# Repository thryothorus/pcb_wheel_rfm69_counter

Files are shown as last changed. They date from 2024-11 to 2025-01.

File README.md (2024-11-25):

# Wheel Counter, Battery Powered, RFM69 at 433MHz

## Objective
- Monitor how much critters are running on their wheels, at [The Creature Conservancy](http://www.thecreatureconservancy.org/).  Physical activity could correlate with health
- Create a wireless, battery powered, sensing network for additional sensors in the future

## Features
- NFC antenna for quick reading/changing of metadata (i.e. setting the animal name for transmission)
- RTC (Real Time Clock)
- N-MOSFET polarity protection
- Several debug switches
- TagConnect interface
  
### Schematic
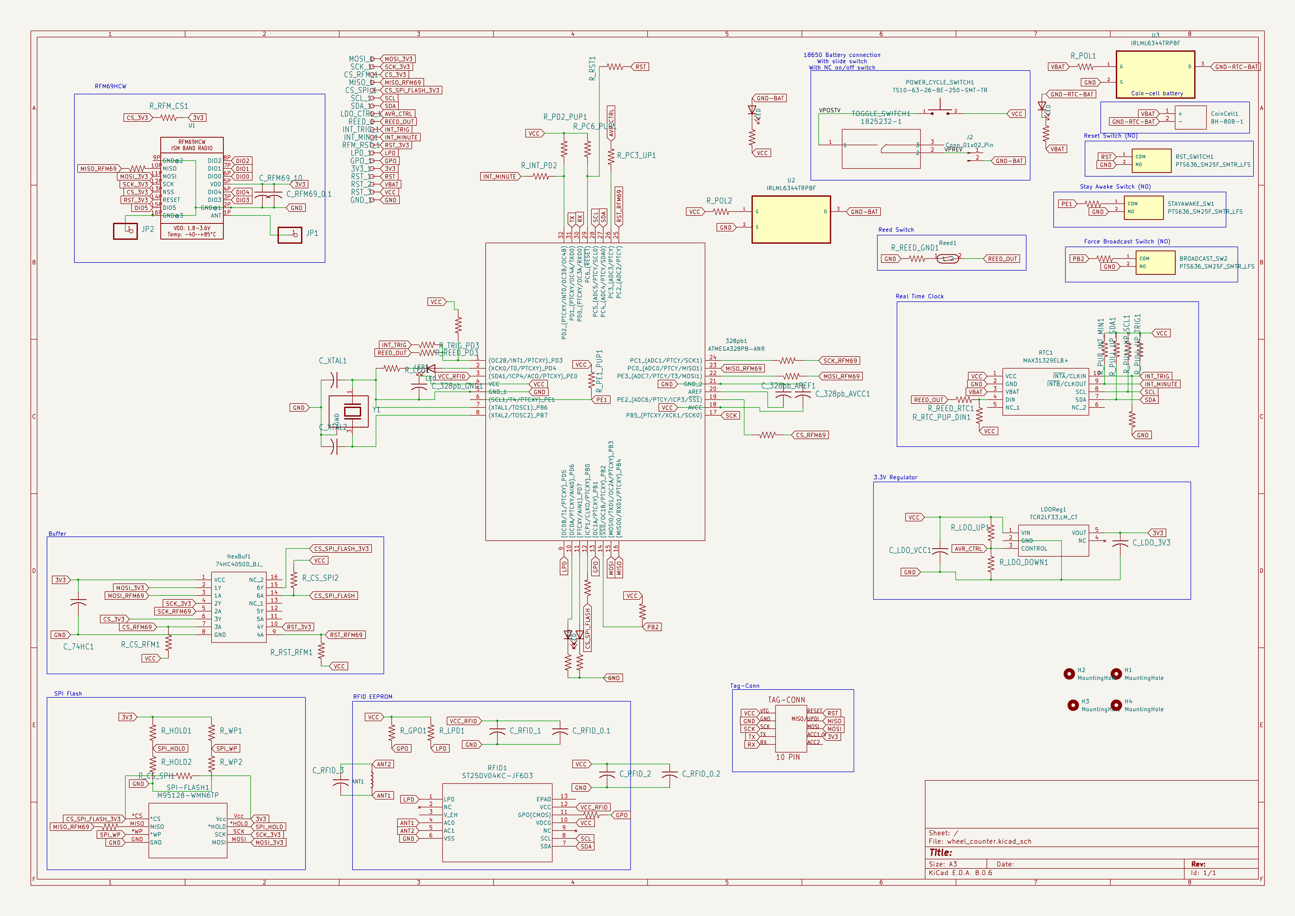
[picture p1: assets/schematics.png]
Schematic

### PCB
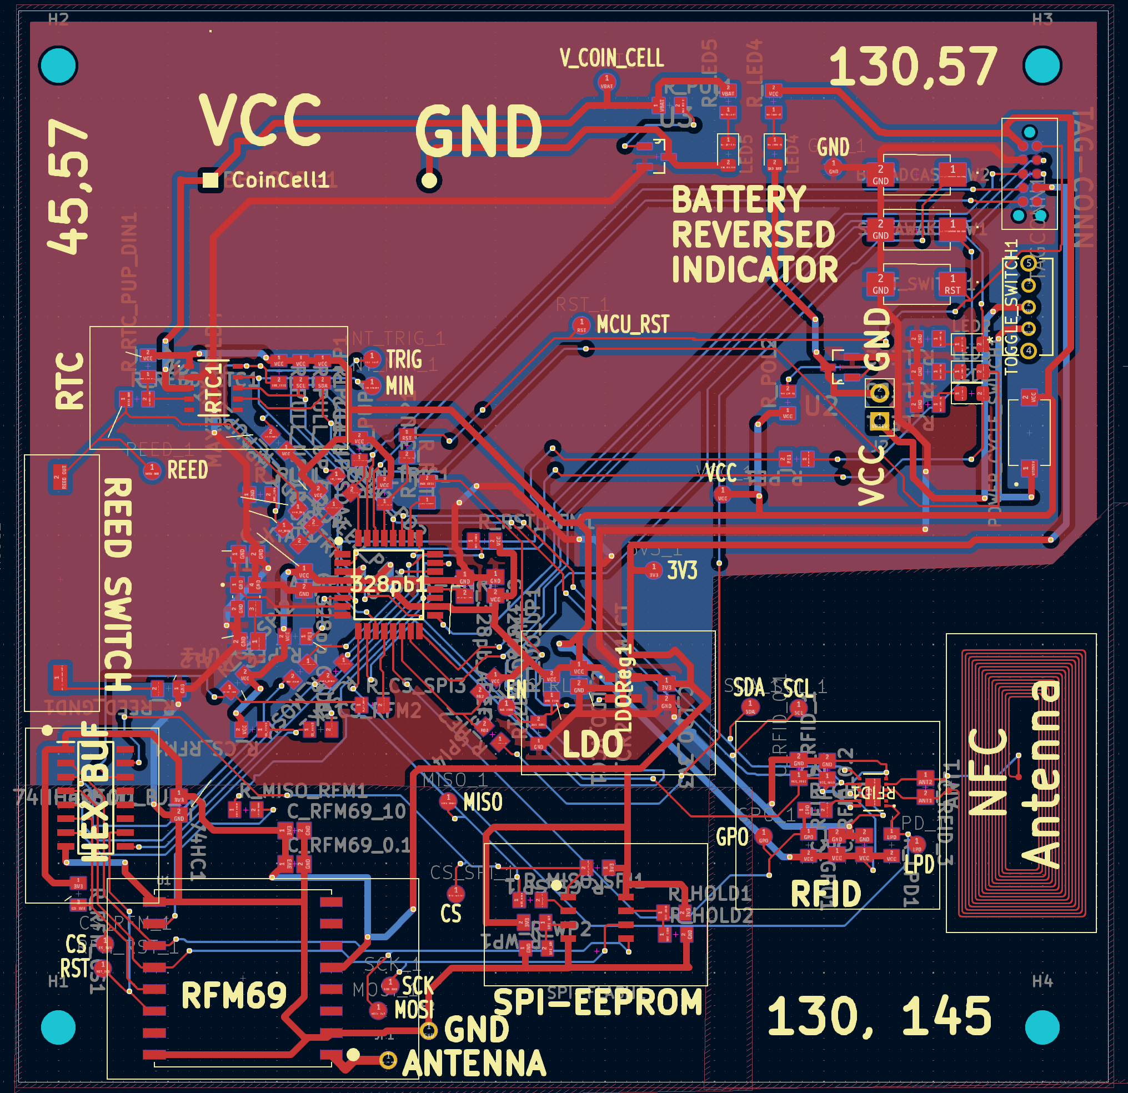
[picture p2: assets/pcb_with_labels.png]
PCB


## What's Next
- Populating PCB
- Writing code

## License: GPLv3 where not covered by other licenses

## Resources
NFC antenna design taken from [Sparkfun's implementation](https://www.sparkfun.com/products/21274)
Footprints from various sources online, including Sparkfun and Adafruit

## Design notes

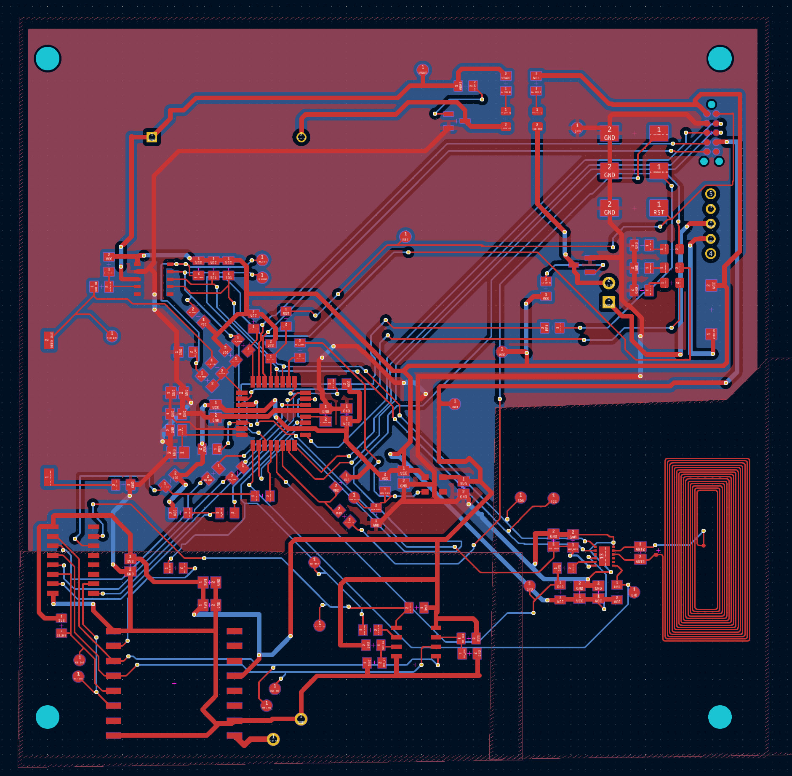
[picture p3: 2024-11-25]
pcb/assets/pcb_copper.png

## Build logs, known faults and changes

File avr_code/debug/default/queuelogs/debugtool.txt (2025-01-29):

1393 1738098146186 GEN4_TO_CONTROLLER_LOG:GEN4_CONNECT_INT_LOG Pre:SetLEDBrightness
1393 1738098146186 GEN4_TO_CONTROLLER_LOG:GEN4_CONNECT_INT_LOG Payload
1393 1738098146186 GEN4_TO_CONTROLLER_LOG:GEN4_CONNECT_INT_LOG 5
1393 1738098146186 GEN4_TO_CONTROLLER_LOG:GEN4_CONNECT_INT_LOG Payload End
1393 1738098146186 GEN4_TO_CONTROLLER_LOG:GEN4_CONNECT_INT_LOG Post:SetLEDBrightness
1393 1738098146186 GEN4_TO_CONTROLLER_LOG:GEN4_CONNECT_INT_LOG Return Value
1393 1738098146186 GEN4_TO_CONTROLLER_LOG:GEN4_CONNECT_INT_LOG none
1393 1738098146186 GEN4_TO_CONTROLLER_LOG:GEN4_CONNECT_INT_LOG Return End

1393 1738098146186 GEN4_TO_CONTROLLER_LOG:GEN4_CONNECT_INT_LOG Pre:SetToolInfo
1393 1738098146186 GEN4_TO_CONTROLLER_LOG:GEN4_CONNECT_INT_LOG Payload
1393 1738098146186 GEN4_TO_CONTROLLER_LOG:GEN4_CONNECT_INT_LOG ToolInfo: Values:
1393 1738098146186 GEN4_TO_CONTROLLER_LOG:GEN4_CONNECT_INT_LOG ToolInfo: speedLevel = 1, PGCResistance = 4700, PGDResistance = 4700, PGCPullDir = PullDown, PGDPullDir = PullDown, ICSPSelected = Wire2
1393 1738098146186 GEN4_TO_CONTROLLER_LOG:GEN4_CONNECT_INT_LOG Payload End
1393 1738098146186 GEN4_TO_CONTROLLER_LOG:GEN4_CONNECT_INT_LOG Post:SetToolInfo
1393 1738098146186 GEN4_TO_CONTROLLER_LOG:GEN4_CONNECT_INT_LOG Return Value
1393 1738098146186 GEN4_TO_CONTROLLER_LOG:GEN4_CONNECT_INT_LOG none
1393 1738098146186 GEN4_TO_CONTROLLER_LOG:GEN4_CONNECT_INT_LOG Return End

1393 1738098146187 GEN4_TO_CONTROLLER_LOG:GEN4_CONNECT_INT_LOG Pre:GetTargetIDInfo
1393 1738098146187 GEN4_TO_CONTROLLER_LOG:GEN4_CONNECT_INT_LOG Payload
1393 1738098146187 GEN4_TO_CONTROLLER_LOG:GEN4_CONNECT_INT_LOG null
1393 1738098146187 GEN4_TO_CONTROLLER_LOG:GEN4_CONNECT_INT_LOG Payload End
1393 1738098146187 NativeController::GetTargetIDInfo entry
1393 1738098146187 pro JtagIce3 [0x12] <<< 01 00 00 00 01 01 
1393 1738098146188 pro JtagIce3 [0x12] >>> 80 00 
1393 1738098146188 pro JtagIce3 [0x12] <<< 01 00 00 01 04 01 00 00 00 
1393 1738098146189 pro JtagIce3 [0x12] >>> 80 00 
1393 1738098146189 pro JtagIce3 [0x12] <<< 01 00 01 00 01 01 
1393 1738098146190 pro JtagIce3 [0x12] >>> 80 00 
1393 1738098146190 pro JtagIce3 [0x11] <<< 1D 7D 00 
1393 1738098146191 pro JtagIce3 [0x11] >>> 1D 00 
1393 1738098146191 pro JtagIce3 [0x11] <<< 10 C8 64 19 20 00 53 03 AC 53 00 00 
1393 1738098146273 pro JtagIce3 [0x11] >>> 10 00 
1393 1738098146273 pro JtagIce3 [0x11] <<< 1B 04 30 00 00 00 
1393 1738098146274 pro JtagIce3 [0x11] >>> 1B 00 1E 00 
1393 1738098146274 pro JtagIce3 [0x11] <<< 1B 04 30 00 01 00 
1393 1738098146275 pro JtagIce3 [0x11] >>> 1B 00 95 00 
1393 1738098146275 pro JtagIce3 [0x11] <<< 1B 04 30 00 02 00 
1393 1738098146276 pro JtagIce3 [0x11] >>> 1B 00 16 00 
1393 1738098146276 pro JtagIce3 [0x11] <<< 1B 04 30 00 00 00 
1393 1738098146277 pro JtagIce3 [0x11] >>> 1B 00 1E 00 
1393 1738098146277 pro JtagIce3 [0x11] <<< 1B 04 30 00 01 00 
1393 1738098146278 pro JtagIce3 [0x11] >>> 1B 00 95 00 
1393 1738098146278 pro JtagIce3 [0x11] <<< 1B 04 30 00 02 00 
1393 1738098146279 pro JtagIce3 [0x11] >>> 1B 00 16 00 
1393 1738098146279 pro JtagIce3 [0x11] <<< 1B 04 30 00 00 00 
1393 1738098146280 pro JtagIce3 [0x11] >>> 1B 00 1E 00 
1393 1738098146280 pro JtagIce3 [0x11] <<< 1B 04 30 00 01 00 
1393 1738098146281 pro JtagIce3 [0x11] >>> 1B 00 95 00 
1393 1738098146281 pro JtagIce3 [0x11] <<< 1B 04 30 00 02 00 
1393 1738098146282 pro JtagIce3 [0x11] >>> 1B 00 16 00 
1393 1738098146282 pro JtagIce3 [0x11] <<< 11 01 01 
1393 1738098146285 pro JtagIce3 [0x11] >>> 11 00 
1393 1738098146285 pro JtagIce3 [0x01] <<< 11 00 00 
1393 1738098146286 pro JtagIce3 [0x01] >>> 80 00 
1393 1738098146286 NativeController::GetTargetIDInfo exit device ID 0x1e9516
1393 1738098146286 GEN4_TO_CONTROLLER_LOG:GEN4_CONNECT_INT_LOG Post:GetTargetIDInfo
1393 1738098146286 GEN4_TO_CONTROLLER_LOG:GEN4_CONNECT_INT_LOG Return Value
1393 1738098146286 GEN4_TO_CONTROLLER_LOG:GEN4_CONNECT_INT_LOG TargetIDInfo: Values:
1393 1738098146286 GEN4_TO_CONTROLLER_LOG:GEN4_CONNECT_INT_LOG TargetIDInfo: DeviceID = 001e9516
1393 1738098146286 GEN4_TO_CONTROLLER_LOG:GEN4_CONNECT_INT_LOG Return End

1393 1738098146288 GEN4_TO_CONTROLLER_LOG:GEN4_PROGRAM_INT_LOG_ATmega328PB Pre:SendOperation
1393 1738098146288 GEN4_TO_CONTROLLER_LOG:GEN4_PROGRAM_INT_LOG_ATmega328PB Payload
1393 1738098146288 GEN4_TO_CONTROLLER_LOG:GEN4_PROGRAM_INT_LOG_ATmega328PB OperationInfo: Values:
1393 1738098146288 GEN4_TO_CONTROLLER_LOG:GEN4_PROGRAM_INT_LOG_ATmega328PB OperationInfo: Type = erase, Mask = 00000000, Erase = false, Production Mode = true
1393 1738098146288 GEN4_TO_CONTROLLER_LOG:GEN4_PROGRAM_INT_LOG_ATmega328PB TransferInfo: Start = 0, End = 7fff, Buffer Length = 0, Type = Pgm, Mask = 00000000
1393 1738098146288 GEN4_TO_CONTROLLER_LOG:GEN4_PROGRAM_INT_LOG_ATmega328PB TransferInfo: Start = 820000, End = 820002, Buffer Length = 0, Type = Cfg, Mask = 00000000
1393 1738098146288 GEN4_TO_CONTROLLER_LOG:GEN4_PROGRAM_INT_LOG_ATmega328PB TransferInfo: Start = 830000, End = 830000, Buffer Length = 0, Type = Cfg, Mask = 00000000
1393 1738098146288 GEN4_TO_CONTROLLER_LOG:GEN4_PROGRAM_INT_LOG_ATmega328PB TransferInfo: Start = 0, End = 3ff, Buffer Length = 0, Type = DataFlash, Mask = 00000000
1393 1738098146288 GEN4_TO_CONTROLLER_LOG:GEN4_PROGRAM_INT_LOG_ATmega328PB Payload End
1393 1738098146288 pro JtagIce3 [0x12] <<< 01 00 00 00 01 01 
1393 1738098146289 pro JtagIce3 [0x12] >>> 80 00 
1393 1738098146289 pro JtagIce3 [0x12] <<< 01 00 00 01 04 01 00 00 00 
1393 1738098146290 pro JtagIce3 [0x12] >>> 80 00 
1393 1738098146290 pro JtagIce3 [0x12] <<< 01 00 01 00 01 01 
1393 1738098146291 pro JtagIce3 [0x12] >>> 80 00 
1393 1738098146291 pro JtagIce3 [0x11] <<< 1D 7D 00 
1393 1738098146292 pro JtagIce3 [0x11] >>> 1D 00 
1393 1738098146292 pro JtagIce3 [0x11] <<< 10 C8 64 19 20 00 53 03 AC 53 00 00 
1393 1738098146375 pro JtagIce3 [0x11] >>> 10 00 
1393 1738098146375 pro JtagIce3 [0x11] <<< 1B 04 30 00 00 00 
1393 1738098146376 pro JtagIce3 [0x11] >>> 1B 00 1E 00 
1393 1738098146376 pro JtagIce3 [0x11] <<< 1B 04 30 00 01 00 
1393 1738098146377 pro JtagIce3 [0x11] >>> 1B 00 95 00 
1393 1738098146378 pro JtagIce3 [0x11] <<< 1B 04 30 00 02 00 
1393 1738098146379 pro JtagIce3 [0x11] >>> 1B 00 16 00 
1393 1738098146379 pro JtagIce3 [0x11] <<< 12 2D 01 AC 80 00 00 
1393 1738098146391 pro JtagIce3 [0x11] >>> 12 00 
1393 1738098146391 pro JtagIce3 [0x11] <<< 18 04 58 08 00 00 
1393 1738098146392 pro JtagIce3 [0x11] >>> 18 00 DF 00 
1393 1738098146442 pro JtagIce3 [0x11] <<< 17 AC A8 00 DF 
1393 1738098146443 pro JtagIce3 [0x11] >>> 17 00 
1393 1738098146469 pro JtagIce3 [0x11] <<< 12 2D 01 AC 80 00 00 
1393 1738098146480 pro JtagIce3 [0x11] >>> 12 00 
1393 1738098146480 GEN4_TO_CONTROLLER_LOG:GEN4_PROGRAM_INT_LOG_ATmega328PB Post:SendOperation
1393 1738098146480 GEN4_TO_CONTROLLER_LOG:GEN4_PROGRAM_INT_LOG_ATmega328PB Return Value
1393 1738098146480 GEN4_TO_CONTROLLER_LOG:GEN4_PROGRAM_INT_LOG_ATmega328PB None
1393 1738098146480 GEN4_TO_CONTROLLER_LOG:GEN4_PROGRAM_INT_LOG_ATmega328PB Return End

1393 1738098146481 GEN4_TO_CONTROLLER_LOG:GEN4_PROGRAM_INT_LOG_ATmega328PB Pre:SendOperation
1393 1738098146481 GEN4_TO_CONTROLLER_LOG:GEN4_PROGRAM_INT_LOG_ATmega328PB Payload
1393 1738098146481 GEN4_TO_CONTROLLER_LOG:GEN4_PROGRAM_INT_LOG_ATmega328PB OperationInfo: Values:
1393 1738098146481 GEN4_TO_CONTROLLER_LOG:GEN4_PROGRAM_INT_LOG_ATmega328PB OperationInfo: Type = write, Mask = 00000000, Erase = false, Production Mode = true
1393 1738098146481 GEN4_TO_CONTROLLER_LOG:GEN4_PROGRAM_INT_LOG_ATmega328PB TransferInfo: Start = 0, End = 207f, Buffer Length = 8320, Type = Pgm, Mask = 00000000
1393 1738098146481 GEN4_TO_CONTROLLER_LOG:GEN4_PROGRAM_INT_LOG_ATmega328PB Payload End
1393 1738098146481 pro JtagIce3 [0x11] <<< 06 00 00 00 00 
1393 1738098146482 pro JtagIce3 [0x11] >>> 06 00 
1393 1738098146482 pro JtagIce3 [0x11] <<< 13 00 80 C1 0A 40 4C 20 00 00 0C 94 5A 00 0C 94 43 0A 0C 94 49 0A 0C 94 77 00 0C 94 77 00 0C 94 77 00 0C 94 78 0A 0C 94 77 00 0C 94 77 00 0C 94 77 00 0C 94 77 00 0C 94 77 00 0C 94 77 00 0C 94 77 00 0C 94 77 00 0C 94 77 00 0C 94 77 00 0C 94 77 00 0C 94 77 00 0C 94 77 00 0C 94 77 00 0C 94 77 00 0C 94 77 00 0C 94 77 00 0C 94 77 00 0C 94 77 00 0C 94 77 00 0C 94 77 00 0C 94 77 00 0C 94 77 00 0C 94 77 00 0C 94 77 00 
1393 1738098146516 pro JtagIce3 [0x11] >>> 13 00 
1393 1738098146516 pro JtagIce3 [0x11] <<< 06 00 00 00 40 
1393 1738098146517 pro JtagIce3 [0x11] >>> 06 00 
1393 1738098146517 pro JtagIce3 [0x11] <<< 13 00 80 C1 0A 40 4C 20 00 00 0C 94 77 00 0C 94 77 00 0C 94 77 00 0C 94 77 00 0C 94 77 00 0C 94 77 00 0C 94 77 00 0C 94 77 00 0C 94 77 00 0C 94 77 00 0C 94 77 00 0C 94 77 00 0C 94 77 00 11 24 1F BE CF EF D8 E0 DE BF CD BF 11 E0 A0 E0 B1 E0 E2 E6 FF E1 02 C0 05 90 0D 92 A6 3B B1 07 D9 F7 26 E0 A6 EB B1 E0 01 C0 1D 92 A9 33 B2 07 E1 F7 0E 94 D3 0A 0C 94 AF 0F 0C 94 00 00 E0 EC F0 E0 80 81 86 FF FD CF E0 EC F0 E0 
1393 1738098146552 pro JtagIce3 [0x11] >>> 13 00 
1393 1738098146552 pro JtagIce3 [0x11] <<< 06 00 00 00 80 
1393 1738098146553 pro JtagIce3 [0x11] >>> 06 00 
1393 1738098146553 pro JtagIce3 [0x11] <<< 13 00 80 C1 0A 40 4C 20 00 00 80 81 80 64 80 83 08 95 10 92 C5 00 8C E0 80 93 C4 00 88 E1 80 93 C1 00 86 E0 80 93 C2 00 08 95 E0 EC F0 E0 90 81 95 FF FD CF 80 93 C6 00 08 95 CF 93 DF 93 C8 2F D9 2F 88 81 81 15 31 F0 21 96 0E 94 90 00 89 91 81 11 FB CF DF 91 CF 91 08 95 5F 92 6F 92 7F 92 8F 92 9F 92 AF 92 BF 92 CF 92 DF 92 EF 92 FF 92 0F 93 1F 93 CF 93 DF 93 C8 2E D9 2E E6 2E F7 2E 54 2E 65 2E 8B E5 0E 94 90 00 
1393 1738098146587 pro JtagIce3 [0x11] >>> 13 00 
1393 1738098146587 pro JtagIce3 [0x11] <<< 06 00 00 00 C0 
1393 1738098146588 pro JtagIce3 [0x11] >>> 06 00 
1393 1738098146588 pro JtagIce3 [0x11] <<< 13 00 80 C1 0A 40 4C 20 00 00 E1 14 F1 04 B1 F1 56 01 AE 0C BF 1C 46 01 00 E0 11 E0 68 94 77 24 74 F8 C6 EB D1 E0 21 E0 E2 1A F1 08 03 C0 8A 14 9B 04 21 F1 F4 01 81 91 4F 01 1F 92 8F 93 1F 93 0F 93 1F 92 7F 92 DF 93 CF 93 0E 94 B6 0C CE 01 0E 94 98 00 C4 01 8C 19 9D 09 01 97 ED B7 FE B7 38 96 0F B6 F8 94 FE BF 0F BE ED BF 8E 15 9F 05 F0 F6 83 E0 91 E0 0E 94 98 00 D9 CF 8D E5 0E 94 90 00 85 E0 91 E0 0E 94 98 00 
1393 1738098146623 pro JtagIce3 [0x11] >>> 13 00 
1393 1738098146623 pro JtagIce3 [0x11] <<< 06 00 00 01 00 
1393 1738098146624 pro JtagIce3 [0x11] >>> 06 00 
1393 1738098146624 pro JtagIce3 [0x11] <<< 13 00 80 C1 0A 40 4C 20 00 00 85 2D 96 2D 0E 94 98 00 89 E7 91 E0 0E 94 98 00 DF 91 CF 91 1F 91 0F 91 FF 90 EF 90 DF 90 CF 90 BF 90 AF 90 9F 90 8F 90 7F 90 6F 90 5F 90 08 95 1F 93 CF 93 DF 93 18 2F D6 2F C7 2F 86 E0 91 E0 0E 94 98 00 1F 92 1F 93 80 E0 91 E0 9F 93 8F 93 1F 92 80 E1 8F 93 86 EB 91 E0 9F 93 8F 93 0E 94 B6 0C 86 EB 91 E0 0E 94 98 00 88 E0 91 E0 0E 94 98 00 8D 2F 9C 2F 0E 94 98 00 89 E7 91 E0 0E 94 
1393 1738098146658 pro JtagIce3 [0x11] >>> 13 00 
1393 1738098146658 pro JtagIce3 [0x11] <<< 06 00 00 01 40 
1393 1738098146659 pro JtagIce3 [0x11] >>> 06 00 
1393 1738098146659 pro JtagIce3 [0x11] <<< 13 00 80 C1 0A 40 4C 20 00 00 98 00 8D B7 9E B7 08 96 0F B6 F8 94 9E BF 0F BE 8D BF DF 91 CF 91 1F 91 08 95 CF 93 DF 93 CD B7 DE B7 6A E0 71 E0 8D 81 0E 94 18 01 61 E1 71 E0 8E 81 0E 94 18 01 64 E1 71 E0 8F 81 0E 94 18 01 69 E1 71 E0 88 85 0E 94 18 01 6F E1 71 E0 89 85 0E 94 18 01 6D 81 70 E0 45 E2 51 E0 CE 01 0A 96 0E 94 A8 00 DF 91 CF 91 08 95 EF 92 FF 92 0F 93 1F 93 CF 93 DF 93 E8 2E F9 2E 4C E3 50 E0 60 E2 
1393 1738098146694 pro JtagIce3 [0x11] >>> 13 00 
1393 1738098146694 pro JtagIce3 [0x11] <<< 06 00 00 01 80 
1393 1738098146695 pro JtagIce3 [0x11] >>> 06 00 
1393 1738098146695 pro JtagIce3 [0x11] <<< 13 00 80 C1 0A 40 4C 20 00 00 70 E0 8F EC 91 E0 0E 94 A4 0C 81 E0 0E 94 CB 05 80 E0 0E 94 D2 05 0E 94 DC 05 CA EC D1 E0 84 50 88 83 0E 94 DC 05 89 83 0E 94 DC 05 8A 83 0E 94 DC 05 8B 83 0E 94 DC 05 8C 83 08 81 01 15 59 F0 CF EC D1 E0 10 E0 01 53 1E 4F 0E 94 DC 05 89 93 C0 17 D1 07 D1 F7 80 E0 0E 94 CB 05 81 E4 EA EC F1 E0 AE 2D BF 2D 01 90 0D 92 8A 95 E1 F7 8E 2D 9F 2D DF 91 CF 91 1F 91 0F 91 FF 90 EF 90 08 95 
1393 1738098146729 pro JtagIce3 [0x11] >>> 13 00 
1393 1738098146729 pro JtagIce3 [0x11] <<< 06 00 00 01 C0 
1393 1738098146730 pro JtagIce3 [0x11] >>> 06 00 
1393 1738098146730 pro JtagIce3 [0x11] <<< 13 00 80 C1 0A 40 4C 20 00 00 CF 93 C8 2F 81 E0 0E 94 CB 05 8C 2F 0E 94 D2 05 8F EF 90 E0 0E 94 DC 05 C8 2F 80 E0 0E 94 CB 05 8C 2F CF 91 08 95 CF 93 DF 93 D8 2F C6 2F 81 E0 0E 94 CB 05 8D 2F 80 68 0E 94 D2 05 8C 2F 0E 94 D2 05 C8 2F 80 E0 0E 94 CB 05 8C 2F DF 91 CF 91 08 95 FF 92 0F 93 1F 93 CF 93 DF 93 08 2F C6 2F D7 2F 14 2F 81 E0 0E 94 CB 05 80 2F 80 68 0E 94 D2 05 F8 2E 0F EF 01 0F 11 15 69 F0 10 E0 0F 5F 
1393 1738098146764 pro JtagIce3 [0x11] >>> 13 00 
1393 1738098146765 pro JtagIce3 [0x11] <<< 06 00 00 02 00 
1393 1738098146766 pro JtagIce3 [0x11] >>> 06 00 
1393 1738098146766 pro JtagIce3 [0x11] <<< 13 00 80 C1 0A 40 4C 20 00 00 1F 4F 0C 0F 1D 1F FE 01 21 96 80 81 0E 94 D2 05 C0 17 D1 07 C1 F7 80 E0 0E 94 CB 05 8F 2D DF 91 CF 91 1F 91 0F 91 FF 90 08 95 CF 92 DF 92 EF 92 FF 92 0F 93 1F 93 CF 93 DF 93 06 2F 10 92 0B 02 61 15 09 F4 42 C0 C8 2F D9 2F 40 E0 50 E0 BA 01 10 E0 CC 24 CA 94 DC 2C EC 2C F1 2C 29 91 DB 01 CA 01 88 0F 99 1F AA 1F BB 1F 88 0F 99 1F AA 1F BB 1F 88 0F 99 1F AA 1F BB 1F 88 0F 99 1F AA 1F 
1393 1738098146800 pro JtagIce3 [0x11] >>> 13 00 
1393 1738098146800 pro JtagIce3 [0x11] <<< 06 00 00 02 40 
1393 1738098146801 pro JtagIce3 [0x11] >>> 06 00 
1393 1738098146801 pro JtagIce3 [0x11] <<< 13 00 80 C1 0A 40 4C 20 00 00 BB 1F 88 0F 99 1F AA 1F BB 1F 84 1B 95 0B A6 0B B7 0B BC 01 CD 01 62 0F 71 1D 81 1D 91 1D A7 01 96 01 0E 94 79 0C AB 01 BC 01 1F 5F 10 93 0B 02 10 13 D4 CF CB 01 BA 01 DF 91 CF 91 1F 91 0F 91 FF 90 EF 90 DF 90 CF 90 08 95 40 E0 50 E0 BA 01 F1 CF 6D E5 8A E5 0E 94 D3 01 6C E7 8C E5 0E 94 D3 01 08 95 65 E5 8A E5 0E 94 D3 01 60 E7 8C E5 0E 94 D3 01 08 95 E8 2F F9 2F 10 82 8F EF 81 83 
1393 1738098146835 pro JtagIce3 [0x11] >>> 13 00 
1393 1738098146836 pro JtagIce3 [0x11] <<< 06 00 00 02 80 
1393 1738098146836 pro JtagIce3 [0x11] >>> 06 00 
1393 1738098146837 pro JtagIce3 [0x11] <<< 13 00 80 C1 0A 40 4C 20 00 00 82 83 13 82 14 82 4C E3 50 E0 60 E2 70 E0 CF 01 05 96 0E 94 A4 0C 08 95 CF 92 DF 92 EF 92 FF 92 0F 93 1F 93 CF 93 DF 93 CD B7 DE B7 08 2F 19 2F CB 5E DE 4F C8 80 C5 51 D1 40 CA 5E DE 4F D8 80 C6 51 D1 40 C9 5E DE 4F E8 80 C7 51 D1 40 C8 5E DE 4F F8 80 C8 51 D1 40 8A EC 91 E0 0E 94 7B 02 4B 85 4B 30 08 F0 4A E0 50 E0 BE 01 64 5F 7F 4F 8F EC 91 E0 0E 94 9B 0C C4 5F DE 4F 48 81 CC 50 
1393 1738098146871 pro JtagIce3 [0x11] >>> 13 00 
1393 1738098146871 pro JtagIce3 [0x11] <<< 06 00 00 02 C0 
1393 1738098146872 pro JtagIce3 [0x11] >>> 06 00 
1393 1738098146872 pro JtagIce3 [0x11] <<< 13 00 80 C1 0A 40 4C 20 00 00 D1 40 4B 30 08 F0 4A E0 50 E0 BE 01 64 57 7F 4F 89 ED 91 E0 0E 94 9B 0C EA EC F1 E0 C1 8E D2 8E C1 5F DE 4F 88 81 CF 50 D1 40 83 8F C0 5F DE 4F 88 81 C0 51 D1 40 84 8F CE 5E DE 4F 88 81 C2 51 D1 40 85 8F CD 5E DE 4F 88 81 C3 51 D1 40 86 8F CC 5E DE 4F 88 81 C4 51 D1 40 87 8F AE 2D BF 2D EA EE F1 E0 48 E0 52 E0 2D 91 3C 91 11 97 20 83 2D 91 3D 91 31 83 32 96 E4 17 F5 07 A9 F7 69 E3 
1393 1738098146906 pro JtagIce3 [0x11] >>> 13 00 
1393 1738098146906 pro JtagIce3 [0x11] <<< 06 00 00 03 00 
1393 1738098146907 pro JtagIce3 [0x11] >>> 06 00 
1393 1738098146907 pro JtagIce3 [0x11] <<< 13 00 80 C1 0A 40 4C 20 00 00 8F EC 91 E0 0E 94 15 02 60 93 C6 01 70 93 C7 01 80 93 C8 01 90 93 C9 01 EA EC F1 E0 66 AF 77 AF 80 93 0A 02 8C E3 80 83 8F E1 84 83 C3 5F DE 4F 88 81 CD 50 D1 40 82 83 8F EF 81 83 82 E0 83 83 81 E4 A0 2F B1 2F 01 90 0D 92 8A 95 E1 F7 80 2F 91 2F DF 91 CF 91 1F 91 0F 91 FF 90 EF 90 DF 90 CF 90 08 95 CF 93 C8 2F 81 E0 0E 94 C0 01 68 2F 63 7E CC 71 6C 2B 81 E0 0E 94 D3 01 CF 91 08 95 
1393 1738098146942 pro JtagIce3 [0x11] >>> 13 00 
1393 1738098146942 pro JtagIce3 [0x11] <<< 06 00 00 03 40 
1393 1738098146943 pro JtagIce3 [0x11] >>> 06 00 
1393 1738098146943 pro JtagIce3 [0x11] <<< 13 00 80 C1 0A 40 4C 20 00 00 88 E2 0E 94 C0 01 83 FF FB CF 08 95 CF 93 E8 2F F9 2F C6 2F 90 81 91 15 D1 F0 31 96 20 E0 30 E0 5F E1 52 9F D0 01 53 9F B0 0D 11 24 9D 01 29 0F 31 1D 91 91 91 11 F5 CF 4C 1B 55 0B BA 01 6F 5F 7F 4F C9 01 0E 94 51 0C 8C 0F CF 91 08 95 20 E0 30 E0 F2 CF 87 E2 0E 94 C0 01 81 15 DC F7 08 95 0E 94 69 02 8C E0 0E 94 32 03 0E 94 6A 03 08 95 0E 94 72 02 80 E1 0E 94 32 03 0E 94 6A 03 08 95 
1393 1738098146977 pro JtagIce3 [0x11] >>> 13 00 
1393 1738098146977 pro JtagIce3 [0x11] <<< 06 00 00 03 80 
1393 1738098146978 pro JtagIce3 [0x11] >>> 06 00 
1393 1738098146978 pro JtagIce3 [0x11] <<< 13 00 80 C1 0A 40 4C 20 00 00 EF 92 FF 92 0F 93 1F 93 CF 93 DF 93 CD B7 DE B7 19 85 0E 94 78 03 0E 94 70 03 81 E0 0E 94 CB 05 80 E8 0E 94 D2 05 01 2F 1D 33 08 F0 0C E3 84 E0 80 0F 0E 94 D2 05 8A 85 0E 94 D2 05 8B 85 0E 94 D2 05 8C 85 0E 94 D2 05 8D 85 0E 94 D2 05 11 15 69 F0 7E 01 8E E0 E8 0E F1 1C 10 E0 F7 01 81 91 7F 01 0E 94 D2 05 1F 5F 10 17 C0 F3 80 E0 0E 94 CB 05 0E 94 40 03 0E 94 78 03 DF 91 CF 91 1F 91 
1393 1738098147012 pro JtagIce3 [0x11] >>> 13 00 
1393 1738098147012 pro JtagIce3 [0x11] <<< 06 00 00 03 C0 
1393 1738098147014 pro JtagIce3 [0x11] >>> 06 00 
1393 1738098147014 pro JtagIce3 [0x11] <<< 13 00 80 C1 0A 40 4C 20 00 00 0F 91 FF 90 EF 90 08 95 0F 93 1F 93 CF 93 DF 93 08 2F 19 2F 0E 94 78 03 C2 E0 D0 E0 8F EC 97 E0 01 97 F1 F7 00 C0 00 00 0C 17 1D 07 40 F0 88 E2 0E 94 C0 01 21 96 82 FF F1 CF 81 E0 01 C0 80 E0 DF 91 CF 91 1F 91 0F 91 08 95 0E 94 72 02 84 E0 0E 94 32 03 0E 94 6A 03 08 95 81 E0 0E 94 72 04 8F E1 9E E4 01 97 F1 F7 00 C0 00 00 80 E0 0E 94 72 04 8F E1 9E E4 01 97 F1 F7 00 C0 00 00 08 95 
1393 1738098147048 pro JtagIce3 [0x11] >>> 13 00 
1393 1738098147048 pro JtagIce3 [0x11] <<< 06 00 00 04 00 
1393 1738098147049 pro JtagIce3 [0x11] >>> 06 00 
1393 1738098147049 pro JtagIce3 [0x11] <<< 13 00 80 C1 0A 40 4C 20 00 00 CF 93 DF 93 00 D0 CD B7 DE B7 0E 94 ED 03 2F EF 80 E7 92 E0 21 50 80 40 90 40 E1 F7 00 C0 00 00 0E 94 E5 03 6C E6 87 E0 0E 94 D3 01 60 E8 88 E0 0E 94 D3 01 60 E0 89 E0 0E 94 D3 01 60 E1 85 E0 0E 94 D3 01 6F E8 8C E3 0E 94 D3 01 60 E3 8F E6 0E 94 D3 01 8D E2 94 ED 9A 83 89 83 42 E0 BE 01 6F 5F 7F 4F 8F E2 0E 94 E9 01 68 E8 8E E2 0E 94 D3 01 61 E0 82 E0 0E 94 D3 01 60 E0 83 E0 0E 94 
1393 1738098147083 pro JtagIce3 [0x11] >>> 13 00 
1393 1738098147083 pro JtagIce3 [0x11] <<< 06 00 00 04 40 
1393 1738098147084 pro JtagIce3 [0x11] >>> 06 00 
1393 1738098147084 pro JtagIce3 [0x11] <<< 13 00 80 C1 0A 40 4C 20 00 00 D3 01 60 E8 84 E0 0E 94 D3 01 60 E1 86 E0 0E 94 D3 01 60 E0 86 E0 0E 94 D3 01 60 EE 89 E1 0E 94 D3 01 60 EE 8A E1 0E 94 D3 01 60 ED 87 E3 0E 94 D3 01 60 E0 8C E2 0E 94 D3 01 64 E0 8D E2 0E 94 D3 01 6F E7 81 E1 0E 94 D3 01 0F 90 0F 90 DF 91 CF 91 08 95 39 9A 6B 9A 38 98 40 9A 80 E5 80 93 AC 00 08 95 3A 9A 81 15 11 F0 42 9A 08 95 42 98 08 95 3B 9A 81 15 11 F0 43 9A 08 95 43 98 08 95 
1393 1738098147119 pro JtagIce3 [0x11] >>> 13 00 
1393 1738098147119 pro JtagIce3 [0x11] <<< 06 00 00 04 80 
1393 1738098147120 pro JtagIce3 [0x11] >>> 06 00 
1393 1738098147120 pro JtagIce3 [0x11] <<< 13 00 80 C1 0A 40 4C 20 00 00 10 92 B9 00 8C E0 80 93 B8 00 84 E0 80 93 BC 00 08 95 94 EA 90 93 BC 00 EC EB F0 E0 90 81 91 15 EC F7 80 93 BB 00 84 E8 80 93 BC 00 EC EB F0 E0 80 81 81 15 EC F7 90 91 B9 00 98 7F 98 31 31 F0 81 E0 90 34 09 F0 08 95 80 E0 08 95 80 E0 08 95 84 E9 80 93 BC 00 EC EB F0 E0 80 81 84 FF FD CF 08 95 84 EC 80 93 BC 00 EC EB F0 E0 80 81 81 15 EC F7 80 91 BB 00 08 95 80 93 BB 00 84 E8 80 93 
1393 1738098147154 pro JtagIce3 [0x11] >>> 13 00 
1393 1738098147154 pro JtagIce3 [0x11] <<< 06 00 00 04 C0 
1393 1738098147155 pro JtagIce3 [0x11] >>> 06 00 
1393 1738098147155 pro JtagIce3 [0x11] <<< 13 00 80 C1 0A 40 4C 20 00 00 BC 00 EC EB F0 E0 80 81 81 15 EC F7 90 91 B9 00 98 7F 81 E0 98 32 09 F0 08 95 80 E0 08 95 EF 92 FF 92 0F 93 1F 93 CF 93 DF 93 C6 2F 04 2F 15 2F E2 2E 88 0F 0E 94 89 04 F8 2E 81 15 51 F0 FF 24 F3 94 8F 2D DF 91 CF 91 1F 91 0F 91 FF 90 EF 90 08 95 8C 2F 0E 94 BC 04 E1 14 49 F0 E8 01 0E 0D 11 1D 89 91 0E 94 BC 04 C0 17 D1 07 D1 F7 0E 94 A8 04 E7 CF CF 93 DF 93 0F 92 CD B7 DE B7 49 83 
1393 1738098147189 pro JtagIce3 [0x11] >>> 13 00 
1393 1738098147189 pro JtagIce3 [0x11] <<< 06 00 00 05 00 
1393 1738098147190 pro JtagIce3 [0x11] >>> 06 00 
1393 1738098147190 pro JtagIce3 [0x11] <<< 13 00 80 C1 0A 40 4C 20 00 00 21 E0 AE 01 4F 5F 5F 4F 0E 94 CF 04 0F 90 DF 91 CF 91 08 95 84 E8 80 93 BC 00 EC EB F0 E0 80 81 81 15 EC F7 80 91 BB 00 08 95 AF 92 BF 92 DF 92 EF 92 FF 92 0F 93 1F 93 CF 93 DF 93 C8 2F F6 2E 04 2F 15 2F D2 2F 88 0F 0E 94 89 04 DD 24 D3 94 81 15 59 F0 8D 2D DF 91 CF 91 1F 91 0F 91 FF 90 EF 90 DF 90 BF 90 AF 90 08 95 8F 2D 0E 94 BC 04 8C 2F 88 0F 81 60 0E 94 89 04 D8 2E 81 11 1E C0 
1393 1738098147225 pro JtagIce3 [0x11] >>> 13 00 
1393 1738098147225 pro JtagIce3 [0x11] <<< 06 00 00 05 40 
1393 1738098147226 pro JtagIce3 [0x11] >>> 06 00 
1393 1738098147226 pro JtagIce3 [0x11] <<< 13 00 80 C1 0A 40 4C 20 00 00 8D 2F 81 50 99 0B 5C 01 D2 30 60 F0 CD 2D 78 01 EC 0E F1 1C 0E 94 B1 04 F7 01 80 83 CF 5F CA 15 1B 04 AC F3 8D 2F 81 50 99 0B 08 0F 19 1F 0E 94 0A 05 F8 01 80 83 0E 94 A8 04 CC CF DD 24 D3 94 C9 CF 21 E0 0E 94 15 05 08 95 CF 93 DF 93 0F 92 CD B7 DE B7 AE 01 4F 5F 5F 4F 0E 94 61 05 89 81 0F 90 DF 91 CF 91 08 95 AF 92 BF 92 DF 92 EF 92 FF 92 0F 93 1F 93 CF 93 DF 93 C8 2F F6 2E E7 2E 
1393 1738098147260 pro JtagIce3 [0x11] >>> 13 00 
1393 1738098147260 pro JtagIce3 [0x11] <<< 06 00 00 05 80 
1393 1738098147261 pro JtagIce3 [0x11] >>> 06 00 
1393 1738098147261 pro JtagIce3 [0x11] <<< 13 00 80 C1 0A 40 4C 20 00 00 04 2F 15 2F D2 2F 88 0F 0E 94 89 04 DD 24 D3 94 81 15 59 F0 8D 2D DF 91 CF 91 1F 91 0F 91 FF 90 EF 90 DF 90 BF 90 AF 90 08 95 8E 2D 0E 94 BC 04 8F 2D 0E 94 BC 04 8C 2F 88 0F 81 60 0E 94 89 04 D8 2E 81 11 1E C0 8D 2F 81 50 99 0B 5C 01 D2 30 60 F0 CD 2D 78 01 EC 0E F1 1C 0E 94 B1 04 F7 01 80 83 CF 5F CA 15 1B 04 AC F3 8D 2F 81 50 99 0B 08 0F 19 1F 0E 94 0A 05 F8 01 80 83 0E 94 A8 04 
1393 1738098147295 pro JtagIce3 [0x11] >>> 13 00 
1393 1738098147295 pro JtagIce3 [0x11] <<< 06 00 00 05 C0 
1393 1738098147296 pro JtagIce3 [0x11] >>> 06 00 
1393 1738098147296 pro JtagIce3 [0x11] <<< 13 00 80 C1 0A 40 4C 20 00 00 C9 CF DD 24 D3 94 C6 CF 20 9A 81 11 02 C0 28 9A 08 95 28 98 08 95 6A 9A 81 11 02 C0 72 9A 08 95 72 98 08 95 80 93 AE 00 ED EA F0 E0 80 81 81 15 EC F7 80 91 AE 00 08 95 8F EF 0E 94 D2 05 08 95 FF 92 0F 93 1F 93 CF 93 DF 93 18 2F D9 2F F6 2E 07 2F C4 2F 44 E1 50 E0 60 E2 70 E0 86 E2 93 E0 0E 94 A4 0C AF 2D B0 2F 50 E0 30 E0 03 C0 3F 5F 3C 17 60 F4 2D 91 21 15 49 F0 20 32 C1 F3 E5 2F 
1393 1738098147331 pro JtagIce3 [0x11] >>> 13 00 
1393 1738098147331 pro JtagIce3 [0x11] <<< 06 00 00 06 00 
1393 1738098147332 pro JtagIce3 [0x11] >>> 06 00 
1393 1738098147332 pro JtagIce3 [0x11] <<< 13 00 80 C1 0A 40 4C 20 00 00 F0 E0 EA 5D FC 4F 20 83 5F 5F F1 CF 25 2F 30 E0 30 93 3C 03 20 93 3B 03 87 E1 E6 E2 F3 E0 A1 2F BD 2F 01 90 0D 92 8A 95 E1 F7 81 2F 9D 2F DF 91 CF 91 1F 91 0F 91 FF 90 08 95 55 9A 81 15 11 F0 5D 9A 08 95 5D 98 08 95 68 9A 81 15 11 F0 70 9A 08 95 70 98 08 95 26 2F 64 2F 75 2F 48 2F 59 2F 83 E5 0E 94 74 05 08 95 0F 93 1F 93 CF 93 DF 93 CD B7 DE B7 CE 5F D1 09 0F B6 F8 94 DE BF 0F BE 
1393 1738098147366 pro JtagIce3 [0x11] >>> 13 00 
1393 1738098147366 pro JtagIce3 [0x11] <<< 06 00 00 06 40 
1393 1738098147367 pro JtagIce3 [0x11] >>> 06 00 
1393 1738098147367 pro JtagIce3 [0x11] <<< 13 00 80 C1 0A 40 4C 20 00 00 CD BF 08 2F 19 2F 80 E0 0E 94 1D 06 81 E0 0E 94 24 06 8F E1 9E E4 01 97 F1 F7 00 C0 00 00 44 E0 50 E0 6E EF CE 01 01 96 0E 94 2B 06 BE 01 6F 5F 7F 4F 80 2F 91 2F 0E 94 73 09 81 E0 0E 94 1D 06 80 2F 91 2F C2 50 DF 4F 0F B6 F8 94 DE BF 0F BE CD BF DF 91 CF 91 1F 91 0F 91 08 95 AF 92 BF 92 CF 92 DF 92 EF 92 FF 92 0F 93 1F 93 CF 93 DF 93 CD B7 DE B7 C8 51 D1 40 0F B6 F8 94 DE BF 0F BE 
1393 1738098147401 pro JtagIce3 [0x11] >>> 13 00 
1393 1738098147402 pro JtagIce3 [0x11] <<< 06 00 00 06 80 
1393 1738098147403 pro JtagIce3 [0x11] >>> 06 00 
1393 1738098147403 pro JtagIce3 [0x11] <<< 13 00 80 C1 0A 40 4C 20 00 00 CD BF E8 2E F9 2E CE 01 01 96 0E 94 34 06 CE 01 02 96 0E 94 98 00 89 E7 91 E0 0E 94 98 00 49 81 BE 01 6E 5F 7F 4F CE 01 8E 5F 9E 4F 0E 94 E0 05 87 E1 FE 01 EE 5F FE 4F AC E0 B2 E0 01 90 0D 92 8A 95 E1 F7 8C E0 92 E0 0E 94 98 00 89 E7 91 E0 0E 94 98 00 6C E2 70 E0 8C E0 92 E0 0E 94 AB 0C 08 2F 19 2F 01 15 11 05 09 F4 46 C0 0C 50 12 40 68 01 DD 24 0F 2E FC E0 AF 2E F2 E0 BF 2E F0 2D 
1393 1738098147437 pro JtagIce3 [0x11] >>> 13 00 
1393 1738098147437 pro JtagIce3 [0x11] <<< 06 00 00 06 C0 
1393 1738098147438 pro JtagIce3 [0x11] >>> 06 00 
1393 1738098147438 pro JtagIce3 [0x11] <<< 13 00 80 C1 0A 40 4C 20 00 00 A6 01 B5 01 84 E2 92 E0 0E 94 9B 0C F5 01 15 89 56 89 B6 01 63 5F 7D 4F 41 2F 84 EA 92 E0 0E 94 9B 0C 00 93 23 02 10 1B 10 93 24 03 4B E3 60 E0 84 E2 92 E0 0E 94 46 03 80 93 25 03 83 E0 91 E0 E3 E2 F2 E0 AE 2D BF 2D 01 90 0D 92 01 97 E1 F7 8E 2D 9F 2D C8 5E DE 4F 0F B6 F8 94 DE BF 0F BE CD BF DF 91 CF 91 1F 91 0F 91 FF 90 EF 90 DF 90 CF 90 BF 90 AF 90 08 95 EC E0 F2 E0 15 89 56 89 
1393 1738098147472 pro JtagIce3 [0x11] >>> 13 00 
1393 1738098147472 pro JtagIce3 [0x11] <<< 06 00 00 07 00 
1393 1738098147473 pro JtagIce3 [0x11] >>> 06 00 
1393 1738098147474 pro JtagIce3 [0x11] <<< 13 00 80 C1 0A 40 4C 20 00 00 41 2F BF 01 84 E2 92 E0 0E 94 9B 0C 10 93 23 02 E4 EA F2 E0 8E E4 9F E2 91 83 80 83 81 E4 82 83 13 E0 C2 CF 53 98 5B 98 08 95 E9 E6 F0 E0 80 81 88 60 80 83 80 81 8B 7F 80 83 E9 9A 08 95 E9 E6 F0 E0 80 81 82 60 80 83 80 81 8E 7F 80 83 E8 9A 08 95 F8 94 A8 95 E0 E6 F0 E0 80 81 88 61 80 83 85 E0 80 83 80 81 80 64 80 83 78 94 08 95 F8 94 E0 E6 F0 E0 80 81 88 61 80 83 10 82 78 94 08 95 
1393 1738098147508 pro JtagIce3 [0x11] >>> 13 00 
1393 1738098147508 pro JtagIce3 [0x11] <<< 06 00 00 07 40 
1393 1738098147509 pro JtagIce3 [0x11] >>> 06 00 
1393 1738098147509 pro JtagIce3 [0x11] <<< 13 00 80 C1 0A 40 4C 20 00 00 CF 93 DF 93 00 D0 0F 92 CD B7 DE B7 80 E8 89 83 8A 83 8B 83 23 E0 AE 01 4F 5F 5F 4F 63 E1 88 E6 0E 94 CF 04 0F 90 0F 90 0F 90 DF 91 CF 91 08 95 68 2F 88 E6 0E 94 65 05 08 95 80 E0 0E 94 58 07 08 95 81 E0 0E 94 58 07 08 95 4A E0 64 E0 88 E6 0E 94 FA 04 08 95 42 E0 61 E0 88 E6 0E 94 FA 04 08 95 48 2F 59 2F 27 E0 66 E0 88 E6 0E 94 15 05 08 95 CF 93 DF 93 00 D0 00 D0 00 D0 0F 92 CD B7 
1393 1738098147543 pro JtagIce3 [0x11] >>> 13 00 
1393 1738098147543 pro JtagIce3 [0x11] <<< 06 00 00 07 80 
1393 1738098147544 pro JtagIce3 [0x11] >>> 06 00 
1393 1738098147544 pro JtagIce3 [0x11] <<< 13 00 80 C1 0A 40 4C 20 00 00 DE B7 86 EC 93 E0 0E 94 71 07 A6 EC B3 E0 9C 91 EF EB F3 E0 89 2F 82 95 8F 70 28 2F 22 0F 22 0F 82 1B 88 0F 89 0F 80 83 11 96 9C 91 11 97 89 2F 82 95 8F 70 28 2F 22 0F 22 0F 82 1B 88 0F 89 0F 81 83 12 96 9C 91 12 97 89 2F 82 95 8F 70 8B 70 28 2F 22 0F 22 0F 82 1B 88 0F 9F 7B 89 0F 82 83 13 96 8C 91 13 97 83 83 14 96 9C 91 14 97 89 2F 82 95 8F 70 28 2F 22 0F 22 0F 82 1B 88 0F 89 0F 
1393 1738098147579 pro JtagIce3 [0x11] >>> 13 00 
1393 1738098147579 pro JtagIce3 [0x11] <<< 06 00 00 07 C0 
1393 1738098147580 pro JtagIce3 [0x11] >>> 06 00 
1393 1738098147580 pro JtagIce3 [0x11] <<< 13 00 80 C1 0A 40 4C 20 00 00 84 83 15 96 9C 91 15 97 89 2F 82 95 8F 70 87 70 28 2F 22 0F 22 0F 82 1B 88 0F 9F 77 89 0F 85 83 16 96 9C 91 89 2F 82 95 8F 70 28 2F 22 0F 22 0F 82 1B 88 0F 9E 51 89 0F 86 83 87 E0 DE 01 11 96 01 90 0D 92 8A 95 E1 F7 29 81 3A 81 4B 81 5C 81 6D 81 7E 81 8F 81 90 E0 27 96 0F B6 F8 94 DE BF 0F BE CD BF DF 91 CF 91 08 95 AF 92 BF 92 CF 92 DF 92 EF 92 FF 92 0F 93 1F 93 CF 93 DF 93 00 D0 
1393 1738098147614 pro JtagIce3 [0x11] >>> 13 00 
1393 1738098147614 pro JtagIce3 [0x11] <<< 06 00 00 08 00 
1393 1738098147615 pro JtagIce3 [0x11] >>> 06 00 
1393 1738098147615 pro JtagIce3 [0x11] <<< 13 00 80 C1 0A 40 4C 20 00 00 00 D0 00 D0 0F 92 CD B7 DE B7 A2 2E B3 2E C4 2E 5C 83 D6 2E E7 2E F8 2E 80 ED 0E 94 89 04 18 2F 81 15 99 F0 11 E0 81 2F 27 96 0F B6 F8 94 DE BF 0F BE CD BF DF 91 CF 91 1F 91 0F 91 FF 90 EF 90 DF 90 CF 90 BF 90 AF 90 08 95 86 E0 0E 94 BC 04 0D EC A0 9E 91 2D 11 24 96 95 96 95 96 95 89 2F 88 0F 89 0F 88 0F 8A 0D 0E 94 BC 04 B0 9E 91 2D 11 24 96 95 96 95 96 95 89 2F 88 0F 89 0F 88 0F 
1393 1738098147650 pro JtagIce3 [0x11] >>> 13 00 
1393 1738098147650 pro JtagIce3 [0x11] <<< 06 00 00 08 40 
1393 1738098147651 pro JtagIce3 [0x11] >>> 06 00 
1393 1738098147651 pro JtagIce3 [0x11] <<< 13 00 80 C1 0A 40 4C 20 00 00 8B 0D 0E 94 BC 04 C0 9E 91 2D 11 24 96 95 96 95 96 95 89 2F 88 0F 89 0F 88 0F 8C 0D 0E 94 BC 04 8C 81 0E 94 BC 04 D0 9E 91 2D 11 24 96 95 96 95 96 95 89 2F 88 0F 89 0F 88 0F 8D 0D 0E 94 BC 04 E0 9E 01 2D 11 24 06 95 06 95 06 95 80 2F 88 0F 80 0F 88 0F 8E 0D 0E 94 BC 04 8F 2D 90 E0 6A E0 70 E0 0E 94 65 0C 6D 5F 7F 4F 86 2F 88 0F 86 0F 88 0F 9E E1 9F 0D 89 0F 0E 94 BC 04 0E 94 A8 04 
1393 1738098147685 pro JtagIce3 [0x11] >>> 13 00 
1393 1738098147685 pro JtagIce3 [0x11] <<< 06 00 00 08 80 
1393 1738098147686 pro JtagIce3 [0x11] >>> 06 00 
1393 1738098147686 pro JtagIce3 [0x11] <<< 13 00 80 C1 0A 40 4C 20 00 00 92 CF CF 93 DF 93 CD B7 DE B7 C8 54 D1 09 0F B6 F8 94 DE BF 0F BE CD BF 0E 94 00 04 8F EC 97 E0 01 97 F1 F7 00 C0 00 00 8E E7 93 E0 0E 94 7B 02 2E 96 4F AD 2E 97 4B 30 08 F0 4A E0 50 E0 BE 01 62 5B 7F 4F 83 E8 93 E0 0E 94 9B 0C C2 5B DE 4F 48 81 CE 54 D1 40 4B 30 08 F0 4A E0 50 E0 BE 01 62 53 7F 4F 8D E8 93 E0 0E 94 9B 0C EE E7 F3 E0 84 E1 80 83 81 E0 84 83 83 83 8D B7 9E B7 81 54 
1393 1738098147720 pro JtagIce3 [0x11] >>> 13 00 
1393 1738098147720 pro JtagIce3 [0x11] <<< 06 00 00 08 C0 
1393 1738098147721 pro JtagIce3 [0x11] >>> 06 00 
1393 1738098147721 pro JtagIce3 [0x11] <<< 13 00 80 C1 0A 40 4C 20 00 00 91 09 0F B6 F8 94 9E BF 0F BE 8D BF AD B7 BE B7 11 96 81 E4 01 90 0D 92 8A 95 E1 F7 0E 94 80 03 0F B6 F8 94 DE BF 0F BE CD BF 84 E6 90 E0 0E 94 C4 03 81 15 09 F4 47 C0 CE 01 08 96 0E 94 75 01 81 E4 FE 01 38 96 AD E3 B3 E0 01 90 0D 92 8A 95 E1 F7 80 91 41 03 82 30 59 F0 82 E0 C8 5B DF 4F 0F B6 F8 94 DE BF 0F BE CD BF DF 91 CF 91 08 95 8D B7 9E B7 81 54 91 09 0F B6 F8 94 9E BF 0F BE 
1393 1738098147756 pro JtagIce3 [0x11] >>> 13 00 
1393 1738098147756 pro JtagIce3 [0x11] <<< 06 00 00 09 00 
1393 1738098147757 pro JtagIce3 [0x11] >>> 06 00 
1393 1738098147757 pro JtagIce3 [0x11] <<< 13 00 80 C1 0A 40 4C 20 00 00 8D BF AD B7 BE B7 11 96 81 E4 ED E3 F3 E0 01 90 0D 92 8A 95 E1 F7 0E 94 4D 01 C1 5B DE 4F 28 81 CF 54 D1 40 ED E3 F3 E0 36 81 47 81 60 85 71 85 53 85 0F B6 F8 94 DE BF 0F BE CD BF 82 85 0E 94 F5 07 81 E0 CB CF 8F E2 91 E0 0E 94 98 00 82 E0 C5 CF 80 E4 80 93 7C 00 10 92 7B 00 81 E8 80 93 7A 00 80 E0 08 95 EA E7 F0 E0 80 81 8F 77 80 83 08 95 EA E7 F0 E0 80 81 80 68 80 83 08 95 81 11 
1393 1738098147791 pro JtagIce3 [0x11] >>> 13 00 
1393 1738098147791 pro JtagIce3 [0x11] <<< 06 00 00 09 40 
1393 1738098147792 pro JtagIce3 [0x11] >>> 06 00 
1393 1738098147792 pro JtagIce3 [0x11] <<< 13 00 80 C1 0A 40 4C 20 00 00 09 C0 80 E4 80 93 7C 00 EA E7 F0 E0 80 81 80 64 80 83 08 95 8E 30 49 F0 EC E7 F0 E0 90 81 90 7F 90 83 90 81 89 2B 80 83 EF CF 8E E4 80 93 7C 00 EB CF 80 91 7A 00 82 95 81 70 08 95 80 91 78 00 90 91 79 00 08 95 0E 94 3F 09 0E 94 59 09 81 15 E1 F3 0E 94 5E 09 9C 01 EA E7 F0 E0 90 81 90 61 90 83 C9 01 08 95 2F 92 3F 92 5F 92 6F 92 7F 92 8F 92 9F 92 AF 92 BF 92 CF 92 DF 92 EF 92 FF 92 
1393 1738098147826 pro JtagIce3 [0x11] >>> 13 00 
1393 1738098147826 pro JtagIce3 [0x11] <<< 06 00 00 09 80 
1393 1738098147827 pro JtagIce3 [0x11] >>> 06 00 
1393 1738098147827 pro JtagIce3 [0x11] <<< 13 00 80 C1 0A 40 4C 20 00 00 0F 93 1F 93 CF 93 DF 93 00 D0 CD B7 DE B7 26 2E 37 2E 2D B7 3E B7 3A 83 29 83 10 92 CD 04 D1 01 2C 91 23 30 49 F1 21 E0 20 93 CD 04 21 E0 31 E0 ED EC F3 E0 A8 2F B9 2F 01 90 0D 92 21 50 30 40 D9 F7 E9 81 FA 81 0F B6 F8 94 FE BF 0F BE ED BF 0F 90 0F 90 DF 91 CF 91 1F 91 0F 91 FF 90 EF 90 DF 90 CF 90 BF 90 AF 90 9F 90 8F 90 7F 90 6F 90 5F 90 3F 90 2F 90 08 95 F1 01 21 81 2F 3F 09 F4 
1393 1738098147862 pro JtagIce3 [0x11] >>> 13 00 
1393 1738098147862 pro JtagIce3 [0x11] <<< 06 00 00 09 C0 
1393 1738098147863 pro JtagIce3 [0x11] >>> 06 00 
1393 1738098147863 pro JtagIce3 [0x11] <<< 13 00 80 C1 0A 40 4C 20 00 00 4E C0 D1 01 12 96 9C 90 B9 2D B8 70 7B 2E F1 01 43 81 84 80 6B 2E 65 E0 70 E0 93 FE 03 C0 65 80 66 E0 70 E0 04 2F 10 E0 98 01 2F 5F 3F 4F AD B7 BE B7 A2 1B B3 0B 0F B6 F8 94 BE BF 0F BE AD BF ED B7 FE B7 31 96 7F 01 41 15 E9 F0 5B 01 F1 01 E6 0F F7 1F 97 01 55 24 5A 94 54 0E C5 2C D1 2C A1 01 4F 5F 5F 4F 45 0D 51 1D 46 0F 57 1F 61 91 D9 01 6D 93 9D 01 E4 17 F5 07 C9 F7 B6 01 6F 5F 
1393 1738098147897 pro JtagIce3 [0x11] >>> 13 00 
1393 1738098147897 pro JtagIce3 [0x11] <<< 06 00 00 0A 00 
1393 1738098147898 pro JtagIce3 [0x11] >>> 06 00 
1393 1738098147898 pro JtagIce3 [0x11] <<< 13 00 80 C1 0A 40 4C 20 00 00 7F 4F 6A 0D 7B 1D F7 01 E0 0F F1 1F 10 82 F7 01 20 81 24 35 41 F0 2B E0 20 93 CD 04 87 CF 22 E0 20 93 CD 04 83 CF 29 2D 27 70 21 30 21 F0 2C E0 20 93 CD 04 7B CF 71 14 11 F0 66 0D 71 1D F1 01 E6 0F F7 1F 20 81 62 0F 71 1D FB 01 31 96 8A 94 58 2D 52 1B 82 16 A1 F0 E2 0D F3 1D 2E EC 33 E0 D1 01 12 96 A6 0F B7 1F 4F EF 45 0F BD 01 64 0F 71 1D 41 91 D9 01 4D 93 9D 01 E6 17 F7 07 C9 F7 
1393 1738098147932 pro JtagIce3 [0x11] >>> 13 00 
1393 1738098147932 pro JtagIce3 [0x11] <<< 06 00 00 0A 40 
1393 1738098147933 pro JtagIce3 [0x11] >>> 06 00 
1393 1738098147933 pro JtagIce3 [0x11] <<< 13 00 80 C1 0A 40 4C 20 00 00 50 93 CD 03 53 CF 8F 93 81 E0 80 93 F1 04 8F 91 18 95 1F 92 0F 92 0F B6 0F 92 11 24 2F 93 3F 93 4F 93 5F 93 6F 93 7F 93 8F 93 9F 93 AF 93 BF 93 EF 93 FF 93 81 E0 80 93 F0 04 80 91 F2 04 81 15 89 F0 FF 91 EF 91 BF 91 AF 91 9F 91 8F 91 7F 91 6F 91 5F 91 4F 91 3F 91 2F 91 0F 90 0F BE 0F 90 1F 90 18 95 81 E0 80 93 F2 04 0E 94 29 07 E9 CF 1F 92 0F 92 0F B6 0F 92 11 24 2F 93 3F 93 4F 93 
1393 1738098147968 pro JtagIce3 [0x11] >>> 13 00 
1393 1738098147968 pro JtagIce3 [0x11] <<< 06 00 00 0A 80 
1393 1738098147969 pro JtagIce3 [0x11] >>> 06 00 
1393 1738098147969 pro JtagIce3 [0x11] <<< 13 00 80 C1 0A 40 4C 20 00 00 5F 93 6F 93 7F 93 8F 93 9F 93 AF 93 BF 93 EF 93 FF 93 10 92 F2 04 0E 94 37 07 FF 91 EF 91 BF 91 AF 91 9F 91 8F 91 7F 91 6F 91 5F 91 4F 91 3F 91 2F 91 0F 90 0F BE 0F 90 1F 90 18 95 F8 94 81 E0 0E 94 1D 06 80 E0 0E 94 24 06 80 E0 0E 94 C4 05 80 E0 0E 94 CB 05 80 E0 0E 94 79 04 85 B7 80 66 85 BF 8F 7D 85 BF 83 B7 81 7F 84 60 83 BF 83 B7 81 60 83 BF 78 94 88 95 08 95 0E 94 39 09 8E E0 
1393 1738098148003 pro JtagIce3 [0x11] >>> 13 00 
1393 1738098148003 pro JtagIce3 [0x11] <<< 06 00 00 0A C0 
1393 1738098148005 pro JtagIce3 [0x11] >>> 06 00 
1393 1738098148005 pro JtagIce3 [0x11] <<< 13 00 80 C1 0A 40 4C 20 00 00 0E 94 63 09 8E E0 0E 94 63 09 8E E0 0E 94 63 09 90 93 F7 05 80 93 F6 05 0E 94 33 09 80 91 F6 05 90 91 F7 05 08 95 CD B7 DE B7 CA 50 D1 40 0F B6 F8 94 DE BF 0F BE CD BF 81 E0 0E 94 79 04 8F E1 9E E4 01 97 F1 F7 00 C0 00 00 0E 94 12 07 0E 94 84 00 80 E4 91 E0 0E 94 98 00 0E 94 80 04 0E 94 6A 04 0E 94 29 09 0E 94 15 07 0E 94 1F 07 0F 2E FF EC CF 2E F4 E0 DF 2E F0 2D 0D EE 14 E0 F6 01 
1393 1738098148039 pro JtagIce3 [0x11] >>> 13 00 
1393 1738098148039 pro JtagIce3 [0x11] <<< 06 00 00 0B 00 
1393 1738098148040 pro JtagIce3 [0x11] >>> 06 00 
1393 1738098148040 pro JtagIce3 [0x11] <<< 13 00 80 C1 0A 40 4C 20 00 00 11 92 11 92 E0 17 F1 07 D9 F7 CE 01 08 96 0E 94 6E 06 83 E0 91 E0 FE 01 38 96 A3 EF B4 E0 01 90 0D 92 01 97 E1 F7 8D B7 9E B7 83 50 91 40 0F B6 F8 94 9E BF 0F BE 8D BF AD B7 BE B7 11 96 83 E0 91 E0 E3 EF F4 E0 01 90 0D 92 01 97 E1 F7 0E 94 81 08 80 93 CE 04 9F EF 20 E7 82 E0 91 50 20 40 80 40 E1 F7 00 C0 00 00 0F B6 F8 94 DE BF 0F BE CD BF 0E 94 40 07 0E 94 65 07 0E 94 6B 07 0E 94 
1393 1738098148074 pro JtagIce3 [0x11] >>> 13 00 
1393 1738098148074 pro JtagIce3 [0x11] <<< 06 00 00 0B 40 
1393 1738098148076 pro JtagIce3 [0x11] >>> 06 00 
1393 1738098148076 pro JtagIce3 [0x11] <<< 13 00 80 C1 0A 40 4C 20 00 00 61 07 0E 94 5D 07 0F 2E FF EC EF 2E F4 E0 FF 2E F0 2D 04 C0 80 91 F1 04 81 11 21 C0 8C E7 91 E0 0E 94 98 00 80 E0 0E 94 CB 05 80 E0 0E 94 C4 05 0E 94 79 00 0E 94 9E 0A 80 91 F0 04 81 15 51 F3 10 92 F0 04 E0 91 EF 04 F0 E0 EE 0F FF 1F E1 53 FB 4F 80 81 91 81 01 96 91 83 80 83 DB CF 10 92 F1 04 80 91 EF 04 8F 5F 80 93 EF 04 0E 94 61 07 0E 94 5D 07 83 E8 91 E0 0E 94 98 00 0E 94 79 00 
1393 1738098148110 pro JtagIce3 [0x11] >>> 13 00 
1393 1738098148110 pro JtagIce3 [0x11] <<< 06 00 00 0B 80 
1393 1738098148111 pro JtagIce3 [0x11] >>> 06 00 
1393 1738098148111 pro JtagIce3 [0x11] <<< 13 00 80 C1 0A 40 4C 20 00 00 0E 94 61 07 0E 94 5D 07 81 E0 0E 94 79 04 0E 94 00 04 81 E0 0E 94 24 06 80 E0 0E 94 1D 06 CE 01 08 96 0E 94 6E 06 83 E0 91 E0 FE 01 38 96 A3 EF B4 E0 01 90 0D 92 01 97 E1 F7 80 91 EF 04 83 30 08 F4 AC CF 10 92 EF 04 80 91 CE 04 82 30 09 F4 8A C0 88 EF 95 E0 0E 94 7B 02 0E 94 BD 0A B8 2E A9 2E 0E 94 79 07 29 83 3A 83 4B 83 5C 83 6D 83 7E 83 8F 83 FF 92 EF 92 AF 92 BF 92 00 D0 00 D0 
1393 1738098148145 pro JtagIce3 [0x11] >>> 13 00 
1393 1738098148146 pro JtagIce3 [0x11] <<< 06 00 00 0B C0 
1393 1738098148147 pro JtagIce3 [0x11] >>> 06 00 
1393 1738098148147 pro JtagIce3 [0x11] <<< 13 00 80 C1 0A 40 4C 20 00 00 00 D0 0F 92 AD B7 BE B7 11 96 87 E0 FE 01 31 96 01 90 0D 92 8A 95 E1 F7 8D B7 9E B7 83 50 91 40 0F B6 F8 94 9E BF 0F BE 8D BF AD B7 BE B7 11 96 83 E0 91 E0 E3 EF F4 E0 01 90 0D 92 01 97 E1 F7 CE 01 08 96 0E 94 8C 02 81 E4 FE 01 38 96 A8 EF B5 E0 01 90 0D 92 8A 95 E1 F7 0F B6 F8 94 DE BF 0F BE CD BF 8F E9 91 E0 0E 94 98 00 8D B7 9E B7 81 54 91 09 0F B6 F8 94 9E BF 0F BE 8D BF AD B7 
1393 1738098148181 pro JtagIce3 [0x11] >>> 13 00 
1393 1738098148181 pro JtagIce3 [0x11] <<< 06 00 00 0C 00 
1393 1738098148182 pro JtagIce3 [0x11] >>> 06 00 
1393 1738098148182 pro JtagIce3 [0x11] <<< 13 00 80 C1 0A 40 4C 20 00 00 BE B7 11 96 81 E4 E8 EF F5 E0 01 90 0D 92 8A 95 E1 F7 0E 94 4D 01 8D B7 9E B7 8F 5B 9F 4F 0F B6 F8 94 DE BF 0F BE CD BF 81 54 91 09 0F B6 F8 94 9E BF 0F BE 8D BF AD B7 BE B7 11 96 81 E4 E8 EF F5 E0 01 90 0D 92 8A 95 E1 F7 0E 94 80 03 0F B6 F8 94 DE BF 0F BE CD BF F6 01 11 92 11 92 E0 17 F1 07 D9 F7 1B CF 8D B7 9E B7 83 50 91 40 0F B6 F8 94 9E BF 0F BE 8D BF AD B7 BE B7 11 96 83 E0 
1393 1738098148217 pro JtagIce3 [0x11] >>> 13 00 
1393 1738098148217 pro JtagIce3 [0x11] <<< 06 00 00 0C 40 
1393 1738098148218 pro JtagIce3 [0x11] >>> 06 00 
1393 1738098148218 pro JtagIce3 [0x11] <<< 13 00 80 C1 0A 40 4C 20 00 00 91 E0 E3 EF F4 E0 01 90 0D 92 01 97 E1 F7 0E 94 81 08 80 93 CE 04 0F B6 F8 94 DE BF 0F BE CD BF 58 CF AA 1B BB 1B 51 E1 07 C0 AA 1F BB 1F A6 17 B7 07 10 F0 A6 1B B7 0B 88 1F 99 1F 5A 95 A9 F7 80 95 90 95 BC 01 CD 01 08 95 97 FB 07 2E 16 F4 00 94 07 D0 77 FD 09 D0 0E 94 51 0C 07 FC 05 D0 3E F4 90 95 81 95 9F 4F 08 95 70 95 61 95 7F 4F 08 95 A1 E2 1A 2E AA 1B BB 1B FD 01 0D C0 AA 1F 
1393 1738098148252 pro JtagIce3 [0x11] >>> 13 00 
1393 1738098148253 pro JtagIce3 [0x11] <<< 06 00 00 0C 80 
1393 1738098148254 pro JtagIce3 [0x11] >>> 06 00 
1393 1738098148254 pro JtagIce3 [0x11] <<< 13 00 80 C1 0A 40 4C 20 00 00 BB 1F EE 1F FF 1F A2 17 B3 07 E4 07 F5 07 20 F0 A2 1B B3 0B E4 0B F5 0B 66 1F 77 1F 88 1F 99 1F 1A 94 69 F7 60 95 70 95 80 95 90 95 9B 01 AC 01 BD 01 CF 01 08 95 FB 01 DC 01 02 C0 01 90 0D 92 41 50 50 40 D8 F7 08 95 DC 01 01 C0 6D 93 41 50 50 40 E0 F7 08 95 FC 01 81 91 86 17 21 F0 88 23 D9 F7 99 27 08 95 31 97 CF 01 08 95 AE E0 B0 E0 EC EB FC E0 0C 94 86 0F 0D 89 1E 89 86 E0 8C 83 
1393 1738098148288 pro JtagIce3 [0x11] >>> 13 00 
1393 1738098148288 pro JtagIce3 [0x11] <<< 06 00 00 0C C0 
1393 1738098148289 pro JtagIce3 [0x11] >>> 06 00 
1393 1738098148289 pro JtagIce3 [0x11] <<< 13 00 80 C1 0A 40 4C 20 00 00 1A 83 09 83 8F 89 98 8D 81 30 20 E8 92 07 10 F0 80 E0 90 E8 01 97 9E 83 8D 83 AE 01 45 5E 5F 4F 69 8D 7A 8D CE 01 01 96 0E 94 E8 0C 4D 81 5E 81 57 FD 0A C0 2F 81 38 85 42 17 53 07 0C F4 9A 01 02 0F 13 1F F8 01 10 82 2E 96 E4 E0 0C 94 A2 0F AB E0 B0 E0 EE EE FC E0 0C 94 79 0F 6C 01 7B 01 8A 01 FC 01 17 82 16 82 83 81 81 FF DA C1 9A E0 49 2E F6 01 23 81 F7 01 23 FD 85 91 23 FF 81 91 
1393 1738098148323 pro JtagIce3 [0x11] >>> 13 00 
1393 1738098148324 pro JtagIce3 [0x11] <<< 06 00 00 0D 00 
1393 1738098148325 pro JtagIce3 [0x11] >>> 06 00 
1393 1738098148325 pro JtagIce3 [0x11] <<< 13 00 80 C1 0A 40 4C 20 00 00 7F 01 81 15 09 F4 1F C1 85 32 39 F4 23 FD 95 91 23 FF 91 91 7F 01 95 32 29 F4 B6 01 90 E0 0E 94 EA 0E E7 CF 30 E0 61 2C 51 2C 71 2C F0 E2 7F 16 40 F5 9B 32 D9 F0 58 F4 90 32 D1 F0 93 32 F1 F0 9E 32 99 F5 76 FC FF C0 68 94 76 F8 06 C0 9D 32 91 F0 90 33 C1 F4 68 94 70 F8 F7 01 23 FD 95 91 23 FF 91 91 7F 01 91 11 E1 CF 29 C0 68 94 71 F8 68 94 72 F8 F2 CF 68 94 73 F8 EF CF 68 94 74 F8 
1393 1738098148359 pro JtagIce3 [0x11] >>> 13 00 
1393 1738098148359 pro JtagIce3 [0x11] <<< 06 00 00 0D 40 
1393 1738098148360 pro JtagIce3 [0x11] >>> 06 00 
1393 1738098148360 pro JtagIce3 [0x11] <<< 13 00 80 C1 0A 40 4C 20 00 00 EC CF 77 FC 1C C0 80 ED 89 0F 8A 30 C8 F6 76 FE 05 C0 64 9C 80 0D 11 24 68 2E DF CF 54 9C 80 0D 11 24 58 2E 68 94 75 F8 D8 CF 9C 36 19 F4 68 94 77 F8 D3 CF 9C 34 09 F4 4B C0 98 36 71 F2 89 2F 8F 7D 85 54 83 30 08 F4 45 C0 93 36 09 F4 66 C0 93 37 09 F4 69 C0 93 35 09 F4 75 C0 94 36 19 F0 99 36 09 F0 9F C0 F8 01 77 FE 95 C0 61 91 71 91 81 91 91 91 8F 01 27 2D 2F 76 72 2E 97 FF 09 C0 
1393 1738098148394 pro JtagIce3 [0x11] >>> 13 00 
1393 1738098148395 pro JtagIce3 [0x11] <<< 06 00 00 0D 80 
1393 1738098148396 pro JtagIce3 [0x11] >>> 06 00 
1393 1738098148396 pro JtagIce3 [0x11] <<< 13 00 80 C1 0A 40 4C 20 00 00 90 95 80 95 70 95 61 95 7F 4F 8F 4F 9F 4F 68 94 77 F8 2A E0 30 E0 AE 01 4F 5F 5F 4F 5A 01 0E 94 1A 0F 8A 19 A8 2E 76 FE C5 C0 87 2D 8E 7F A6 14 08 F0 BF C0 74 FE 12 C1 72 FC 06 C1 F7 2D FE 7E 7F 2E B6 2C 87 2D 86 78 81 15 09 F4 C0 C0 01 C1 31 E0 83 CF 31 15 F9 F0 08 5F 1F 4F 8F E3 89 83 88 24 83 94 91 2C AE 01 4F 5F 5F 4F 5A 01 E8 94 77 F8 73 FC 03 C0 85 14 91 04 B0 F1 81 14 91 04 
1393 1738098148430 pro JtagIce3 [0x11] >>> 13 00 
1393 1738098148430 pro JtagIce3 [0x11] <<< 06 00 00 0D C0 
1393 1738098148431 pro JtagIce3 [0x11] >>> 06 00 
1393 1738098148431 pro JtagIce3 [0x11] <<< 13 00 80 C1 0A 40 4C 20 00 00 D1 F5 51 14 09 F4 35 CF B6 01 80 E2 90 E0 0E 94 EA 0E 5A 94 F6 CF 0C 5F 1F 4F E0 CF F8 01 80 81 89 83 0E 5F 1F 4F DC CF F8 01 A1 90 B1 90 8F 01 66 2D 70 E0 76 FC 02 C0 6F EF 7F EF C5 01 0E 94 DF 0E 4C 01 D4 CF F8 01 A1 90 B1 90 8F 01 66 2D 70 E0 76 FC 02 C0 6F EF 7F EF C5 01 0E 94 D4 0E 4C 01 68 94 77 F8 C5 CF B6 01 80 E2 90 E0 0E 94 EA 0E 5A 94 C0 CF F5 01 77 FC 85 91 77 FE 81 91 
1393 1738098148465 pro JtagIce3 [0x11] >>> 13 00 
1393 1738098148465 pro JtagIce3 [0x11] <<< 06 00 00 0E 00 
1393 1738098148467 pro JtagIce3 [0x11] >>> 06 00 
1393 1738098148467 pro JtagIce3 [0x11] <<< 13 00 80 C1 0A 40 4C 20 00 00 5F 01 B6 01 90 E0 0E 94 EA 0E 51 10 5A 94 F1 E0 8F 1A 91 08 B3 CF 61 91 71 91 07 2E 00 0C 88 0B 99 0B 68 CF 37 2C E8 94 34 F8 2A E0 30 E0 95 37 39 F1 57 2D 59 7F 35 2E 90 37 99 F0 58 F4 98 35 A9 F0 9F 36 D9 F0 F6 01 86 81 97 81 2B 96 E1 E1 0C 94 95 0F 98 37 B9 F7 74 FC 05 C0 20 E1 30 E0 0F C0 68 94 34 F8 68 94 32 F8 F8 CF 74 FE 03 C0 87 2D 86 60 38 2E 20 E1 32 E0 02 C0 28 E0 30 E0 
1393 1738098148501 pro JtagIce3 [0x11] >>> 13 00 
1393 1738098148501 pro JtagIce3 [0x11] <<< 06 00 00 0E 40 
1393 1738098148502 pro JtagIce3 [0x11] >>> 06 00 
1393 1738098148502 pro JtagIce3 [0x11] <<< 13 00 80 C1 0A 40 4C 20 00 00 F8 01 37 FE 11 C0 61 91 71 91 81 91 91 91 8F 01 FE 01 31 96 5F 01 AF 01 0E 94 1A 0F 8A 19 A8 2E 73 2C E8 94 77 F8 3F CF 61 91 71 91 80 E0 90 E0 EE CF 78 2E BA 2C 74 FE 45 CF FE 01 EA 0D F1 1D 80 81 80 33 09 F0 43 C0 27 2D 29 7E 72 2E 73 FC 0E C0 70 FE 4F C0 6A 2C B5 14 18 F4 65 0C 6B 18 B5 2C 85 2D 8B 19 5B 14 08 F4 80 E0 B8 0E B5 14 08 F0 42 C0 5B 18 74 FE 41 C0 B6 01 80 E3 90 E0 
1393 1738098148536 pro JtagIce3 [0x11] >>> 13 00 
1393 1738098148537 pro JtagIce3 [0x11] <<< 06 00 00 0E 80 
1393 1738098148538 pro JtagIce3 [0x11] >>> 06 00 
1393 1738098148538 pro JtagIce3 [0x11] <<< 13 00 80 C1 0A 40 4C 20 00 00 0E 94 EA 0E 72 FE 09 C0 88 E5 90 E0 71 FC 02 C0 88 E7 90 E0 B6 01 0E 94 EA 0E A6 14 D8 F1 AA 94 B1 2C 4F EF A4 1A B4 0A CE 01 01 96 3C 01 A8 0E B9 1E F5 01 82 91 5F 01 B6 01 90 E0 0E 94 EA 0E 6A 14 7B 04 B1 F7 1D CF B6 2C 78 2E B6 CF 72 FC 02 C0 B3 94 BC CF B3 94 B3 94 B9 CF B6 2C 78 2E F1 CE B6 01 80 E2 90 E0 0E 94 EA 0E 33 94 35 14 C0 F3 B7 CF 3B 2C FB CF 51 2C BD CF 87 2D 86 78 
1393 1738098148572 pro JtagIce3 [0x11] >>> 13 00 
1393 1738098148572 pro JtagIce3 [0x11] <<< 06 00 00 0E C0 
1393 1738098148573 pro JtagIce3 [0x11] >>> 06 00 
1393 1738098148573 pro JtagIce3 [0x11] <<< 13 00 80 C1 0A 40 4C 20 00 00 81 15 59 F2 80 E2 71 FC 8B E2 77 FC 8D E2 B6 01 90 E0 C1 CF B6 01 80 E3 90 E0 0E 94 EA 0E 6A 94 BC CF 8F EF 9F EF 52 CF FC 01 05 90 61 50 70 40 01 10 D8 F7 80 95 90 95 8E 0F 9F 1F 08 95 FC 01 61 50 70 40 01 90 01 10 D8 F7 80 95 90 95 8E 0F 9F 1F 08 95 0F 93 1F 93 CF 93 DF 93 18 2F 09 2F EB 01 8B 81 81 FD 09 C0 1F EF 0F EF 81 2F 90 2F DF 91 CF 91 1F 91 0F 91 08 95 82 FF 14 C0 2E 81 
1393 1738098148607 pro JtagIce3 [0x11] >>> 13 00 
1393 1738098148607 pro JtagIce3 [0x11] <<< 06 00 00 0F 00 
1393 1738098148608 pro JtagIce3 [0x11] >>> 06 00 
1393 1738098148608 pro JtagIce3 [0x11] <<< 13 00 80 C1 0A 40 4C 20 00 00 3F 81 8C 81 9D 81 28 17 39 07 3C F4 E8 81 F9 81 CF 01 01 96 99 83 88 83 10 83 8E 81 9F 81 01 96 9F 83 8E 83 E3 CF E8 85 F9 85 81 2F 09 95 89 2B A1 F3 DA CF FA 01 AA 27 28 30 51 F1 20 31 81 F1 E8 94 6F 93 6E 7F 6E 5F 7F 4F 8F 4F 9F 4F AF 4F B1 E0 3E D0 B4 E0 3C D0 67 0F 78 1F 89 1F 9A 1F A1 1D 68 0F 79 1F 8A 1F 91 1D A1 1D 6A 0F 71 1D 81 1D 91 1D A1 1D 20 D0 09 F4 68 94 3F 91 2A E0 
1393 1738098148643 pro JtagIce3 [0x11] >>> 13 00 
1393 1738098148643 pro JtagIce3 [0x11] <<< 06 00 00 0F 40 
1393 1738098148644 pro JtagIce3 [0x11] >>> 06 00 
1393 1738098148644 pro JtagIce3 [0x11] <<< 13 00 80 C1 0A 40 4C 20 00 00 26 9F 11 24 30 19 30 5D 31 93 DE F6 CF 01 08 95 46 2F 47 70 40 5D 41 93 B3 E0 0F D0 C9 F7 F6 CF 46 2F 4F 70 40 5D 4A 33 18 F0 49 5D 31 FD 40 52 41 93 02 D0 A9 F7 EA CF B4 E0 A6 95 97 95 87 95 77 95 67 95 BA 95 C9 F7 00 97 61 05 71 05 08 95 9B 01 AC 01 0A 2E 06 94 57 95 47 95 37 95 27 95 BA 95 C9 F7 62 0F 73 1F 84 1F 95 1F A0 1D 08 95 2F 92 3F 92 4F 92 5F 92 6F 92 7F 92 8F 92 9F 92 
1393 1738098148678 pro JtagIce3 [0x11] >>> 13 00 
1393 1738098148678 pro JtagIce3 [0x11] <<< 06 00 00 0F 80 
1393 1738098148679 pro JtagIce3 [0x11] >>> 06 00 
1393 1738098148679 pro JtagIce3 [0x11] <<< 13 00 80 C1 0A 40 4C 20 00 00 AF 92 BF 92 CF 92 DF 92 EF 92 FF 92 0F 93 1F 93 CF 93 DF 93 CD B7 DE B7 CA 1B DB 0B 0F B6 F8 94 DE BF 0F BE CD BF 09 94 2A 88 39 88 48 88 5F 84 6E 84 7D 84 8C 84 9B 84 AA 84 B9 84 C8 84 DF 80 EE 80 FD 80 0C 81 1B 81 AA 81 B9 81 CE 0F D1 1D 0F B6 F8 94 DE BF 0F BE CD BF ED 01 08 95 F8 94 FF CF 25 75 00 2C 00 20 20 20 20 00 4C 45 4E 47 54 48 00 54 4F 00 46 52 4F 4D 00 44 54 59 50 45 
1393 1738098148713 pro JtagIce3 [0x11] >>> 13 00 
1393 1738098148713 pro JtagIce3 [0x11] <<< 06 00 00 0F C0 
1393 1738098148715 pro JtagIce3 [0x11] >>> 06 00 
1393 1738098148715 pro JtagIce3 [0x11] <<< 13 00 80 C1 0A 40 4C 20 00 00 00 46 4C 41 47 53 00 41 53 20 4E 55 4D 42 45 52 00 44 69 64 20 6E 6F 74 20 67 65 74 20 52 58 0D 0A 00 0D 0A 0D 0A 20 2E 2E 2E 2E 2E 2E 2E 2E 2E 2E 2E 2E 2E 2E 2E 2E 2E 2E 2E 20 53 54 41 52 54 49 4E 47 21 20 2E 2E 2E 2E 2E 2E 2E 2E 2E 2E 2E 2E 2E 2E 2E 2E 2E 2E 2E 20 0D 0A 0D 0A 00 4C 4F 4F 50 0D 0A 00 49 6E 63 72 65 6D 65 6E 74 69 6E 67 20 6D 69 6E 75 74 65 20 69 6E 64 65 78 0D 0A 
1393 1738098148749 pro JtagIce3 [0x11] >>> 13 00 
1393 1738098148749 pro JtagIce3 [0x11] <<< 06 00 00 10 00 
1393 1738098148750 pro JtagIce3 [0x11] >>> 06 00 
1393 1738098148750 pro JtagIce3 [0x11] <<< 13 00 80 C1 0A 40 4C 20 00 00 00 53 65 6E 64 69 6E 67 20 74 68 69 73 20 6D 65 73 73 61 67 65 0D 0A 00 FF FF FF FF FF FF FF FF FF FF FF FF FF FF FF FF FF FF FF FF FF FF FF FF FF FF FF FF FF FF FF FF FF FF FF FF FF FF FF FF FF FF FF FF FF FF FF FF FF FF FF FF FF FF FF FF FF FF FF FF FF FF FF FF FF FF FF FF FF FF FF FF FF FF FF FF FF FF FF FF FF FF FF FF FF FF FF FF FF FF FF FF FF FF FF FF FF FF FF FF FF FF FF FF 
1393 1738098148758 pro JtagIce3 [0x11] >>> 13 00 
1393 1738098148758 pro JtagIce3 [0x11] <<< 06 00 00 00 00 
1393 1738098148759 pro JtagIce3 [0x11] >>> 06 00 
1393 1738098148759 pro JtagIce3 [0x11] <<< 14 00 80 20 
1393 1738098148794 pro JtagIce3 [0x11] >>> 14 00 0C 94 5A 00 0C 94 43 0A 0C 94 49 0A 0C 94 77 00 0C 94 77 00 0C 94 77 00 0C 94 78 0A 0C 94 77 00 0C 94 77 00 0C 94 77 00 0C 94 77 00 0C 94 77 00 0C 94 77 00 0C 94 77 00 0C 94 77 00 0C 94 77 00 0C 94 77 00 0C 94 77 00 0C 94 77 00 0C 94 77 00 0C 94 77 00 0C 94 77 00 0C 94 77 00 0C 94 77 00 0C 94 77 00 0C 94 77 00 0C 94 77 00 0C 94 77 00 0C 94 77 00 0C 94 77 00 0C 94 77 00 0C 94 77 00 00 
1393 1738098148794 pro JtagIce3 [0x11] <<< 06 00 00 00 40 
1393 1738098148795 pro JtagIce3 [0x11] >>> 06 00 
1393 1738098148795 pro JtagIce3 [0x11] <<< 14 00 80 20 
1393 1738098148830 pro JtagIce3 [0x11] >>> 14 00 0C 94 77 00 0C 94 77 00 0C 94 77 00 0C 94 77 00 0C 94 77 00 0C 94 77 00 0C 94 77 00 0C 94 77 00 0C 94 77 00 0C 94 77 00 0C 94 77 00 0C 94 77 00 0C 94 77 00 11 24 1F BE CF EF D8 E0 DE BF CD BF 11 E0 A0 E0 B1 E0 E2 E6 FF E1 02 C0 05 90 0D 92 A6 3B B1 07 D9 F7 26 E0 A6 EB B1 E0 01 C0 1D 92 A9 33 B2 07 E1 F7 0E 94 D3 0A 0C 94 AF 0F 0C 94 00 00 E0 EC F0 E0 80 81 86 FF FD CF E0 EC F0 E0 00 
1393 1738098148830 pro JtagIce3 [0x11] <<< 06 00 00 00 80 
1393 1738098148831 pro JtagIce3 [0x11] >>> 06 00 
1393 1738098148831 pro JtagIce3 [0x11] <<< 14 00 80 20 
1393 1738098148866 pro JtagIce3 [0x11] >>> 14 00 80 81 80 64 80 83 08 95 10 92 C5 00 8C E0 80 93 C4 00 88 E1 80 93 C1 00 86 E0 80 93 C2 00 08 95 E0 EC F0 E0 90 81 95 FF FD CF 80 93 C6 00 08 95 CF 93 DF 93 C8 2F D9 2F 88 81 81 15 31 F0 21 96 0E 94 90 00 89 91 81 11 FB CF DF 91 CF 91 08 95 5F 92 6F 92 7F 92 8F 92 9F 92 AF 92 BF 92 CF 92 DF 92 EF 92 FF 92 0F 93 1F 93 CF 93 DF 93 C8 2E D9 2E E6 2E F7 2E 54 2E 65 2E 8B E5 0E 94 90 00 00 
1393 1738098148866 pro JtagIce3 [0x11] <<< 06 00 00 00 C0 
1393 1738098148867 pro JtagIce3 [0x11] >>> 06 00 
1393 1738098148867 pro JtagIce3 [0x11] <<< 14 00 80 20 
1393 1738098148902 pro JtagIce3 [0x11] >>> 14 00 E1 14 F1 04 B1 F1 56 01 AE 0C BF 1C 46 01 00 E0 11 E0 68 94 77 24 74 F8 C6 EB D1 E0 21 E0 E2 1A F1 08 03 C0 8A 14 9B 04 21 F1 F4 01 81 91 4F 01 1F 92 8F 93 1F 93 0F 93 1F 92 7F 92 DF 93 CF 93 0E 94 B6 0C CE 01 0E 94 98 00 C4 01 8C 19 9D 09 01 97 ED B7 FE B7 38 96 0F B6 F8 94 FE BF 0F BE ED BF 8E 15 9F 05 F0 F6 83 E0 91 E0 0E 94 98 00 D9 CF 8D E5 0E 94 90 00 85 E0 91 E0 0E 94 98 00 00 
1393 1738098148902 pro JtagIce3 [0x11] <<< 06 00 00 01 00 
1393 1738098148903 pro JtagIce3 [0x11] >>> 06 00 
1393 1738098148903 pro JtagIce3 [0x11] <<< 14 00 80 20 
1393 1738098148938 pro JtagIce3 [0x11] >>> 14 00 85 2D 96 2D 0E 94 98 00 89 E7 91 E0 0E 94 98 00 DF 91 CF 91 1F 91 0F 91 FF 90 EF 90 DF 90 CF 90 BF 90 AF 90 9F 90 8F 90 7F 90 6F 90 5F 90 08 95 1F 93 CF 93 DF 93 18 2F D6 2F C7 2F 86 E0 91 E0 0E 94 98 00 1F 92 1F 93 80 E0 91 E0 9F 93 8F 93 1F 92 80 E1 8F 93 86 EB 91 E0 9F 93 8F 93 0E 94 B6 0C 86 EB 91 E0 0E 94 98 00 88 E0 91 E0 0E 94 98 00 8D 2F 9C 2F 0E 94 98 00 89 E7 91 E0 0E 94 00 
1393 1738098148938 pro JtagIce3 [0x11] <<< 06 00 00 01 40 
1393 1738098148939 pro JtagIce3 [0x11] >>> 06 00 
1393 1738098148939 pro JtagIce3 [0x11] <<< 14 00 80 20 
1393 1738098148974 pro JtagIce3 [0x11] >>> 14 00 98 00 8D B7 9E B7 08 96 0F B6 F8 94 9E BF 0F BE 8D BF DF 91 CF 91 1F 91 08 95 CF 93 DF 93 CD B7 DE B7 6A E0 71 E0 8D 81 0E 94 18 01 61 E1 71 E0 8E 81 0E 94 18 01 64 E1 71 E0 8F 81 0E 94 18 01 69 E1 71 E0 88 85 0E 94 18 01 6F E1 71 E0 89 85 0E 94 18 01 6D 81 70 E0 45 E2 51 E0 CE 01 0A 96 0E 94 A8 00 DF 91 CF 91 08 95 EF 92 FF 92 0F 93 1F 93 CF 93 DF 93 E8 2E F9 2E 4C E3 50 E0 60 E2 00 
1393 1738098148980 pro JtagIce3 [0x11] <<< 06 00 00 01 80 
1393 1738098148981 pro JtagIce3 [0x11] >>> 06 00 
1393 1738098148981 pro JtagIce3 [0x11] <<< 14 00 80 20 
1393 1738098149016 pro JtagIce3 [0x11] >>> 14 00 70 E0 8F EC 91 E0 0E 94 A4 0C 81 E0 0E 94 CB 05 80 E0 0E 94 D2 05 0E 94 DC 05 CA EC D1 E0 84 50 88 83 0E 94 DC 05 89 83 0E 94 DC 05 8A 83 0E 94 DC 05 8B 83 0E 94 DC 05 8C 83 08 81 01 15 59 F0 CF EC D1 E0 10 E0 01 53 1E 4F 0E 94 DC 05 89 93 C0 17 D1 07 D1 F7 80 E0 0E 94 CB 05 81 E4 EA EC F1 E0 AE 2D BF 2D 01 90 0D 92 8A 95 E1 F7 8E 2D 9F 2D DF 91 CF 91 1F 91 0F 91 FF 90 EF 90 08 95 00 
1393 1738098149016 pro JtagIce3 [0x11] <<< 06 00 00 01 C0 
1393 1738098149017 pro JtagIce3 [0x11] >>> 06 00 
1393 1738098149017 pro JtagIce3 [0x11] <<< 14 00 80 20 
1393 1738098149052 pro JtagIce3 [0x11] >>> 14 00 CF 93 C8 2F 81 E0 0E 94 CB 05 8C 2F 0E 94 D2 05 8F EF 90 E0 0E 94 DC 05 C8 2F 80 E0 0E 94 CB 05 8C 2F CF 91 08 95 CF 93 DF 93 D8 2F C6 2F 81 E0 0E 94 CB 05 8D 2F 80 68 0E 94 D2 05 8C 2F 0E 94 D2 05 C8 2F 80 E0 0E 94 CB 05 8C 2F DF 91 CF 91 08 95 FF 92 0F 93 1F 93 CF 93 DF 93 08 2F C6 2F D7 2F 14 2F 81 E0 0E 94 CB 05 80 2F 80 68 0E 94 D2 05 F8 2E 0F EF 01 0F 11 15 69 F0 10 E0 0F 5F 00 
1393 1738098149052 pro JtagIce3 [0x11] <<< 06 00 00 02 00 
1393 1738098149053 pro JtagIce3 [0x11] >>> 06 00 
1393 1738098149053 pro JtagIce3 [0x11] <<< 14 00 80 20 
1393 1738098149088 pro JtagIce3 [0x11] >>> 14 00 1F 4F 0C 0F 1D 1F FE 01 21 96 80 81 0E 94 D2 05 C0 17 D1 07 C1 F7 80 E0 0E 94 CB 05 8F 2D DF 91 CF 91 1F 91 0F 91 FF 90 08 95 CF 92 DF 92 EF 92 FF 92 0F 93 1F 93 CF 93 DF 93 06 2F 10 92 0B 02 61 15 09 F4 42 C0 C8 2F D9 2F 40 E0 50 E0 BA 01 10 E0 CC 24 CA 94 DC 2C EC 2C F1 2C 29 91 DB 01 CA 01 88 0F 99 1F AA 1F BB 1F 88 0F 99 1F AA 1F BB 1F 88 0F 99 1F AA 1F BB 1F 88 0F 99 1F AA 1F 00 
1393 1738098149088 pro JtagIce3 [0x11] <<< 06 00 00 02 40 
1393 1738098149089 pro JtagIce3 [0x11] >>> 06 00 
1393 1738098149089 pro JtagIce3 [0x11] <<< 14 00 80 20 
1393 1738098149124 pro JtagIce3 [0x11] >>> 14 00 BB 1F 88 0F 99 1F AA 1F BB 1F 84 1B 95 0B A6 0B B7 0B BC 01 CD 01 62 0F 71 1D 81 1D 91 1D A7 01 96 01 0E 94 79 0C AB 01 BC 01 1F 5F 10 93 0B 02 10 13 D4 CF CB 01 BA 01 DF 91 CF 91 1F 91 0F 91 FF 90 EF 90 DF 90 CF 90 08 95 40 E0 50 E0 BA 01 F1 CF 6D E5 8A E5 0E 94 D3 01 6C E7 8C E5 0E 94 D3 01 08 95 65 E5 8A E5 0E 94 D3 01 60 E7 8C E5 0E 94 D3 01 08 95 E8 2F F9 2F 10 82 8F EF 81 83 00 
1393 1738098149124 pro JtagIce3 [0x11] <<< 06 00 00 02 80 
1393 1738098149125 pro JtagIce3 [0x11] >>> 06 00 
1393 1738098149125 pro JtagIce3 [0x11] <<< 14 00 80 20 
1393 1738098149160 pro JtagIce3 [0x11] >>> 14 00 82 83 13 82 14 82 4C E3 50 E0 60 E2 70 E0 CF 01 05 96 0E 94 A4 0C 08 95 CF 92 DF 92 EF 92 FF 92 0F 93 1F 93 CF 93 DF 93 CD B7 DE B7 08 2F 19 2F CB 5E DE 4F C8 80 C5 51 D1 40 CA 5E DE 4F D8 80 C6 51 D1 40 C9 5E DE 4F E8 80 C7 51 D1 40 C8 5E DE 4F F8 80 C8 51 D1 40 8A EC 91 E0 0E 94 7B 02 4B 85 4B 30 08 F0 4A E0 50 E0 BE 01 64 5F 7F 4F 8F EC 91 E0 0E 94 9B 0C C4 5F DE 4F 48 81 CC 50 00 
1393 1738098149160 pro JtagIce3 [0x11] <<< 06 00 00 02 C0 
1393 1738098149161 pro JtagIce3 [0x11] >>> 06 00 
1393 1738098149161 pro JtagIce3 [0x11] <<< 14 00 80 20 
1393 1738098149196 pro JtagIce3 [0x11] >>> 14 00 D1 40 4B 30 08 F0 4A E0 50 E0 BE 01 64 57 7F 4F 89 ED 91 E0 0E 94 9B 0C EA EC F1 E0 C1 8E D2 8E C1 5F DE 4F 88 81 CF 50 D1 40 83 8F C0 5F DE 4F 88 81 C0 51 D1 40 84 8F CE 5E DE 4F 88 81 C2 51 D1 40 85 8F CD 5E DE 4F 88 81 C3 51 D1 40 86 8F CC 5E DE 4F 88 81 C4 51 D1 40 87 8F AE 2D BF 2D EA EE F1 E0 48 E0 52 E0 2D 91 3C 91 11 97 20 83 2D 91 3D 91 31 83 32 96 E4 17 F5 07 A9 F7 69 E3 00 
1393 1738098149196 pro JtagIce3 [0x11] <<< 06 00 00 03 00 
1393 1738098149197 pro JtagIce3 [0x11] >>> 06 00 
1393 1738098149197 pro JtagIce3 [0x11] <<< 14 00 80 20 
1393 1738098149232 pro JtagIce3 [0x11] >>> 14 00 8F EC 91 E0 0E 94 15 02 60 93 C6 01 70 93 C7 01 80 93 C8 01 90 93 C9 01 EA EC F1 E0 66 AF 77 AF 80 93 0A 02 8C E3 80 83 8F E1 84 83 C3 5F DE 4F 88 81 CD 50 D1 40 82 83 8F EF 81 83 82 E0 83 83 81 E4 A0 2F B1 2F 01 90 0D 92 8A 95 E1 F7 80 2F 91 2F DF 91 CF 91 1F 91 0F 91 FF 90 EF 90 DF 90 CF 90 08 95 CF 93 C8 2F 81 E0 0E 94 C0 01 68 2F 63 7E CC 71 6C 2B 81 E0 0E 94 D3 01 CF 91 08 95 00 
1393 1738098149232 pro JtagIce3 [0x11] <<< 06 00 00 03 40 
1393 1738098149233 pro JtagIce3 [0x11] >>> 06 00 
1393 1738098149233 pro JtagIce3 [0x11] <<< 14 00 80 20 
1393 1738098149268 pro JtagIce3 [0x11] >>> 14 00 88 E2 0E 94 C0 01 83 FF FB CF 08 95 CF 93 E8 2F F9 2F C6 2F 90 81 91 15 D1 F0 31 96 20 E0 30 E0 5F E1 52 9F D0 01 53 9F B0 0D 11 24 9D 01 29 0F 31 1D 91 91 91 11 F5 CF 4C 1B 55 0B BA 01 6F 5F 7F 4F C9 01 0E 94 51 0C 8C 0F CF 91 08 95 20 E0 30 E0 F2 CF 87 E2 0E 94 C0 01 81 15 DC F7 08 95 0E 94 69 02 8C E0 0E 94 32 03 0E 94 6A 03 08 95 0E 94 72 02 80 E1 0E 94 32 03 0E 94 6A 03 08 95 00 
1393 1738098149268 pro JtagIce3 [0x11] <<< 06 00 00 03 80 
1393 1738098149269 pro JtagIce3 [0x11] >>> 06 00 
1393 1738098149269 pro JtagIce3 [0x11] <<< 14 00 80 20 
1393 1738098149303 pro JtagIce3 [0x11] >>> 14 00 EF 92 FF 92 0F 93 1F 93 CF 93 DF 93 CD B7 DE B7 19 85 0E 94 78 03 0E 94 70 03 81 E0 0E 94 CB 05 80 E8 0E 94 D2 05 01 2F 1D 33 08 F0 0C E3 84 E0 80 0F 0E 94 D2 05 8A 85 0E 94 D2 05 8B 85 0E 94 D2 05 8C 85 0E 94 D2 05 8D 85 0E 94 D2 05 11 15 69 F0 7E 01 8E E0 E8 0E F1 1C 10 E0 F7 01 81 91 7F 01 0E 94 D2 05 1F 5F 10 17 C0 F3 80 E0 0E 94 CB 05 0E 94 40 03 0E 94 78 03 DF 91 CF 91 1F 91 00 
1393 1738098149303 pro JtagIce3 [0x11] <<< 06 00 00 03 C0 
1393 1738098149305 pro JtagIce3 [0x11] >>> 06 00 
1393 1738098149305 pro JtagIce3 [0x11] <<< 14 00 80 20 
1393 1738098149339 pro JtagIce3 [0x11] >>> 14 00 0F 91 FF 90 EF 90 08 95 0F 93 1F 93 CF 93 DF 93 08 2F 19 2F 0E 94 78 03 C2 E0 D0 E0 8F EC 97 E0 01 97 F1 F7 00 C0 00 00 0C 17 1D 07 40 F0 88 E2 0E 94 C0 01 21 96 82 FF F1 CF 81 E0 01 C0 80 E0 DF 91 CF 91 1F 91 0F 91 08 95 0E 94 72 02 84 E0 0E 94 32 03 0E 94 6A 03 08 95 81 E0 0E 94 72 04 8F E1 9E E4 01 97 F1 F7 00 C0 00 00 80 E0 0E 94 72 04 8F E1 9E E4 01 97 F1 F7 00 C0 00 00 08 95 00 
1393 1738098149339 pro JtagIce3 [0x11] <<< 06 00 00 04 00 
1393 1738098149341 pro JtagIce3 [0x11] >>> 06 00 
1393 1738098149341 pro JtagIce3 [0x11] <<< 14 00 80 20 
1393 1738098149375 pro JtagIce3 [0x11] >>> 14 00 CF 93 DF 93 00 D0 CD B7 DE B7 0E 94 ED 03 2F EF 80 E7 92 E0 21 50 80 40 90 40 E1 F7 00 C0 00 00 0E 94 E5 03 6C E6 87 E0 0E 94 D3 01 60 E8 88 E0 0E 94 D3 01 60 E0 89 E0 0E 94 D3 01 60 E1 85 E0 0E 94 D3 01 6F E8 8C E3 0E 94 D3 01 60 E3 8F E6 0E 94 D3 01 8D E2 94 ED 9A 83 89 83 42 E0 BE 01 6F 5F 7F 4F 8F E2 0E 94 E9 01 68 E8 8E E2 0E 94 D3 01 61 E0 82 E0 0E 94 D3 01 60 E0 83 E0 0E 94 00 
1393 1738098149375 pro JtagIce3 [0x11] <<< 06 00 00 04 40 
1393 1738098149377 pro JtagIce3 [0x11] >>> 06 00 
1393 1738098149377 pro JtagIce3 [0x11] <<< 14 00 80 20 
1393 1738098149411 pro JtagIce3 [0x11] >>> 14 00 D3 01 60 E8 84 E0 0E 94 D3 01 60 E1 86 E0 0E 94 D3 01 60 E0 86 E0 0E 94 D3 01 60 EE 89 E1 0E 94 D3 01 60 EE 8A E1 0E 94 D3 01 60 ED 87 E3 0E 94 D3 01 60 E0 8C E2 0E 94 D3 01 64 E0 8D E2 0E 94 D3 01 6F E7 81 E1 0E 94 D3 01 0F 90 0F 90 DF 91 CF 91 08 95 39 9A 6B 9A 38 98 40 9A 80 E5 80 93 AC 00 08 95 3A 9A 81 15 11 F0 42 9A 08 95 42 98 08 95 3B 9A 81 15 11 F0 43 9A 08 95 43 98 08 95 00 
1393 1738098149411 pro JtagIce3 [0x11] <<< 06 00 00 04 80 
1393 1738098149412 pro JtagIce3 [0x11] >>> 06 00 
1393 1738098149412 pro JtagIce3 [0x11] <<< 14 00 80 20 
1393 1738098149447 pro JtagIce3 [0x11] >>> 14 00 10 92 B9 00 8C E0 80 93 B8 00 84 E0 80 93 BC 00 08 95 94 EA 90 93 BC 00 EC EB F0 E0 90 81 91 15 EC F7 80 93 BB 00 84 E8 80 93 BC 00 EC EB F0 E0 80 81 81 15 EC F7 90 91 B9 00 98 7F 98 31 31 F0 81 E0 90 34 09 F0 08 95 80 E0 08 95 80 E0 08 95 84 E9 80 93 BC 00 EC EB F0 E0 80 81 84 FF FD CF 08 95 84 EC 80 93 BC 00 EC EB F0 E0 80 81 81 15 EC F7 80 91 BB 00 08 95 80 93 BB 00 84 E8 80 93 00 
1393 1738098149447 pro JtagIce3 [0x11] <<< 06 00 00 04 C0 
1393 1738098149448 pro JtagIce3 [0x11] >>> 06 00 
1393 1738098149448 pro JtagIce3 [0x11] <<< 14 00 80 20 
1393 1738098149483 pro JtagIce3 [0x11] >>> 14 00 BC 00 EC EB F0 E0 80 81 81 15 EC F7 90 91 B9 00 98 7F 81 E0 98 32 09 F0 08 95 80 E0 08 95 EF 92 FF 92 0F 93 1F 93 CF 93 DF 93 C6 2F 04 2F 15 2F E2 2E 88 0F 0E 94 89 04 F8 2E 81 15 51 F0 FF 24 F3 94 8F 2D DF 91 CF 91 1F 91 0F 91 FF 90 EF 90 08 95 8C 2F 0E 94 BC 04 E1 14 49 F0 E8 01 0E 0D 11 1D 89 91 0E 94 BC 04 C0 17 D1 07 D1 F7 0E 94 A8 04 E7 CF CF 93 DF 93 0F 92 CD B7 DE B7 49 83 00 
1393 1738098149483 pro JtagIce3 [0x11] <<< 06 00 00 05 00 
1393 1738098149484 pro JtagIce3 [0x11] >>> 06 00 
1393 1738098149484 pro JtagIce3 [0x11] <<< 14 00 80 20 
1393 1738098149519 pro JtagIce3 [0x11] >>> 14 00 21 E0 AE 01 4F 5F 5F 4F 0E 94 CF 04 0F 90 DF 91 CF 91 08 95 84 E8 80 93 BC 00 EC EB F0 E0 80 81 81 15 EC F7 80 91 BB 00 08 95 AF 92 BF 92 DF 92 EF 92 FF 92 0F 93 1F 93 CF 93 DF 93 C8 2F F6 2E 04 2F 15 2F D2 2F 88 0F 0E 94 89 04 DD 24 D3 94 81 15 59 F0 8D 2D DF 91 CF 91 1F 91 0F 91 FF 90 EF 90 DF 90 BF 90 AF 90 08 95 8F 2D 0E 94 BC 04 8C 2F 88 0F 81 60 0E 94 89 04 D8 2E 81 11 1E C0 00 
1393 1738098149519 pro JtagIce3 [0x11] <<< 06 00 00 05 40 
1393 1738098149520 pro JtagIce3 [0x11] >>> 06 00 
1393 1738098149520 pro JtagIce3 [0x11] <<< 14 00 80 20 
1393 1738098149555 pro JtagIce3 [0x11] >>> 14 00 8D 2F 81 50 99 0B 5C 01 D2 30 60 F0 CD 2D 78 01 EC 0E F1 1C 0E 94 B1 04 F7 01 80 83 CF 5F CA 15 1B 04 AC F3 8D 2F 81 50 99 0B 08 0F 19 1F 0E 94 0A 05 F8 01 80 83 0E 94 A8 04 CC CF DD 24 D3 94 C9 CF 21 E0 0E 94 15 05 08 95 CF 93 DF 93 0F 92 CD B7 DE B7 AE 01 4F 5F 5F 4F 0E 94 61 05 89 81 0F 90 DF 91 CF 91 08 95 AF 92 BF 92 DF 92 EF 92 FF 92 0F 93 1F 93 CF 93 DF 93 C8 2F F6 2E E7 2E 00 
1393 1738098149555 pro JtagIce3 [0x11] <<< 06 00 00 05 80 
1393 1738098149556 pro JtagIce3 [0x11] >>> 06 00 
1393 1738098149556 pro JtagIce3 [0x11] <<< 14 00 80 20 
1393 1738098149591 pro JtagIce3 [0x11] >>> 14 00 04 2F 15 2F D2 2F 88 0F 0E 94 89 04 DD 24 D3 94 81 15 59 F0 8D 2D DF 91 CF 91 1F 91 0F 91 FF 90 EF 90 DF 90 BF 90 AF 90 08 95 8E 2D 0E 94 BC 04 8F 2D 0E 94 BC 04 8C 2F 88 0F 81 60 0E 94 89 04 D8 2E 81 11 1E C0 8D 2F 81 50 99 0B 5C 01 D2 30 60 F0 CD 2D 78 01 EC 0E F1 1C 0E 94 B1 04 F7 01 80 83 CF 5F CA 15 1B 04 AC F3 8D 2F 81 50 99 0B 08 0F 19 1F 0E 94 0A 05 F8 01 80 83 0E 94 A8 04 00 
1393 1738098149591 pro JtagIce3 [0x11] <<< 06 00 00 05 C0 
1393 1738098149592 pro JtagIce3 [0x11] >>> 06 00 
1393 1738098149592 pro JtagIce3 [0x11] <<< 14 00 80 20 
1393 1738098149627 pro JtagIce3 [0x11] >>> 14 00 C9 CF DD 24 D3 94 C6 CF 20 9A 81 11 02 C0 28 9A 08 95 28 98 08 95 6A 9A 81 11 02 C0 72 9A 08 95 72 98 08 95 80 93 AE 00 ED EA F0 E0 80 81 81 15 EC F7 80 91 AE 00 08 95 8F EF 0E 94 D2 05 08 95 FF 92 0F 93 1F 93 CF 93 DF 93 18 2F D9 2F F6 2E 07 2F C4 2F 44 E1 50 E0 60 E2 70 E0 86 E2 93 E0 0E 94 A4 0C AF 2D B0 2F 50 E0 30 E0 03 C0 3F 5F 3C 17 60 F4 2D 91 21 15 49 F0 20 32 C1 F3 E5 2F 00 
1393 1738098149627 pro JtagIce3 [0x11] <<< 06 00 00 06 00 
1393 1738098149628 pro JtagIce3 [0x11] >>> 06 00 
1393 1738098149628 pro JtagIce3 [0x11] <<< 14 00 80 20 
1393 1738098149663 pro JtagIce3 [0x11] >>> 14 00 F0 E0 EA 5D FC 4F 20 83 5F 5F F1 CF 25 2F 30 E0 30 93 3C 03 20 93 3B 03 87 E1 E6 E2 F3 E0 A1 2F BD 2F 01 90 0D 92 8A 95 E1 F7 81 2F 9D 2F DF 91 CF 91 1F 91 0F 91 FF 90 08 95 55 9A 81 15 11 F0 5D 9A 08 95 5D 98 08 95 68 9A 81 15 11 F0 70 9A 08 95 70 98 08 95 26 2F 64 2F 75 2F 48 2F 59 2F 83 E5 0E 94 74 05 08 95 0F 93 1F 93 CF 93 DF 93 CD B7 DE B7 CE 5F D1 09 0F B6 F8 94 DE BF 0F BE 00 
1393 1738098149663 pro JtagIce3 [0x11] <<< 06 00 00 06 40 
1393 1738098149664 pro JtagIce3 [0x11] >>> 06 00 
1393 1738098149664 pro JtagIce3 [0x11] <<< 14 00 80 20 
1393 1738098149698 pro JtagIce3 [0x11] >>> 14 00 CD BF 08 2F 19 2F 80 E0 0E 94 1D 06 81 E0 0E 94 24 06 8F E1 9E E4 01 97 F1 F7 00 C0 00 00 44 E0 50 E0 6E EF CE 01 01 96 0E 94 2B 06 BE 01 6F 5F 7F 4F 80 2F 91 2F 0E 94 73 09 81 E0 0E 94 1D 06 80 2F 91 2F C2 50 DF 4F 0F B6 F8 94 DE BF 0F BE CD BF DF 91 CF 91 1F 91 0F 91 08 95 AF 92 BF 92 CF 92 DF 92 EF 92 FF 92 0F 93 1F 93 CF 93 DF 93 CD B7 DE B7 C8 51 D1 40 0F B6 F8 94 DE BF 0F BE 00 
1393 1738098149698 pro JtagIce3 [0x11] <<< 06 00 00 06 80 
1393 1738098149699 pro JtagIce3 [0x11] >>> 06 00 
1393 1738098149699 pro JtagIce3 [0x11] <<< 14 00 80 20 
1393 1738098149734 pro JtagIce3 [0x11] >>> 14 00 CD BF E8 2E F9 2E CE 01 01 96 0E 94 34 06 CE 01 02 96 0E 94 98 00 89 E7 91 E0 0E 94 98 00 49 81 BE 01 6E 5F 7F 4F CE 01 8E 5F 9E 4F 0E 94 E0 05 87 E1 FE 01 EE 5F FE 4F AC E0 B2 E0 01 90 0D 92 8A 95 E1 F7 8C E0 92 E0 0E 94 98 00 89 E7 91 E0 0E 94 98 00 6C E2 70 E0 8C E0 92 E0 0E 94 AB 0C 08 2F 19 2F 01 15 11 05 09 F4 46 C0 0C 50 12 40 68 01 DD 24 0F 2E FC E0 AF 2E F2 E0 BF 2E F0 2D 00 
1393 1738098149734 pro JtagIce3 [0x11] <<< 06 00 00 06 C0 
1393 1738098149735 pro JtagIce3 [0x11] >>> 06 00 
1393 1738098149735 pro JtagIce3 [0x11] <<< 14 00 80 20 
1393 1738098149770 pro JtagIce3 [0x11] >>> 14 00 A6 01 B5 01 84 E2 92 E0 0E 94 9B 0C F5 01 15 89 56 89 B6 01 63 5F 7D 4F 41 2F 84 EA 92 E0 0E 94 9B 0C 00 93 23 02 10 1B 10 93 24 03 4B E3 60 E0 84 E2 92 E0 0E 94 46 03 80 93 25 03 83 E0 91 E0 E3 E2 F2 E0 AE 2D BF 2D 01 90 0D 92 01 97 E1 F7 8E 2D 9F 2D C8 5E DE 4F 0F B6 F8 94 DE BF 0F BE CD BF DF 91 CF 91 1F 91 0F 91 FF 90 EF 90 DF 90 CF 90 BF 90 AF 90 08 95 EC E0 F2 E0 15 89 56 89 00 
1393 1738098149770 pro JtagIce3 [0x11] <<< 06 00 00 07 00 
1393 1738098149771 pro JtagIce3 [0x11] >>> 06 00 
1393 1738098149771 pro JtagIce3 [0x11] <<< 14 00 80 20 
1393 1738098149806 pro JtagIce3 [0x11] >>> 14 00 41 2F BF 01 84 E2 92 E0 0E 94 9B 0C 10 93 23 02 E4 EA F2 E0 8E E4 9F E2 91 83 80 83 81 E4 82 83 13 E0 C2 CF 53 98 5B 98 08 95 E9 E6 F0 E0 80 81 88 60 80 83 80 81 8B 7F 80 83 E9 9A 08 95 E9 E6 F0 E0 80 81 82 60 80 83 80 81 8E 7F 80 83 E8 9A 08 95 F8 94 A8 95 E0 E6 F0 E0 80 81 88 61 80 83 85 E0 80 83 80 81 80 64 80 83 78 94 08 95 F8 94 E0 E6 F0 E0 80 81 88 61 80 83 10 82 78 94 08 95 00 
1393 1738098149806 pro JtagIce3 [0x11] <<< 06 00 00 07 40 
1393 1738098149807 pro JtagIce3 [0x11] >>> 06 00 
1393 1738098149807 pro JtagIce3 [0x11] <<< 14 00 80 20 
1393 1738098149842 pro JtagIce3 [0x11] >>> 14 00 CF 93 DF 93 00 D0 0F 92 CD B7 DE B7 80 E8 89 83 8A 83 8B 83 23 E0 AE 01 4F 5F 5F 4F 63 E1 88 E6 0E 94 CF 04 0F 90 0F 90 0F 90 DF 91 CF 91 08 95 68 2F 88 E6 0E 94 65 05 08 95 80 E0 0E 94 58 07 08 95 81 E0 0E 94 58 07 08 95 4A E0 64 E0 88 E6 0E 94 FA 04 08 95 42 E0 61 E0 88 E6 0E 94 FA 04 08 95 48 2F 59 2F 27 E0 66 E0 88 E6 0E 94 15 05 08 95 CF 93 DF 93 00 D0 00 D0 00 D0 0F 92 CD B7 00 
1393 1738098149842 pro JtagIce3 [0x11] <<< 06 00 00 07 80 
1393 1738098149843 pro JtagIce3 [0x11] >>> 06 00 
1393 1738098149843 pro JtagIce3 [0x11] <<< 14 00 80 20 
1393 1738098149878 pro JtagIce3 [0x11] >>> 14 00 DE B7 86 EC 93 E0 0E 94 71 07 A6 EC B3 E0 9C 91 EF EB F3 E0 89 2F 82 95 8F 70 28 2F 22 0F 22 0F 82 1B 88 0F 89 0F 80 83 11 96 9C 91 11 97 89 2F 82 95 8F 70 28 2F 22 0F 22 0F 82 1B 88 0F 89 0F 81 83 12 96 9C 91 12 97 89 2F 82 95 8F 70 8B 70 28 2F 22 0F 22 0F 82 1B 88 0F 9F 7B 89 0F 82 83 13 96 8C 91 13 97 83 83 14 96 9C 91 14 97 89 2F 82 95 8F 70 28 2F 22 0F 22 0F 82 1B 88 0F 89 0F 00 
1393 1738098149878 pro JtagIce3 [0x11] <<< 06 00 00 07 C0 
1393 1738098149879 pro JtagIce3 [0x11] >>> 06 00 
1393 1738098149879 pro JtagIce3 [0x11] <<< 14 00 80 20 
1393 1738098149914 pro JtagIce3 [0x11] >>> 14 00 84 83 15 96 9C 91 15 97 89 2F 82 95 8F 70 87 70 28 2F 22 0F 22 0F 82 1B 88 0F 9F 77 89 0F 85 83 16 96 9C 91 89 2F 82 95 8F 70 28 2F 22 0F 22 0F 82 1B 88 0F 9E 51 89 0F 86 83 87 E0 DE 01 11 96 01 90 0D 92 8A 95 E1 F7 29 81 3A 81 4B 81 5C 81 6D 81 7E 81 8F 81 90 E0 27 96 0F B6 F8 94 DE BF 0F BE CD BF DF 91 CF 91 08 95 AF 92 BF 92 CF 92 DF 92 EF 92 FF 92 0F 93 1F 93 CF 93 DF 93 00 D0 00 
1393 1738098149914 pro JtagIce3 [0x11] <<< 06 00 00 08 00 
1393 1738098149915 pro JtagIce3 [0x11] >>> 06 00 
1393 1738098149915 pro JtagIce3 [0x11] <<< 14 00 80 20 
1393 1738098149950 pro JtagIce3 [0x11] >>> 14 00 00 D0 00 D0 0F 92 CD B7 DE B7 A2 2E B3 2E C4 2E 5C 83 D6 2E E7 2E F8 2E 80 ED 0E 94 89 04 18 2F 81 15 99 F0 11 E0 81 2F 27 96 0F B6 F8 94 DE BF 0F BE CD BF DF 91 CF 91 1F 91 0F 91 FF 90 EF 90 DF 90 CF 90 BF 90 AF 90 08 95 86 E0 0E 94 BC 04 0D EC A0 9E 91 2D 11 24 96 95 96 95 96 95 89 2F 88 0F 89 0F 88 0F 8A 0D 0E 94 BC 04 B0 9E 91 2D 11 24 96 95 96 95 96 95 89 2F 88 0F 89 0F 88 0F 00 
1393 1738098149950 pro JtagIce3 [0x11] <<< 06 00 00 08 40 
1393 1738098149951 pro JtagIce3 [0x11] >>> 06 00 
1393 1738098149951 pro JtagIce3 [0x11] <<< 14 00 80 20 
1393 1738098149986 pro JtagIce3 [0x11] >>> 14 00 8B 0D 0E 94 BC 04 C0 9E 91 2D 11 24 96 95 96 95 96 95 89 2F 88 0F 89 0F 88 0F 8C 0D 0E 94 BC 04 8C 81 0E 94 BC 04 D0 9E 91 2D 11 24 96 95 96 95 96 95 89 2F 88 0F 89 0F 88 0F 8D 0D 0E 94 BC 04 E0 9E 01 2D 11 24 06 95 06 95 06 95 80 2F 88 0F 80 0F 88 0F 8E 0D 0E 94 BC 04 8F 2D 90 E0 6A E0 70 E0 0E 94 65 0C 6D 5F 7F 4F 86 2F 88 0F 86 0F 88 0F 9E E1 9F 0D 89 0F 0E 94 BC 04 0E 94 A8 04 00 
1393 1738098149986 pro JtagIce3 [0x11] <<< 06 00 00 08 80 
1393 1738098149987 pro JtagIce3 [0x11] >>> 06 00 
1393 1738098149987 pro JtagIce3 [0x11] <<< 14 00 80 20 
1393 1738098150021 pro JtagIce3 [0x11] >>> 14 00 92 CF CF 93 DF 93 CD B7 DE B7 C8 54 D1 09 0F B6 F8 94 DE BF 0F BE CD BF 0E 94 00 04 8F EC 97 E0 01 97 F1 F7 00 C0 00 00 8E E7 93 E0 0E 94 7B 02 2E 96 4F AD 2E 97 4B 30 08 F0 4A E0 50 E0 BE 01 62 5B 7F 4F 83 E8 93 E0 0E 94 9B 0C C2 5B DE 4F 48 81 CE 54 D1 40 4B 30 08 F0 4A E0 50 E0 BE 01 62 53 7F 4F 8D E8 93 E0 0E 94 9B 0C EE E7 F3 E0 84 E1 80 83 81 E0 84 83 83 83 8D B7 9E B7 81 54 00 
1393 1738098150021 pro JtagIce3 [0x11] <<< 06 00 00 08 C0 
1393 1738098150022 pro JtagIce3 [0x11] >>> 06 00 
1393 1738098150022 pro JtagIce3 [0x11] <<< 14 00 80 20 
1393 1738098150057 pro JtagIce3 [0x11] >>> 14 00 91 09 0F B6 F8 94 9E BF 0F BE 8D BF AD B7 BE B7 11 96 81 E4 01 90 0D 92 8A 95 E1 F7 0E 94 80 03 0F B6 F8 94 DE BF 0F BE CD BF 84 E6 90 E0 0E 94 C4 03 81 15 09 F4 47 C0 CE 01 08 96 0E 94 75 01 81 E4 FE 01 38 96 AD E3 B3 E0 01 90 0D 92 8A 95 E1 F7 80 91 41 03 82 30 59 F0 82 E0 C8 5B DF 4F 0F B6 F8 94 DE BF 0F BE CD BF DF 91 CF 91 08 95 8D B7 9E B7 81 54 91 09 0F B6 F8 94 9E BF 0F BE 00 
1393 1738098150057 pro JtagIce3 [0x11] <<< 06 00 00 09 00 
1393 1738098150058 pro JtagIce3 [0x11] >>> 06 00 
1393 1738098150058 pro JtagIce3 [0x11] <<< 14 00 80 20 
1393 1738098150093 pro JtagIce3 [0x11] >>> 14 00 8D BF AD B7 BE B7 11 96 81 E4 ED E3 F3 E0 01 90 0D 92 8A 95 E1 F7 0E 94 4D 01 C1 5B DE 4F 28 81 CF 54 D1 40 ED E3 F3 E0 36 81 47 81 60 85 71 85 53 85 0F B6 F8 94 DE BF 0F BE CD BF 82 85 0E 94 F5 07 81 E0 CB CF 8F E2 91 E0 0E 94 98 00 82 E0 C5 CF 80 E4 80 93 7C 00 10 92 7B 00 81 E8 80 93 7A 00 80 E0 08 95 EA E7 F0 E0 80 81 8F 77 80 83 08 95 EA E7 F0 E0 80 81 80 68 80 83 08 95 81 11 00 
1393 1738098150093 pro JtagIce3 [0x11] <<< 06 00 00 09 40 
1393 1738098150094 pro JtagIce3 [0x11] >>> 06 00 
1393 1738098150094 pro JtagIce3 [0x11] <<< 14 00 80 20 
1393 1738098150129 pro JtagIce3 [0x11] >>> 14 00 09 C0 80 E4 80 93 7C 00 EA E7 F0 E0 80 81 80 64 80 83 08 95 8E 30 49 F0 EC E7 F0 E0 90 81 90 7F 90 83 90 81 89 2B 80 83 EF CF 8E E4 80 93 7C 00 EB CF 80 91 7A 00 82 95 81 70 08 95 80 91 78 00 90 91 79 00 08 95 0E 94 3F 09 0E 94 59 09 81 15 E1 F3 0E 94 5E 09 9C 01 EA E7 F0 E0 90 81 90 61 90 83 C9 01 08 95 2F 92 3F 92 5F 92 6F 92 7F 92 8F 92 9F 92 AF 92 BF 92 CF 92 DF 92 EF 92 FF 92 00 
1393 1738098150129 pro JtagIce3 [0x11] <<< 06 00 00 09 80 
1393 1738098150130 pro JtagIce3 [0x11] >>> 06 00 
1393 1738098150130 pro JtagIce3 [0x11] <<< 14 00 80 20 
1393 1738098150165 pro JtagIce3 [0x11] >>> 14 00 0F 93 1F 93 CF 93 DF 93 00 D0 CD B7 DE B7 26 2E 37 2E 2D B7 3E B7 3A 83 29 83 10 92 CD 04 D1 01 2C 91 23 30 49 F1 21 E0 20 93 CD 04 21 E0 31 E0 ED EC F3 E0 A8 2F B9 2F 01 90 0D 92 21 50 30 40 D9 F7 E9 81 FA 81 0F B6 F8 94 FE BF 0F BE ED BF 0F 90 0F 90 DF 91 CF 91 1F 91 0F 91 FF 90 EF 90 DF 90 CF 90 BF 90 AF 90 9F 90 8F 90 7F 90 6F 90 5F 90 3F 90 2F 90 08 95 F1 01 21 81 2F 3F 09 F4 00 
1393 1738098150165 pro JtagIce3 [0x11] <<< 06 00 00 09 C0 
1393 1738098150166 pro JtagIce3 [0x11] >>> 06 00 
1393 1738098150166 pro JtagIce3 [0x11] <<< 14 00 80 20 
1393 1738098150201 pro JtagIce3 [0x11] >>> 14 00 4E C0 D1 01 12 96 9C 90 B9 2D B8 70 7B 2E F1 01 43 81 84 80 6B 2E 65 E0 70 E0 93 FE 03 C0 65 80 66 E0 70 E0 04 2F 10 E0 98 01 2F 5F 3F 4F AD B7 BE B7 A2 1B B3 0B 0F B6 F8 94 BE BF 0F BE AD BF ED B7 FE B7 31 96 7F 01 41 15 E9 F0 5B 01 F1 01 E6 0F F7 1F 97 01 55 24 5A 94 54 0E C5 2C D1 2C A1 01 4F 5F 5F 4F 45 0D 51 1D 46 0F 57 1F 61 91 D9 01 6D 93 9D 01 E4 17 F5 07 C9 F7 B6 01 6F 5F 00 
1393 1738098150201 pro JtagIce3 [0x11] <<< 06 00 00 0A 00 
1393 1738098150202 pro JtagIce3 [0x11] >>> 06 00 
1393 1738098150202 pro JtagIce3 [0x11] <<< 14 00 80 20 
1393 1738098150237 pro JtagIce3 [0x11] >>> 14 00 7F 4F 6A 0D 7B 1D F7 01 E0 0F F1 1F 10 82 F7 01 20 81 24 35 41 F0 2B E0 20 93 CD 04 87 CF 22 E0 20 93 CD 04 83 CF 29 2D 27 70 21 30 21 F0 2C E0 20 93 CD 04 7B CF 71 14 11 F0 66 0D 71 1D F1 01 E6 0F F7 1F 20 81 62 0F 71 1D FB 01 31 96 8A 94 58 2D 52 1B 82 16 A1 F0 E2 0D F3 1D 2E EC 33 E0 D1 01 12 96 A6 0F B7 1F 4F EF 45 0F BD 01 64 0F 71 1D 41 91 D9 01 4D 93 9D 01 E6 17 F7 07 C9 F7 00 
1393 1738098150237 pro JtagIce3 [0x11] <<< 06 00 00 0A 40 
1393 1738098150238 pro JtagIce3 [0x11] >>> 06 00 
1393 1738098150238 pro JtagIce3 [0x11] <<< 14 00 80 20 
1393 1738098150272 pro JtagIce3 [0x11] >>> 14 00 50 93 CD 03 53 CF 8F 93 81 E0 80 93 F1 04 8F 91 18 95 1F 92 0F 92 0F B6 0F 92 11 24 2F 93 3F 93 4F 93 5F 93 6F 93 7F 93 8F 93 9F 93 AF 93 BF 93 EF 93 FF 93 81 E0 80 93 F0 04 80 91 F2 04 81 15 89 F0 FF 91 EF 91 BF 91 AF 91 9F 91 8F 91 7F 91 6F 91 5F 91 4F 91 3F 91 2F 91 0F 90 0F BE 0F 90 1F 90 18 95 81 E0 80 93 F2 04 0E 94 29 07 E9 CF 1F 92 0F 92 0F B6 0F 92 11 24 2F 93 3F 93 4F 93 00 
1393 1738098150272 pro JtagIce3 [0x11] <<< 06 00 00 0A 80 
1393 1738098150273 pro JtagIce3 [0x11] >>> 06 00 
1393 1738098150273 pro JtagIce3 [0x11] <<< 14 00 80 20 
1393 1738098150308 pro JtagIce3 [0x11] >>> 14 00 5F 93 6F 93 7F 93 8F 93 9F 93 AF 93 BF 93 EF 93 FF 93 10 92 F2 04 0E 94 37 07 FF 91 EF 91 BF 91 AF 91 9F 91 8F 91 7F 91 6F 91 5F 91 4F 91 3F 91 2F 91 0F 90 0F BE 0F 90 1F 90 18 95 F8 94 81 E0 0E 94 1D 06 80 E0 0E 94 24 06 80 E0 0E 94 C4 05 80 E0 0E 94 CB 05 80 E0 0E 94 79 04 85 B7 80 66 85 BF 8F 7D 85 BF 83 B7 81 7F 84 60 83 BF 83 B7 81 60 83 BF 78 94 88 95 08 95 0E 94 39 09 8E E0 00 
1393 1738098150308 pro JtagIce3 [0x11] <<< 06 00 00 0A C0 
1393 1738098150309 pro JtagIce3 [0x11] >>> 06 00 
1393 1738098150309 pro JtagIce3 [0x11] <<< 14 00 80 20 
1393 1738098150344 pro JtagIce3 [0x11] >>> 14 00 0E 94 63 09 8E E0 0E 94 63 09 8E E0 0E 94 63 09 90 93 F7 05 80 93 F6 05 0E 94 33 09 80 91 F6 05 90 91 F7 05 08 95 CD B7 DE B7 CA 50 D1 40 0F B6 F8 94 DE BF 0F BE CD BF 81 E0 0E 94 79 04 8F E1 9E E4 01 97 F1 F7 00 C0 00 00 0E 94 12 07 0E 94 84 00 80 E4 91 E0 0E 94 98 00 0E 94 80 04 0E 94 6A 04 0E 94 29 09 0E 94 15 07 0E 94 1F 07 0F 2E FF EC CF 2E F4 E0 DF 2E F0 2D 0D EE 14 E0 F6 01 00 
1393 1738098150344 pro JtagIce3 [0x11] <<< 06 00 00 0B 00 
1393 1738098150345 pro JtagIce3 [0x11] >>> 06 00 
1393 1738098150345 pro JtagIce3 [0x11] <<< 14 00 80 20 
1393 1738098150380 pro JtagIce3 [0x11] >>> 14 00 11 92 11 92 E0 17 F1 07 D9 F7 CE 01 08 96 0E 94 6E 06 83 E0 91 E0 FE 01 38 96 A3 EF B4 E0 01 90 0D 92 01 97 E1 F7 8D B7 9E B7 83 50 91 40 0F B6 F8 94 9E BF 0F BE 8D BF AD B7 BE B7 11 96 83 E0 91 E0 E3 EF F4 E0 01 90 0D 92 01 97 E1 F7 0E 94 81 08 80 93 CE 04 9F EF 20 E7 82 E0 91 50 20 40 80 40 E1 F7 00 C0 00 00 0F B6 F8 94 DE BF 0F BE CD BF 0E 94 40 07 0E 94 65 07 0E 94 6B 07 0E 94 00 
1393 1738098150380 pro JtagIce3 [0x11] <<< 06 00 00 0B 40 
1393 1738098150381 pro JtagIce3 [0x11] >>> 06 00 
1393 1738098150381 pro JtagIce3 [0x11] <<< 14 00 80 20 
1393 1738098150416 pro JtagIce3 [0x11] >>> 14 00 61 07 0E 94 5D 07 0F 2E FF EC EF 2E F4 E0 FF 2E F0 2D 04 C0 80 91 F1 04 81 11 21 C0 8C E7 91 E0 0E 94 98 00 80 E0 0E 94 CB 05 80 E0 0E 94 C4 05 0E 94 79 00 0E 94 9E 0A 80 91 F0 04 81 15 51 F3 10 92 F0 04 E0 91 EF 04 F0 E0 EE 0F FF 1F E1 53 FB 4F 80 81 91 81 01 96 91 83 80 83 DB CF 10 92 F1 04 80 91 EF 04 8F 5F 80 93 EF 04 0E 94 61 07 0E 94 5D 07 83 E8 91 E0 0E 94 98 00 0E 94 79 00 00 
1393 1738098150416 pro JtagIce3 [0x11] <<< 06 00 00 0B 80 
1393 1738098150417 pro JtagIce3 [0x11] >>> 06 00 
1393 1738098150417 pro JtagIce3 [0x11] <<< 14 00 80 20 
1393 1738098150452 pro JtagIce3 [0x11] >>> 14 00 0E 94 61 07 0E 94 5D 07 81 E0 0E 94 79 04 0E 94 00 04 81 E0 0E 94 24 06 80 E0 0E 94 1D 06 CE 01 08 96 0E 94 6E 06 83 E0 91 E0 FE 01 38 96 A3 EF B4 E0 01 90 0D 92 01 97 E1 F7 80 91 EF 04 83 30 08 F4 AC CF 10 92 EF 04 80 91 CE 04 82 30 09 F4 8A C0 88 EF 95 E0 0E 94 7B 02 0E 94 BD 0A B8 2E A9 2E 0E 94 79 07 29 83 3A 83 4B 83 5C 83 6D 83 7E 83 8F 83 FF 92 EF 92 AF 92 BF 92 00 D0 00 D0 00 
1393 1738098150452 pro JtagIce3 [0x11] <<< 06 00 00 0B C0 
1393 1738098150453 pro JtagIce3 [0x11] >>> 06 00 
1393 1738098150453 pro JtagIce3 [0x11] <<< 14 00 80 20 
1393 1738098150488 pro JtagIce3 [0x11] >>> 14 00 00 D0 0F 92 AD B7 BE B7 11 96 87 E0 FE 01 31 96 01 90 0D 92 8A 95 E1 F7 8D B7 9E B7 83 50 91 40 0F B6 F8 94 9E BF 0F BE 8D BF AD B7 BE B7 11 96 83 E0 91 E0 E3 EF F4 E0 01 90 0D 92 01 97 E1 F7 CE 01 08 96 0E 94 8C 02 81 E4 FE 01 38 96 A8 EF B5 E0 01 90 0D 92 8A 95 E1 F7 0F B6 F8 94 DE BF 0F BE CD BF 8F E9 91 E0 0E 94 98 00 8D B7 9E B7 81 54 91 09 0F B6 F8 94 9E BF 0F BE 8D BF AD B7 00 
1393 1738098150488 pro JtagIce3 [0x11] <<< 06 00 00 0C 00 
1393 1738098150489 pro JtagIce3 [0x11] >>> 06 00 
1393 1738098150489 pro JtagIce3 [0x11] <<< 14 00 80 20 
1393 1738098150524 pro JtagIce3 [0x11] >>> 14 00 BE B7 11 96 81 E4 E8 EF F5 E0 01 90 0D 92 8A 95 E1 F7 0E 94 4D 01 8D B7 9E B7 8F 5B 9F 4F 0F B6 F8 94 DE BF 0F BE CD BF 81 54 91 09 0F B6 F8 94 9E BF 0F BE 8D BF AD B7 BE B7 11 96 81 E4 E8 EF F5 E0 01 90 0D 92 8A 95 E1 F7 0E 94 80 03 0F B6 F8 94 DE BF 0F BE CD BF F6 01 11 92 11 92 E0 17 F1 07 D9 F7 1B CF 8D B7 9E B7 83 50 91 40 0F B6 F8 94 9E BF 0F BE 8D BF AD B7 BE B7 11 96 83 E0 00 
1393 1738098150524 pro JtagIce3 [0x11] <<< 06 00 00 0C 40 
1393 1738098150525 pro JtagIce3 [0x11] >>> 06 00 
1393 1738098150525 pro JtagIce3 [0x11] <<< 14 00 80 20 
1393 1738098150560 pro JtagIce3 [0x11] >>> 14 00 91 E0 E3 EF F4 E0 01 90 0D 92 01 97 E1 F7 0E 94 81 08 80 93 CE 04 0F B6 F8 94 DE BF 0F BE CD BF 58 CF AA 1B BB 1B 51 E1 07 C0 AA 1F BB 1F A6 17 B7 07 10 F0 A6 1B B7 0B 88 1F 99 1F 5A 95 A9 F7 80 95 90 95 BC 01 CD 01 08 95 97 FB 07 2E 16 F4 00 94 07 D0 77 FD 09 D0 0E 94 51 0C 07 FC 05 D0 3E F4 90 95 81 95 9F 4F 08 95 70 95 61 95 7F 4F 08 95 A1 E2 1A 2E AA 1B BB 1B FD 01 0D C0 AA 1F 00 
1393 1738098150560 pro JtagIce3 [0x11] <<< 06 00 00 0C 80 
1393 1738098150561 pro JtagIce3 [0x11] >>> 06 00 
1393 1738098150561 pro JtagIce3 [0x11] <<< 14 00 80 20 
1393 1738098150596 pro JtagIce3 [0x11] >>> 14 00 BB 1F EE 1F FF 1F A2 17 B3 07 E4 07 F5 07 20 F0 A2 1B B3 0B E4 0B F5 0B 66 1F 77 1F 88 1F 99 1F 1A 94 69 F7 60 95 70 95 80 95 90 95 9B 01 AC 01 BD 01 CF 01 08 95 FB 01 DC 01 02 C0 01 90 0D 92 41 50 50 40 D8 F7 08 95 DC 01 01 C0 6D 93 41 50 50 40 E0 F7 08 95 FC 01 81 91 86 17 21 F0 88 23 D9 F7 99 27 08 95 31 97 CF 01 08 95 AE E0 B0 E0 EC EB FC E0 0C 94 86 0F 0D 89 1E 89 86 E0 8C 83 00 
1393 1738098150596 pro JtagIce3 [0x11] <<< 06 00 00 0C C0 
1393 1738098150597 pro JtagIce3 [0x11] >>> 06 00 
1393 1738098150597 pro JtagIce3 [0x11] <<< 14 00 80 20 
1393 1738098150632 pro JtagIce3 [0x11] >>> 14 00 1A 83 09 83 8F 89 98 8D 81 30 20 E8 92 07 10 F0 80 E0 90 E8 01 97 9E 83 8D 83 AE 01 45 5E 5F 4F 69 8D 7A 8D CE 01 01 96 0E 94 E8 0C 4D 81 5E 81 57 FD 0A C0 2F 81 38 85 42 17 53 07 0C F4 9A 01 02 0F 13 1F F8 01 10 82 2E 96 E4 E0 0C 94 A2 0F AB E0 B0 E0 EE EE FC E0 0C 94 79 0F 6C 01 7B 01 8A 01 FC 01 17 82 16 82 83 81 81 FF DA C1 9A E0 49 2E F6 01 23 81 F7 01 23 FD 85 91 23 FF 81 91 00 
1393 1738098150632 pro JtagIce3 [0x11] <<< 06 00 00 0D 00 
1393 1738098150633 pro JtagIce3 [0x11] >>> 06 00 
1393 1738098150633 pro JtagIce3 [0x11] <<< 14 00 80 20 
1393 1738098150667 pro JtagIce3 [0x11] >>> 14 00 7F 01 81 15 09 F4 1F C1 85 32 39 F4 23 FD 95 91 23 FF 91 91 7F 01 95 32 29 F4 B6 01 90 E0 0E 94 EA 0E E7 CF 30 E0 61 2C 51 2C 71 2C F0 E2 7F 16 40 F5 9B 32 D9 F0 58 F4 90 32 D1 F0 93 32 F1 F0 9E 32 99 F5 76 FC FF C0 68 94 76 F8 06 C0 9D 32 91 F0 90 33 C1 F4 68 94 70 F8 F7 01 23 FD 95 91 23 FF 91 91 7F 01 91 11 E1 CF 29 C0 68 94 71 F8 68 94 72 F8 F2 CF 68 94 73 F8 EF CF 68 94 74 F8 00 
1393 1738098150667 pro JtagIce3 [0x11] <<< 06 00 00 0D 40 
1393 1738098150669 pro JtagIce3 [0x11] >>> 06 00 
1393 1738098150669 pro JtagIce3 [0x11] <<< 14 00 80 20 
1393 1738098150703 pro JtagIce3 [0x11] >>> 14 00 EC CF 77 FC 1C C0 80 ED 89 0F 8A 30 C8 F6 76 FE 05 C0 64 9C 80 0D 11 24 68 2E DF CF 54 9C 80 0D 11 24 58 2E 68 94 75 F8 D8 CF 9C 36 19 F4 68 94 77 F8 D3 CF 9C 34 09 F4 4B C0 98 36 71 F2 89 2F 8F 7D 85 54 83 30 08 F4 45 C0 93 36 09 F4 66 C0 93 37 09 F4 69 C0 93 35 09 F4 75 C0 94 36 19 F0 99 36 09 F0 9F C0 F8 01 77 FE 95 C0 61 91 71 91 81 91 91 91 8F 01 27 2D 2F 76 72 2E 97 FF 09 C0 00 
1393 1738098150703 pro JtagIce3 [0x11] <<< 06 00 00 0D 80 
1393 1738098150705 pro JtagIce3 [0x11] >>> 06 00 
1393 1738098150705 pro JtagIce3 [0x11] <<< 14 00 80 20 
1393 1738098150739 pro JtagIce3 [0x11] >>> 14 00 90 95 80 95 70 95 61 95 7F 4F 8F 4F 9F 4F 68 94 77 F8 2A E0 30 E0 AE 01 4F 5F 5F 4F 5A 01 0E 94 1A 0F 8A 19 A8 2E 76 FE C5 C0 87 2D 8E 7F A6 14 08 F0 BF C0 74 FE 12 C1 72 FC 06 C1 F7 2D FE 7E 7F 2E B6 2C 87 2D 86 78 81 15 09 F4 C0 C0 01 C1 31 E0 83 CF 31 15 F9 F0 08 5F 1F 4F 8F E3 89 83 88 24 83 94 91 2C AE 01 4F 5F 5F 4F 5A 01 E8 94 77 F8 73 FC 03 C0 85 14 91 04 B0 F1 81 14 91 04 00 
1393 1738098150739 pro JtagIce3 [0x11] <<< 06 00 00 0D C0 
1393 1738098150741 pro JtagIce3 [0x11] >>> 06 00 
1393 1738098150741 pro JtagIce3 [0x11] <<< 14 00 80 20 
1393 1738098150775 pro JtagIce3 [0x11] >>> 14 00 D1 F5 51 14 09 F4 35 CF B6 01 80 E2 90 E0 0E 94 EA 0E 5A 94 F6 CF 0C 5F 1F 4F E0 CF F8 01 80 81 89 83 0E 5F 1F 4F DC CF F8 01 A1 90 B1 90 8F 01 66 2D 70 E0 76 FC 02 C0 6F EF 7F EF C5 01 0E 94 DF 0E 4C 01 D4 CF F8 01 A1 90 B1 90 8F 01 66 2D 70 E0 76 FC 02 C0 6F EF 7F EF C5 01 0E 94 D4 0E 4C 01 68 94 77 F8 C5 CF B6 01 80 E2 90 E0 0E 94 EA 0E 5A 94 C0 CF F5 01 77 FC 85 91 77 FE 81 91 00 
1393 1738098150775 pro JtagIce3 [0x11] <<< 06 00 00 0E 00 
1393 1738098150777 pro JtagIce3 [0x11] >>> 06 00 
1393 1738098150777 pro JtagIce3 [0x11] <<< 14 00 80 20 
1393 1738098150811 pro JtagIce3 [0x11] >>> 14 00 5F 01 B6 01 90 E0 0E 94 EA 0E 51 10 5A 94 F1 E0 8F 1A 91 08 B3 CF 61 91 71 91 07 2E 00 0C 88 0B 99 0B 68 CF 37 2C E8 94 34 F8 2A E0 30 E0 95 37 39 F1 57 2D 59 7F 35 2E 90 37 99 F0 58 F4 98 35 A9 F0 9F 36 D9 F0 F6 01 86 81 97 81 2B 96 E1 E1 0C 94 95 0F 98 37 B9 F7 74 FC 05 C0 20 E1 30 E0 0F C0 68 94 34 F8 68 94 32 F8 F8 CF 74 FE 03 C0 87 2D 86 60 38 2E 20 E1 32 E0 02 C0 28 E0 30 E0 00 
1393 1738098150812 pro JtagIce3 [0x11] <<< 06 00 00 0E 40 
1393 1738098150813 pro JtagIce3 [0x11] >>> 06 00 
1393 1738098150813 pro JtagIce3 [0x11] <<< 14 00 80 20 
1393 1738098150847 pro JtagIce3 [0x11] >>> 14 00 F8 01 37 FE 11 C0 61 91 71 91 81 91 91 91 8F 01 FE 01 31 96 5F 01 AF 01 0E 94 1A 0F 8A 19 A8 2E 73 2C E8 94 77 F8 3F CF 61 91 71 91 80 E0 90 E0 EE CF 78 2E BA 2C 74 FE 45 CF FE 01 EA 0D F1 1D 80 81 80 33 09 F0 43 C0 27 2D 29 7E 72 2E 73 FC 0E C0 70 FE 4F C0 6A 2C B5 14 18 F4 65 0C 6B 18 B5 2C 85 2D 8B 19 5B 14 08 F4 80 E0 B8 0E B5 14 08 F0 42 C0 5B 18 74 FE 41 C0 B6 01 80 E3 90 E0 00 
1393 1738098150848 pro JtagIce3 [0x11] <<< 06 00 00 0E 80 
1393 1738098150849 pro JtagIce3 [0x11] >>> 06 00 
1393 1738098150849 pro JtagIce3 [0x11] <<< 14 00 80 20 
1393 1738098150883 pro JtagIce3 [0x11] >>> 14 00 0E 94 EA 0E 72 FE 09 C0 88 E5 90 E0 71 FC 02 C0 88 E7 90 E0 B6 01 0E 94 EA 0E A6 14 D8 F1 AA 94 B1 2C 4F EF A4 1A B4 0A CE 01 01 96 3C 01 A8 0E B9 1E F5 01 82 91 5F 01 B6 01 90 E0 0E 94 EA 0E 6A 14 7B 04 B1 F7 1D CF B6 2C 78 2E B6 CF 72 FC 02 C0 B3 94 BC CF B3 94 B3 94 B9 CF B6 2C 78 2E F1 CE B6 01 80 E2 90 E0 0E 94 EA 0E 33 94 35 14 C0 F3 B7 CF 3B 2C FB CF 51 2C BD CF 87 2D 86 78 00 
1393 1738098150883 pro JtagIce3 [0x11] <<< 06 00 00 0E C0 
1393 1738098150885 pro JtagIce3 [0x11] >>> 06 00 
1393 1738098150885 pro JtagIce3 [0x11] <<< 14 00 80 20 
1393 1738098150919 pro JtagIce3 [0x11] >>> 14 00 81 15 59 F2 80 E2 71 FC 8B E2 77 FC 8D E2 B6 01 90 E0 C1 CF B6 01 80 E3 90 E0 0E 94 EA 0E 6A 94 BC CF 8F EF 9F EF 52 CF FC 01 05 90 61 50 70 40 01 10 D8 F7 80 95 90 95 8E 0F 9F 1F 08 95 FC 01 61 50 70 40 01 90 01 10 D8 F7 80 95 90 95 8E 0F 9F 1F 08 95 0F 93 1F 93 CF 93 DF 93 18 2F 09 2F EB 01 8B 81 81 FD 09 C0 1F EF 0F EF 81 2F 90 2F DF 91 CF 91 1F 91 0F 91 08 95 82 FF 14 C0 2E 81 00 
1393 1738098150919 pro JtagIce3 [0x11] <<< 06 00 00 0F 00 
1393 1738098150921 pro JtagIce3 [0x11] >>> 06 00 
1393 1738098150921 pro JtagIce3 [0x11] <<< 14 00 80 20 
1393 1738098150955 pro JtagIce3 [0x11] >>> 14 00 3F 81 8C 81 9D 81 28 17 39 07 3C F4 E8 81 F9 81 CF 01 01 96 99 83 88 83 10 83 8E 81 9F 81 01 96 9F 83 8E 83 E3 CF E8 85 F9 85 81 2F 09 95 89 2B A1 F3 DA CF FA 01 AA 27 28 30 51 F1 20 31 81 F1 E8 94 6F 93 6E 7F 6E 5F 7F 4F 8F 4F 9F 4F AF 4F B1 E0 3E D0 B4 E0 3C D0 67 0F 78 1F 89 1F 9A 1F A1 1D 68 0F 79 1F 8A 1F 91 1D A1 1D 6A 0F 71 1D 81 1D 91 1D A1 1D 20 D0 09 F4 68 94 3F 91 2A E0 00 
1393 1738098150956 pro JtagIce3 [0x11] <<< 06 00 00 0F 40 
1393 1738098150957 pro JtagIce3 [0x11] >>> 06 00 
1393 1738098150957 pro JtagIce3 [0x11] <<< 14 00 80 20 
1393 1738098150991 pro JtagIce3 [0x11] >>> 14 00 26 9F 11 24 30 19 30 5D 31 93 DE F6 CF 01 08 95 46 2F 47 70 40 5D 41 93 B3 E0 0F D0 C9 F7 F6 CF 46 2F 4F 70 40 5D 4A 33 18 F0 49 5D 31 FD 40 52 41 93 02 D0 A9 F7 EA CF B4 E0 A6 95 97 95 87 95 77 95 67 95 BA 95 C9 F7 00 97 61 05 71 05 08 95 9B 01 AC 01 0A 2E 06 94 57 95 47 95 37 95 27 95 BA 95 C9 F7 62 0F 73 1F 84 1F 95 1F A0 1D 08 95 2F 92 3F 92 4F 92 5F 92 6F 92 7F 92 8F 92 9F 92 00 
1393 1738098150992 pro JtagIce3 [0x11] <<< 06 00 00 0F 80 
1393 1738098150993 pro JtagIce3 [0x11] >>> 06 00 
1393 1738098150993 pro JtagIce3 [0x11] <<< 14 00 80 20 
1393 1738098151027 pro JtagIce3 [0x11] >>> 14 00 AF 92 BF 92 CF 92 DF 92 EF 92 FF 92 0F 93 1F 93 CF 93 DF 93 CD B7 DE B7 CA 1B DB 0B 0F B6 F8 94 DE BF 0F BE CD BF 09 94 2A 88 39 88 48 88 5F 84 6E 84 7D 84 8C 84 9B 84 AA 84 B9 84 C8 84 DF 80 EE 80 FD 80 0C 81 1B 81 AA 81 B9 81 CE 0F D1 1D 0F B6 F8 94 DE BF 0F BE CD BF ED 01 08 95 F8 94 FF CF 25 75 00 2C 00 20 20 20 20 00 4C 45 4E 47 54 48 00 54 4F 00 46 52 4F 4D 00 44 54 59 50 45 00 
1393 1738098151028 pro JtagIce3 [0x11] <<< 06 00 00 0F C0 
1393 1738098151029 pro JtagIce3 [0x11] >>> 06 00 
1393 1738098151029 pro JtagIce3 [0x11] <<< 14 00 80 20 
1393 1738098151063 pro JtagIce3 [0x11] >>> 14 00 00 46 4C 41 47 53 00 41 53 20 4E 55 4D 42 45 52 00 44 69 64 20 6E 6F 74 20 67 65 74 20 52 58 0D 0A 00 0D 0A 0D 0A 20 2E 2E 2E 2E 2E 2E 2E 2E 2E 2E 2E 2E 2E 2E 2E 2E 2E 2E 2E 20 53 54 41 52 54 49 4E 47 21 20 2E 2E 2E 2E 2E 2E 2E 2E 2E 2E 2E 2E 2E 2E 2E 2E 2E 2E 2E 20 0D 0A 0D 0A 00 4C 4F 4F 50 0D 0A 00 49 6E 63 72 65 6D 65 6E 74 69 6E 67 20 6D 69 6E 75 74 65 20 69 6E 64 65 78 0D 0A 00 
1393 1738098151064 pro JtagIce3 [0x11] <<< 06 00 00 10 00 
1393 1738098151065 pro JtagIce3 [0x11] >>> 06 00 
1393 1738098151065 pro JtagIce3 [0x11] <<< 14 00 80 20 
1393 1738098151099 pro JtagIce3 [0x11] >>> 14 00 00 53 65 6E 64 69 6E 67 20 74 68 69 73 20 6D 65 73 73 61 67 65 0D 0A 00 FF FF FF FF FF FF FF FF FF FF FF FF FF FF FF FF FF FF FF FF FF FF FF FF FF FF FF FF FF FF FF FF FF FF FF FF FF FF FF FF FF FF FF FF FF FF FF FF FF FF FF FF FF FF FF FF FF FF FF FF FF FF FF FF FF FF FF FF FF FF FF FF FF FF FF FF FF FF FF FF FF FF FF FF FF FF FF FF FF FF FF FF FF FF FF FF FF FF FF FF FF FF FF FF 00 
1393 1738098151099 GEN4_TO_CONTROLLER_LOG:GEN4_PROGRAM_INT_LOG_ATmega328PB Post:SendOperation
1393 1738098151099 GEN4_TO_CONTROLLER_LOG:GEN4_PROGRAM_INT_LOG_ATmega328PB Return Value
1393 1738098151099 GEN4_TO_CONTROLLER_LOG:GEN4_PROGRAM_INT_LOG_ATmega328PB None
1393 1738098151099 GEN4_TO_CONTROLLER_LOG:GEN4_PROGRAM_INT_LOG_ATmega328PB Return End

1393 1738098151100 GEN4_TO_CONTROLLER_LOG:GEN4_PROGRAM_INT_LOG_ATmega328PB Pre:endOfOperations
1393 1738098151100 GEN4_TO_CONTROLLER_LOG:GEN4_PROGRAM_INT_LOG_ATmega328PB Payload
1393 1738098151100 GEN4_TO_CONTROLLER_LOG:GEN4_PROGRAM_INT_LOG_ATmega328PB null
1393 1738098151100 GEN4_TO_CONTROLLER_LOG:GEN4_PROGRAM_INT_LOG_ATmega328PB Payload End
1393 1738098151100 pro JtagIce3 [0x11] <<< 11 01 01 
1393 1738098151103 pro JtagIce3 [0x11] >>> 11 00 
1393 1738098151103 pro JtagIce3 [0x01] <<< 11 00 00 
1393 1738098151104 pro JtagIce3 [0x01] >>> 80 00 
1393 1738098151104 GEN4_TO_CONTROLLER_LOG:GEN4_PROGRAM_INT_LOG_ATmega328PB Post:endOfOperations
1393 1738098151104 GEN4_TO_CONTROLLER_LOG:GEN4_PROGRAM_INT_LOG_ATmega328PB Return Value
1393 1738098151104 GEN4_TO_CONTROLLER_LOG:GEN4_PROGRAM_INT_LOG_ATmega328PB None
1393 1738098151104 GEN4_TO_CONTROLLER_LOG:GEN4_PROGRAM_INT_LOG_ATmega328PB Return End

1393 1738098151105 GEN4_TO_CONTROLLER_LOG:GEN4_PROGRAM_INT_LOG_ATmega328PB Pre:SendOperation
1393 1738098151105 GEN4_TO_CONTROLLER_LOG:GEN4_PROGRAM_INT_LOG_ATmega328PB Payload
1393 1738098151105 GEN4_TO_CONTROLLER_LOG:GEN4_PROGRAM_INT_LOG_ATmega328PB OperationInfo: Values:
1393 1738098151105 GEN4_TO_CONTROLLER_LOG:GEN4_PROGRAM_INT_LOG_ATmega328PB OperationInfo: Type = releasefromreset, Mask = 00000000, Erase = false, Production Mode = true
1393 1738098151105 GEN4_TO_CONTROLLER_LOG:GEN4_PROGRAM_INT_LOG_ATmega328PB Payload End
1393 1738098151105 pro JtagIce3 [0x01] <<< 11 00 00 
1393 1738098151106 pro JtagIce3 [0x01] >>> 80 00 
1393 1738098151106 GEN4_TO_CONTROLLER_LOG:GEN4_PROGRAM_INT_LOG_ATmega328PB Post:SendOperation
1393 1738098151106 GEN4_TO_CONTROLLER_LOG:GEN4_PROGRAM_INT_LOG_ATmega328PB Return Value
1393 1738098151106 GEN4_TO_CONTROLLER_LOG:GEN4_PROGRAM_INT_LOG_ATmega328PB None
1393 1738098151106 GEN4_TO_CONTROLLER_LOG:GEN4_PROGRAM_INT_LOG_ATmega328PB Return End
1393 1738098151106 GEN4_CONNECT_DIAGNOSTICS:MPLABCommTool is null

1393 1738098151106 GEN4_TO_CONTROLLER_LOG:GEN4_CONNECT_INT_LOG Pre:GetFirmwareInfo
1393 1738098151106 GEN4_TO_CONTROLLER_LOG:GEN4_CONNECT_INT_LOG Payload
1393 1738098151106 GEN4_TO_CONTROLLER_LOG:GEN4_CONNECT_INT_LOG null
1393 1738098151106 GEN4_TO_CONTROLLER_LOG:GEN4_CONNECT_INT_LOG Payload End
1393 1738098151106 NativeController::GetFirmwareInfo entry
1393 1738098151106 pro JtagIce3 [0x01] <<< 02 00 00 00 01 
1393 1738098151107 pro JtagIce3 [0x01] >>> 84 01 00 00 
1393 1738098151107 NativeController::getFirmwareVersion entry
1393 1738098151107 pro JtagIce3 [0x01] <<< 02 00 00 01 01 
1393 1738098151108 pro JtagIce3 [0x01] >>> 84 01 01 00 
1393 1738098151108 pro JtagIce3 [0x01] <<< 02 00 00 02 01 
1393 1738098151109 pro JtagIce3 [0x01] >>> 84 01 2D 00 
1393 1738098151109 pro JtagIce3 [0x01] <<< 02 00 00 03 02 
1393 1738098151110 pro JtagIce3 [0x01] >>> 84 01 07 00 00 
1393 1738098151110 NativeController::getFirmwareVersion exit
1393 1738098151110 pro JtagIce3 [0x01] <<< 02 00 00 09 01 
1393 1738098151111 pro JtagIce3 [0x01] >>> 84 01 00 11 
1393 1738098151111 NativeController::tryGetFPGAVersion entry
1393 1738098151111 pro JtagIce3 [0x01] <<< 02 00 00 10 01 
1393 1738098151112 pro JtagIce3 [0x01] >>> 84 01 00 11 
1393 1738098151112 pro JtagIce3 [0x01] <<< 02 00 00 11 01 
1393 1738098151113 pro JtagIce3 [0x01] >>> 84 01 00 11 
1393 1738098151113 pro JtagIce3 [0x01] <<< 02 00 00 12 01 
1393 1738098151114 pro JtagIce3 [0x01] >>> 84 01 00 11 
1393 1738098151114 NativeController::tryGetFPGAVersion exit
1393 1738098151114 NativeController::tryGetFPGAVersion exit with exception No value present
1393 1738098151114 pro JtagIce3 [0x01] <<< 02 00 00 06 01 
1393 1738098151115 pro JtagIce3 [0x01] >>> 84 01 05 00 
1393 1738098151115 pro JtagIce3 [0x01] <<< 02 00 00 07 01 
1393 1738098151116 pro JtagIce3 [0x01] >>> 84 01 05 00 
1393 1738098151116 pro JtagIce3 [0x01] <<< 02 00 00 0A 01 
1393 1738098151117 pro JtagIce3 [0x01] >>> 84 01 00 11 
1393 1738098151117 NativeController::GetFirmwareInfo exit
1393 1738098151117 GEN4_TO_CONTROLLER_LOG:GEN4_CONNECT_INT_LOG Post:GetFirmwareInfo
1393 1738098151117 GEN4_TO_CONTROLLER_LOG:GEN4_CONNECT_INT_LOG Return Value
1393 1738098151117 GEN4_TO_CONTROLLER_LOG:GEN4_CONNECT_INT_LOG FirmwareInfo: Values:
1393 1738098151117 GEN4_TO_CONTROLLER_LOG:GEN4_CONNECT_INT_LOG FirmwareInfo: boot = false, bootVer = 5.5.0 (0x05.0x05.0x00), apVer = 1.45.7 (0x01.0x2d.0x07), fpgaVer = null, scriptVer = null, macAddress = , devID = 0, devID1 = 0, devSN0 = 0, devSN1 = 0, serialNumber = null, appCommitID = null, scriptCommitID = null, PCB_ID = 0
1393 1738098151117 GEN4_TO_CONTROLLER_LOG:GEN4_CONNECT_INT_LOG Return End

1393 1738098151117 GEN4_TO_CONTROLLER_LOG:GEN4_CONNECT_INT_LOG Pre:SetPowerInfo
1393 1738098151117 GEN4_TO_CONTROLLER_LOG:GEN4_CONNECT_INT_LOG Payload
1393 1738098151117 GEN4_TO_CONTROLLER_LOG:GEN4_CONNECT_INT_LOG PowerInfo: Values:
1393 1738098151117 GEN4_TO_CONTROLLER_LOG:GEN4_CONNECT_INT_LOG PowerInfo: shotDownSystem = true, isToolPower = false, voltage = 0.000000, useVppFirst = false, useLowVoltageProgramming = true, useMaintainActivePower = false
1393 1738098151117 GEN4_TO_CONTROLLER_LOG:GEN4_CONNECT_INT_LOG Payload End
1393 1738098151117 NativeController::GetVoltageInfo entry
1393 1738098151117 pro JtagIce3 [0x01] <<< 02 00 01 00 02 
1393 1738098151118 pro JtagIce3 [0x01] >>> 84 01 85 0E 00 
1393 1738098151118 pro JtagIce3 [0x01] <<< 02 00 01 20 02 
1393 1738098151119 pro JtagIce3 [0x01] >>> 84 01 00 00 11 
1393 1738098151119 NativeController::GetVoltageInfo TSUP exit with exception + The requested command is not supported. (17)
1393 1738098151119 pro JtagIce3 [0x01] <<< 02 00 01 02 02 
1393 1738098151120 pro JtagIce3 [0x01] >>> 84 01 00 00 11 
1393 1738098151120 NativeController::GetVoltageInfo VUSB exit with exception + The requested command is not supported. (17)
1393 1738098151120 NativeController::GetVoltageInfo exit
1393 1738098151120 GEN4_TO_CONTROLLER_LOG:GEN4_CONNECT_INT_LOG Post:SetPowerInfo
1393 1738098151120 GEN4_TO_CONTROLLER_LOG:GEN4_CONNECT_INT_LOG Return Value
1393 1738098151120 GEN4_TO_CONTROLLER_LOG:GEN4_CONNECT_INT_LOG none
1393 1738098151120 GEN4_TO_CONTROLLER_LOG:GEN4_CONNECT_INT_LOG Return End

1393 1738098151120 GEN4_TO_CONTROLLER_LOG:GEN4_CONNECT_INT_LOG Pre:Disconnect
1393 1738098151120 GEN4_TO_CONTROLLER_LOG:GEN4_CONNECT_INT_LOG Payload
1393 1738098151120 GEN4_TO_CONTROLLER_LOG:GEN4_CONNECT_INT_LOG Payload End
1393 1738098151120 NativeController::Disconnect entry
1393 1738098151120 pro JtagIce3 [0x01] <<< 11 00 00 
1393 1738098151121 pro JtagIce3 [0x01] >>> 80 00 
1393 1738098151121 NativeController::Disconnect exit
1393 1738098151121 GEN4_TO_CONTROLLER_LOG:GEN4_CONNECT_INT_LOG Post:Disconnect
1393 1738098151121 GEN4_TO_CONTROLLER_LOG:GEN4_CONNECT_INT_LOG Return Value
1393 1738098151121 GEN4_TO_CONTROLLER_LOG:GEN4_CONNECT_INT_LOG none
1393 1738098151121 GEN4_TO_CONTROLLER_LOG:GEN4_CONNECT_INT_LOG Return End
1393 1738098151121 GEN4_CONNECT_DIAGNOSTICS:Removing plug and play observer com.microchip.mplab.mdbcore.RI4Tool.RI4ToolBase$RI4PlugNPlayObserver@23817016
1393 1738098151121 GEN4_CONNECT_DIAGNOSTICS:Begin PlugNPlayObservers list dump:
1393 1738098151121 GEN4_CONNECT_DIAGNOSTICS:End PlugNPlayObservers list dump:
1393 1738098151222 GEN4_CONNECT_DIAGNOSTICS:Calling RIDbgToolCom.Disconnect
1393 1738098151222 GEN4_CONNECT_DIAGNOSTICS:Calling MPLABCommTool.Detach to remove tool from plug and play list
1393 1738098151222 GEN4_CONNECT_DIAGNOSTICS:Calling RIDbgToolCom.DisconnectFromMPlabComm
1393 1738098151222 GEN4_CONNECT_DIAGNOSTICS:Calling MPLABCommTool.Disconnect
1442 1738098353480 GEN4_CONNECT_DIAGNOSTICS:MPLABCommTool is NOT null
1442 1738098353480 GEN4_CONNECT_DIAGNOSTICS:AttachedToolPID = 2141, AttachedToolVID = 3eb
1442 1738098353480 GEN4_CONNECT_DIAGNOSTICS:transport type = USB
1442 1738098353480 GEN4_CONNECT_DIAGNOSTICS:AttachedToolPID = 2141, AttachedToolVID = 3eb
1442 1738098353481 com.microchip.mplab.mdbcore.RealICETool.RIDbgToolCom
1442 1738098353481 GEN4_CONNECT_DIAGNOSTICS:Before MPLABCommTool.Connect()
1442 1738098353481 GEN4_CONNECT_DIAGNOSTICS:After MPLABCommTool.Connect()
1442 1738098353481 GEN4_CONNECT_DIAGNOSTICS:MPLABCommTool.Connect() returned MPLABCOMM_NO_ERROR
1442 1738098353481 GEN4_CONNECT_DIAGNOSTICS:Attaching to MPLABCommTool plugnplay
1442 1738098353481 GEN4_CONNECT_DIAGNOSTICS:Adding new plug and play observer com.microchip.mplab.mdbcore.RI4Tool.RI4ToolBase$RI4PlugNPlayObserver@7448ba4f
1442 1738098353481 GEN4_CONNECT_DIAGNOSTICS:Begin PlugNPlayObservers list dump:
1442 1738098353481 GEN4_CONNECT_DIAGNOSTICS:com.microchip.mplab.mdbcore.RI4Tool.RI4ToolBase$RI4PlugNPlayObserver@7448ba4f
1442 1738098353481 GEN4_CONNECT_DIAGNOSTICS:End PlugNPlayObservers list dump:
1442 1738098353481 GEN4_CONNECT_DIAGNOSTICS:Registering for alternate PNP notifications. CommPnPCriteria.cPIDList = [2177, 2179, 217a, 2142, 2142], CommPnPCriteria.cSerialNumber = j42700011280
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

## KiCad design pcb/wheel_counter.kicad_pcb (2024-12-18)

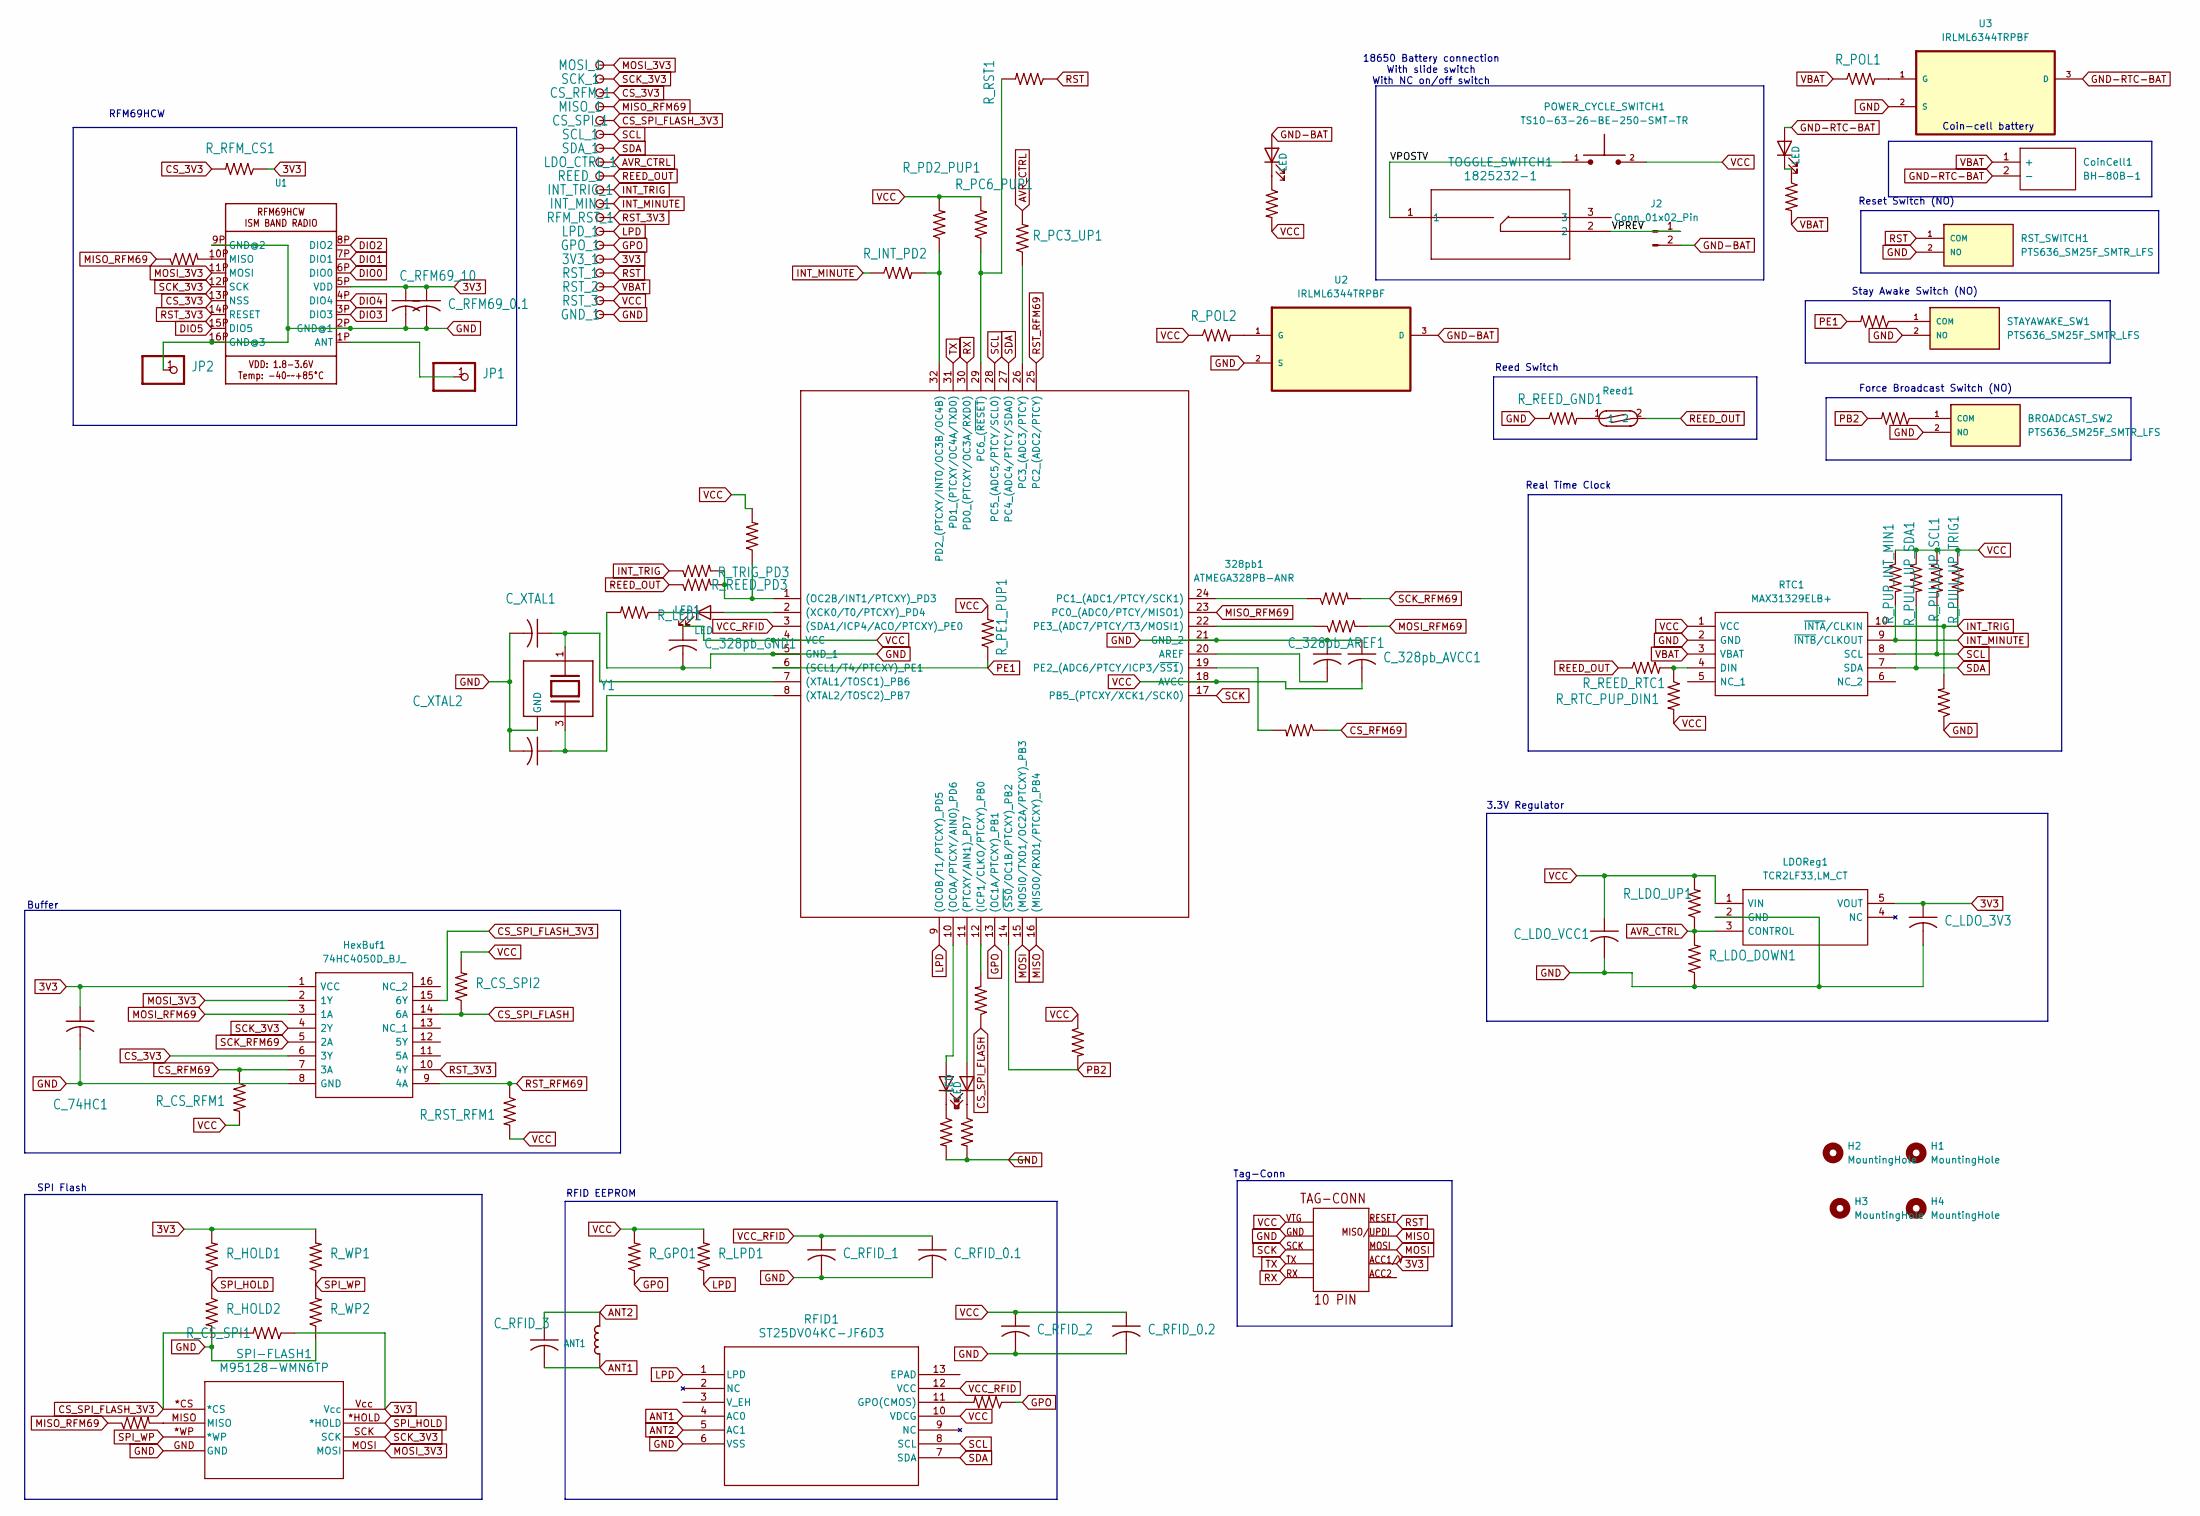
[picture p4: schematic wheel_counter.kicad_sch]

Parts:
3V3_1: MOX-OXLEY-TEST-POINT
328pb1: ATMEGA328PB-ANR; QFP80P900X900X120-32N; Manufacturer_Part_Number ATMEGA328PB-ANR; Mouser Part Number 556-ATMEGA328PB-ANR
ANT1: NFCANT_25X15
BROADCAST_SW2: PTS636_SM25F_SMTR_LFS; PTS636SM25FSMTRLFS; Mouser_Part_Number 611-PTS636SM25FSMTRL
CS_RFM_1: MOX-OXLEY-TEST-POINT
CS_SPI_1: MOX-OXLEY-TEST-POINT
C_74HC1, C_328pb_AREF1, C_328pb_AVCC1, C_328pb_GND1: C0805
C_LDO_3V3: C0805
C_LDO_VCC1: C0805
C_RFID_0.1, C_RFID_0.2, C_RFID_1, C_RFID_2, C_RFID_3: C0805
C_RFM69_0.1, C_RFM69_10: C0805
C_XTAL1, C_XTAL2: C0805
CoinCell1: BH-80B-1; BH80B1; Manufacturer_Part_Number BH-80B-1
GND_1: MOX-OXLEY-TEST-POINT
GPO_1: MOX-OXLEY-TEST-POINT
H1, H2, H3, H4: MountingHole; MountingHole_3.2mm_M3
HexBuf1: 74HC4050D_BJ_; SOIC127P600X175-16N; Manufacturer_Part_Number 74HC4050D(BJ); Mouser Part Number 757-74HC4050DBJ
INT_MIN_1: MOX-OXLEY-TEST-POINT
INT_TRIG_1: MOX-OXLEY-TEST-POINT
J2: Conn_01x02_Pin; PinHeader_1x02_P2.54mm_Vertical
JP1, JP2: 1X01_ROUND
LDOReg1: TCR2LF33,LM_CT; TCR2LF33LMCT; Manufacturer_Part_Number TCR2LF33,LM(CT; Mouser Part Number 757-TCR2LF33LMCT
LDO_CTRL_1: MOX-OXLEY-TEST-POINT
LED1, LED2, LED3, LED4, LED5: LED; LED_0805_2012Metric_Pad1.15x1.40mm_HandSolder
LPD_1: MOX-OXLEY-TEST-POINT
MISO_1: MOX-OXLEY-TEST-POINT
MOSI_1: MOX-OXLEY-TEST-POINT
POWER_CYCLE_SWITCH1: TS10-63-26-BE-250-SMT-TR; SW_TS10-63-26-BE-250-SMT-TR; PARTREV 1.0
REED_1: MOX-OXLEY-TEST-POINT
RFID1: ST25DV04KC-JF6D3; UFDFPN12_ST25DV_STM
RFM_RST_1: MOX-OXLEY-TEST-POINT
RST_1, RST_2, RST_3: MOX-OXLEY-TEST-POINT
RST_SWITCH1: PTS636_SM25F_SMTR_LFS; PTS636SM25FSMTRLFS; Mouser_Part_Number 611-PTS636SM25FSMTRL
RTC1: MAX31329ELB+; MAX31329ELB; Manufacturer_Part_Number MAX31329ELB+; Mouser Part Number 700-MAX31329ELB+
R_CS_RFM1, R_CS_RFM2: R0805
R_CS_SPI1, R_CS_SPI2, R_CS_SPI3, R_CS_SPI4: R0805
R_GPO1, R_GPO2: R0805
R_HOLD1, R_HOLD2: R0805
R_INT_PD2: R0805
R_LDO_DOWN1: R0805
R_LDO_UP1: R0805
R_LED1, R_LED2, R_LED3, R_LED4, R_LED5: R0805
R_LPD1: R0805
R_MISO_RFM1: R0805
R_MISO_SPI1: R0805
R_MOSI1: R0805
R_PC3_UP1, R_PC6_PUP1: R0805
R_PD2_PUP1, R_PD3_UP1: R0805
R_PE1, R_PE1_PUP1, R_PE2: R0805
R_POL1, R_POL2: R0805
R_PULL_DOWN_TRIG1: R0805
R_PULL_UP_SCL1: R0805
R_PULL_UP_SDA1: R0805
R_PULL_UP_TRIG1: R0805
R_PUP_INT_MIN1: R0805
R_REED_GND1: R0805
R_REED_PD3: R0805
R_REED_RTC1: R0805
R_RFM_CS1: R0805
R_RST1: R0805
R_RST_RFM1: R0805
R_RTC_PUP_DIN1: R0805
R_SCK1: R0805
R_TRIG_PD3: R0805
R_WP1, R_WP2: R0805
Reed1: MDSM-4_15.3mm_Surface_Mount_Reed_Switch
SCK_1: MOX-OXLEY-TEST-POINT
SCL_1: MOX-OXLEY-TEST-POINT
SDA_1: MOX-OXLEY-TEST-POINT
SPI-FLASH1: M95128-WMN6TP; SO-8_STM
STAYAWAKE_SW1: PTS636_SM25F_SMTR_LFS; PTS636SM25FSMTRLFS; Mouser_Part_Number 611-PTS636SM25FSMTRL
TAGCONN1: TAG-CONNECT_TC2050-IDC-NL-CUSTOM
TOGGLE_SWITCH1: 1825232-1; 1825232-1_TEC
U1: RFMHCW_SMT
U2, U3: IRLML6344TRPBF; SOT95P240X112-3N; MPN IRLML6344TRPBF
Y1: XTAL_TSX-3225_16.0000MF18X-AC0

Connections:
3V3: 3V3_1.1, C_74HC1.1, C_LDO_3V3.1, C_RFM69_0.1.1, C_RFM69_10.1, HexBuf1.1 (VCC), LDOReg1.5 (VOUT), R_CS_SPI1.1, R_HOLD1.2, R_RFM_CS1.1, R_WP1.2, SPI-FLASH1.Vcc, TAGCONN1.ACC1/V, U1.5P (VDD)
/VPOSTV: POWER_CYCLE_SWITCH1.1, TOGGLE_SWITCH1.1
/VPREV: J2.1, TOGGLE_SWITCH1.2
ANT1: ANT1.IN2 (1), ANT1.P$1 (1), C_RFID_3.2, RFID1.4 (AC0)
ANT2: ANT1.IN1 (2), ANT1.P$2 (2), C_RFID_3.1, RFID1.5 (AC1)
AVR_CTRL: LDOReg1.3 (CONTROL), LDO_CTRL_1.1, R_LDO_DOWN1.2, R_LDO_UP1.1, R_PC3_UP1.2
CS_3V3: CS_RFM_1.1, HexBuf1.6 (3Y), R_RFM_CS1.2, U1.13P (NSS)
CS_RFM69: HexBuf1.7 (3A), R_CS_RFM1.1, R_CS_RFM2.1
CS_SPI_FLASH: HexBuf1.14 (6A), R_CS_SPI2.1, R_CS_SPI3.1
CS_SPI_FLASH_3V3: CS_SPI_1.1, HexBuf1.15 (6Y), R_CS_SPI1.2, SPI-FLASH1.*CS
DIO0: U1.6P (DIO0)
DIO1: U1.7P (DIO1)
DIO2: U1.8P (DIO2)
DIO3: U1.3P (DIO3)
DIO4: U1.4P (DIO4)
DIO5: U1.15P (DIO5)
GND: 328pb1.5 (GND_1), 328pb1.21 (GND_2), BROADCAST_SW2.2 (NO), C_74HC1.2, C_328pb_AREF1.1, C_328pb_AVCC1.1, C_328pb_GND1.2, C_LDO_3V3.2, C_LDO_VCC1.2, C_RFID_0.1.2, C_RFID_0.2.2, C_RFID_1.2, C_RFID_2.2, C_RFM69_0.1.2, C_RFM69_10.2, C_XTAL1.2, C_XTAL2.2, GND_1.1, HexBuf1.8 (GND), JP2.1, LDOReg1.2 (GND), RFID1.6 (VSS), RST_SWITCH1.2 (NO), RTC1.2 (GND), R_HOLD2.2, R_LDO_DOWN1.1, R_LED1.2, R_LED2.2, R_LED3.2, R_PULL_DOWN_TRIG1.1, R_REED_GND1.1, R_WP2.1, SPI-FLASH1.GND, STAYAWAKE_SW1.2 (NO), TAGCONN1.GND, U1.2P (GND@1), U1.9P (GND@2), U1.16P (GND@3), U2.2 (S), U3.2 (S), Y1.2 (GND), Y1.4 (GND)
GND-BAT: J2.2, LED4.2 (A), U2.3 (D)
GND-RTC-BAT: CoinCell1.2 (-), LED5.2 (A), U3.3 (D)
GPO: 328pb1.13 ((OC1A/PTCXY)_PB1), GPO_1.1, R_GPO1.1, R_GPO2.1
INT_MINUTE: INT_MIN_1.1, RTC1.9 (~INTB/CLKOUT), R_INT_PD2.1, R_PUP_INT_MIN1.2
INT_TRIG: INT_TRIG_1.1, RTC1.10 (~INTA/CLKIN), R_PULL_DOWN_TRIG1.2, R_PULL_UP_TRIG1.2, R_TRIG_PD3.1
LPD: 328pb1.9 ((OC0B/T1/PTCXY)_PD5), LPD_1.1, RFID1.1 (LPD), R_LPD1.1
MISO: 328pb1.16 ((MISO0/RXD1/PTCXY)_PB4), TAGCONN1.MISO/UPDI
MISO_RFM69: 328pb1.23 (PC0_(ADC0/PTCY/MISO1)), MISO_1.1, R_MISO_RFM1.1, R_MISO_SPI1.1
MOSI: 328pb1.15 ((MOSI0/TXD1/OC2A/PTCXY)_PB3), TAGCONN1.MOSI
MOSI_3V3: HexBuf1.2 (1Y), MOSI_1.1, SPI-FLASH1.MOSI, U1.11P (MOSI)
MOSI_RFM69: HexBuf1.3 (1A), R_MOSI1.2
unnamed: 328pb1.12 ((ICP1/CLKO/PTCXY)_PB0), R_CS_SPI3.2
unnamed: 328pb1.10 ((OC0A/PTCXY/AIN0)_PD6), LED2.2 (A)
unnamed: 328pb1.1 ((OC2B/INT1/PTCXY)_PD3), R_PD3_UP1.1, R_REED_PD3.2, R_TRIG_PD3.2
unnamed: 328pb1.11 ((PTCXY/AIN1)_PD7), LED3.2 (A)
unnamed: 328pb1.2 ((XCK0/T0/PTCXY)_PD4), LED1.2 (A)
unnamed: 328pb1.7 ((XTAL1/TOSC1)_PB6), C_XTAL1.1, Y1.1
unnamed: 328pb1.8 ((XTAL2/TOSC2)_PB7), C_XTAL2.1, Y1.3 (2)
unnamed: 328pb1.20 (AREF), C_328pb_AREF1.2
unnamed: 328pb1.24 (PC1_(ADC1/PTCY/SCK1)), R_SCK1.1
unnamed: 328pb1.26 (PC3_(ADC3/PTCY)), R_PC3_UP1.1
unnamed: 328pb1.29 (PC6_(~RESET)), R_PC6_PUP1.1, R_RST1.2
unnamed: 328pb1.32 (PD2_(PTCXY/INT0/OC3B/OC4B)), R_INT_PD2.2, R_PD2_PUP1.1
unnamed: 328pb1.19 (PE2_(ADC6/PTCY/ICP3/~SS1)), R_CS_RFM2.2
unnamed: 328pb1.22 (PE3_(ADC7/PTCY/T3/MOSI1)), R_MOSI1.1
unnamed: BROADCAST_SW2.1 (COM), R_PE2.1
unnamed: LED1.1 (K), R_LED1.1
unnamed: LED2.1 (K), R_LED2.1
unnamed: LED3.1 (K), R_LED3.1
unnamed: LED4.1 (K), R_LED4.1
unnamed: LED5.1 (K), R_LED5.1
unnamed: RFID1.11 (GPO(CMOS)), R_GPO2.2
unnamed: RTC1.4 (DIN), R_REED_RTC1.2, R_RTC_PUP_DIN1.1
unnamed: R_MISO_SPI1.2, SPI-FLASH1.MISO
unnamed: R_REED_GND1.2, Reed1.1
unnamed: R_PE1.1, STAYAWAKE_SW1.1 (COM)
unnamed: JP1.1, U1.1P (ANT)
unnamed: R_MISO_RFM1.2, U1.10P (MISO)
unnamed: R_POL2.2, U2.1 (G)
unnamed: R_POL1.2, U3.1 (G)
PB2: 328pb1.14 ((~SS0/OC1B/PTCXY)_PB2), R_CS_SPI4.2, R_PE2.2
PE1: 328pb1.6 ((SCL1/T4/PTCXY)_PE1), R_PE1.2, R_PE1_PUP1.1
REED_OUT: REED_1.1, R_REED_PD3.1, R_REED_RTC1.1, Reed1.2
RST: RST_1.1, RST_SWITCH1.1 (COM), R_RST1.1, TAGCONN1.RST (RESET)
RST_3V3: HexBuf1.10 (4Y), RFM_RST_1.1, U1.14P (RESET)
RST_RFM69: 328pb1.25 (PC2_(ADC2/PTCY)), HexBuf1.9 (4A), R_RST_RFM1.1
RX: 328pb1.30 (PD0_(PTCXY/OC3A/RXD0)), TAGCONN1.RX
SCK: 328pb1.17 (PB5_(PTCXY/XCK1/SCK0)), TAGCONN1.SCK
SCK_3V3: HexBuf1.4 (2Y), SCK_1.1, SPI-FLASH1.SCK, U1.12P (SCK)
SCK_RFM69: HexBuf1.5 (2A), R_SCK1.2
SCL: 328pb1.28 (PC5_(ADC5/PTCY/SCL0)), RFID1.8 (SCL), RTC1.8 (SCL), R_PULL_UP_SCL1.2, SCL_1.1
SDA: 328pb1.27 (PC4_(ADC4/PTCY/SDA0)), RFID1.7 (SDA), RTC1.7 (SDA), R_PULL_UP_SDA1.2, SDA_1.1
SPI_HOLD: R_HOLD1.1, R_HOLD2.1, SPI-FLASH1.*HOLD
SPI_WP: R_WP1.1, R_WP2.2, SPI-FLASH1.*WP
TX: 328pb1.31 (PD1_(PTCXY/OC4A/TXD0)), TAGCONN1.TX
VBAT: CoinCell1.1 (+), RST_2.1, RTC1.3 (VBAT), R_LED5.2, R_POL1.1
VCC: 328pb1.4 (VCC), 328pb1.18 (AVCC), C_328pb_AVCC1.2, C_328pb_GND1.1, C_LDO_VCC1.1, C_RFID_0.2.1, C_RFID_2.1, LDOReg1.1 (VIN), POWER_CYCLE_SWITCH1.2, RFID1.10 (VDCG), RST_3.1, RTC1.1 (VCC), R_CS_RFM1.2, R_CS_SPI2.2, R_CS_SPI4.1, R_GPO1.2, R_LDO_UP1.2, R_LED4.2, R_LPD1.2, R_PC6_PUP1.2, R_PD2_PUP1.2, R_PD3_UP1.2, R_PE1_PUP1.2, R_POL2.1, R_PULL_UP_SCL1.1, R_PULL_UP_SDA1.1, R_PULL_UP_TRIG1.1, R_PUP_INT_MIN1.1, R_RST_RFM1.2, R_RTC_PUP_DIN1.2, TAGCONN1.VTG
VCC_RFID: 328pb1.3 ((SDA1/ICP4/ACO/PTCXY)_PE0), C_RFID_0.1.1, C_RFID_1.1, RFID1.12 (VCC)

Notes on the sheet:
RFID EEPROM
RFM69HCW
Tag-Conn
Force Broadcast Switch (NO)
Buffer
Reset Switch (NO)
Real Time Clock
Coin-cell battery
SPI Flash
18650 Battery connection With slide switch With NC on/off switch
Reed Switch
3.3V Regulator
Stay Awake Switch (NO)

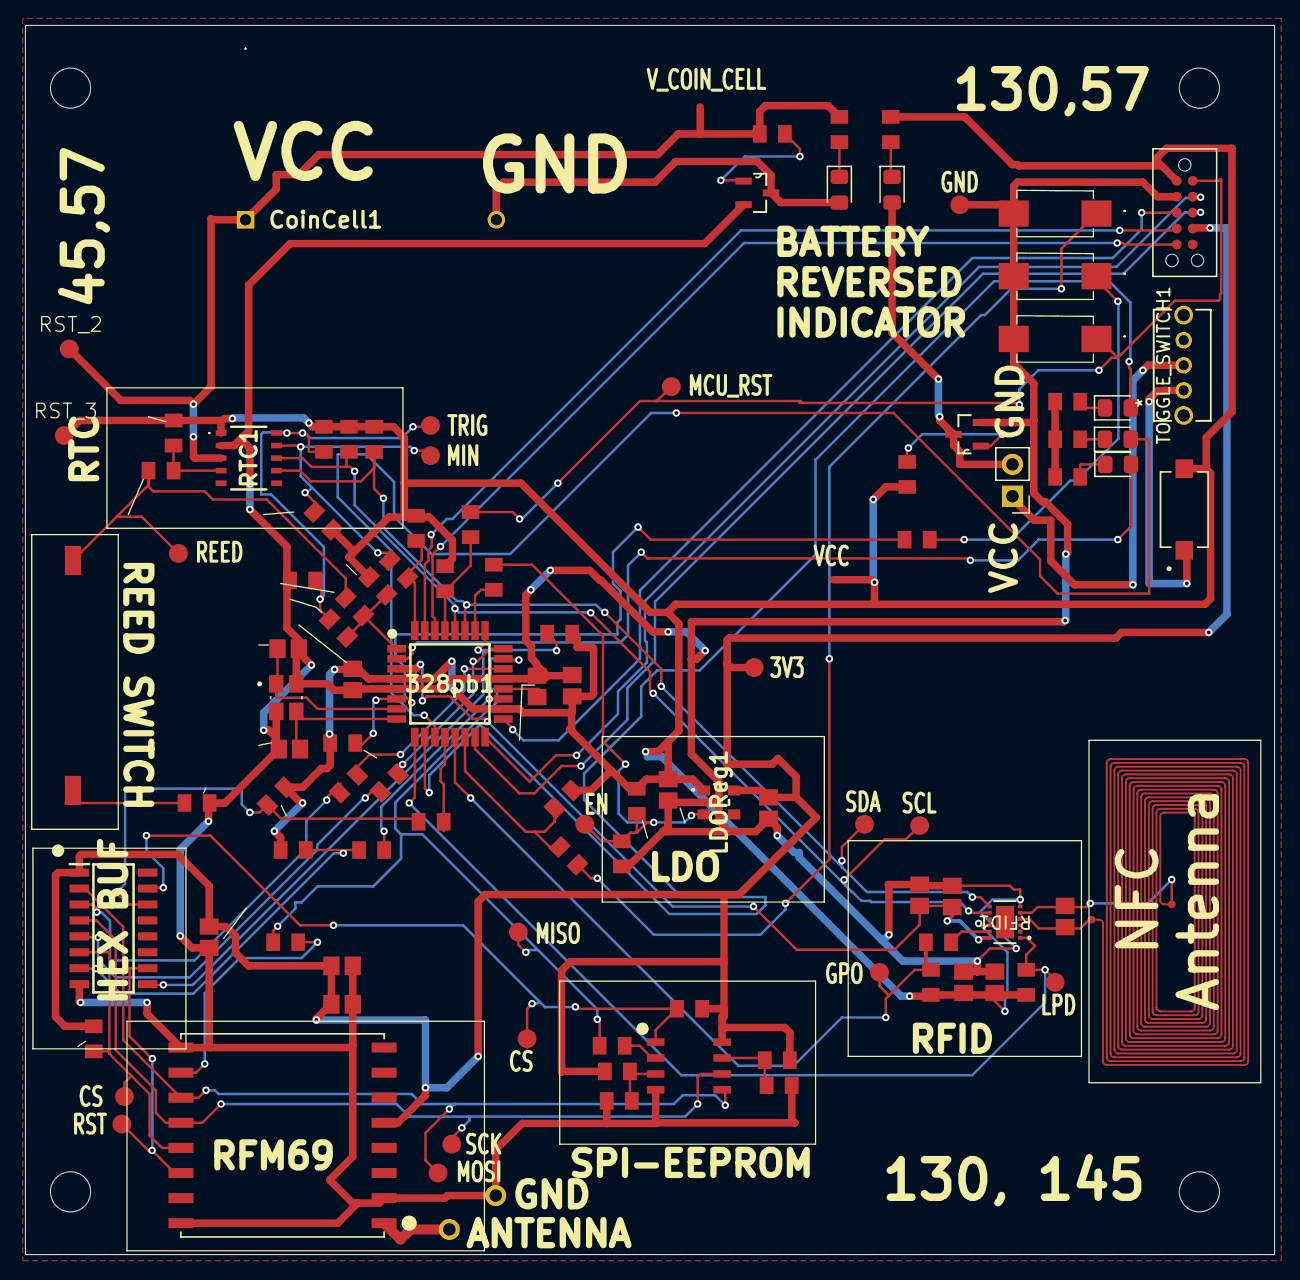
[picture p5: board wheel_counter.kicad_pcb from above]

Board: 2 copper layers, 99.6 x 98.0 mm, 112 parts (0 on the bottom side), 69 nets.

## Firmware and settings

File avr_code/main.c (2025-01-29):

#include "adc.h"
#include "defines.h"
#include "interrupts.h"
#include "m95128.h"
#include "max31329.h"
#include "ndef.h"
#include "power_mgmt.h"
#include "rfm69.h"
#include "st25dv.h"
#include "states.h"

#if DO_UART
#include "uart.h"
#endif

#include <avr/interrupt.h>
#include <avr/io.h>
#include <avr/power.h>
#include <avr/sleep.h>
#include <stdbool.h>
#include <stdio.h>
#include <util/delay.h>
#define WAIT_FOREVER                                                                               \
    while (1) {                                                                                    \
        _delay_ms(100);                                                                            \
    };

// #define NUM_CYCLES_SEND_BACKLOG 2

uint16_t self_value;
tx_rx_data_struct CRAP;
uint16_t main_counter;
volatile uint8_t is_debouncing = 0;
volatile bool increment_minute_index = false;
volatile bool increment_wheel_count = false;
volatile uint8_t index_wheel_count = 0;
volatile uint16_t total_wheel_counts[15];

RTC_RFM69_STATUS rtc_rfm69_status;

ISR(INT0_vect) { increment_minute_index = true; }

ISR(INT1_vect)
{
    increment_wheel_count = true;
    //    increment_minute_index = true;
    if (!is_debouncing) {
        total_wheel_counts[index_wheel_count]++;
        is_debouncing = 1;
        wdt_isr_enable();
    }
}

ISR(WDT_vect)
{
    is_debouncing = 0;
    wdt_isr_disable();
}

void start_sleeping()
{
    spi_eeprom_select(false);
    spi_rfm69_select(false);
    rfid_set_low_power_down(true);
    rfid_set_i2c_power(false);
    ldo_set_state(false);

    _delay_ms(10);
    sleep_bod_disable();
    set_sleep_mode(SLEEP_MODE_PWR_DOWN);
    sleep_enable();
    sei();
    sleep_cpu();
}

uint16_t get_battery_reading()
{
    adc_Enable();
    adc_GetConversion(14);
    adc_GetConversion(14);
    self_value = adc_GetConversion(14);
    adc_Disable();
    return self_value;
}

// i2c Addresses

// RTC
// 0x68 (0xD0 W) (0xD1 R)

// NFC
// 0x2D (0x5A W) (0x5B R)
// 0x53 (0xA6 W) (0xA7 R)
// 0x57 (0xAE W) (0xAF R)

int main(void)
{
    ldo_set_state(true);
    _delay_ms(10);
    init_pins();
#if DO_UART
    uart_init();
#endif

    i2c_init();

    init_spi();
    adc_Initialize();
    set_up_reed_interrupt();
    set_up_minute_interrupt();
    rtc_set_per_minute_alarm();
    rtc_set_alarm_config();
    rtc_enable_interrupts();
    rtc_read_interrupt_register();
    rtc_read_status_register();
    rfm69_init();

    for (uint8_t c = 0; c < 15; c++) {
        total_wheel_counts[c] = 0;
    }

    // Get the nugget's name and wheel diameter
    IDENTIFIER = get_nugget_data();

    // Request time from radio
    rtc_rfm69_status = set_time_from_rfm69(IDENTIFIER);
    if (rtc_rfm69_status == RTC_RFM69_SET_TIME_SUCCESS) {
        for (int i = 0; i < 5; i++) {
            led_1_set_state(true);
            _delay_ms(90);
            led_1_set_state(false);
            _delay_ms(10);
        }
    } else {

        for (int i = 0; i < 5; i++) {
            led_1_set_state(true);
            _delay_ms(10);
            led_1_set_state(false);
            _delay_ms(90);
        }
    }
    get_battery_reading();

    while (1) {

        spi_rfm69_select(false);
        spi_eeprom_select(false);

        start_sleeping();
        cli();

        if (increment_minute_index) {
            increment_minute_index = false;
            index_wheel_count += 1;

            rtc_read_interrupt_register();
            rtc_read_status_register();

            rtc_read_interrupt_register();
            rtc_read_status_register();

            if (index_wheel_count >= 15) {
                index_wheel_count = 0;
                ldo_set_state(true);
                rfm69_init();
                rfid_set_i2c_power(true);
                rfid_set_low_power_down(false);
                _delay_ms(1);
                IDENTIFIER = get_nugget_data();

                // Request time from radio if we don't have a good time stamp yet
                if (rtc_rfm69_status == RTC_RFM69_SET_TIME_FAILED) {
                    rtc_rfm69_status = set_time_from_rfm69(IDENTIFIER);
                }

                // Generate wheel counts message
                reset_txrx_struct(&TX_DATA);
                get_battery_reading();
                TX_DATA = generate_wheel_counts_message(
                    IDENTIFIER, rtc_read_time(), get_battery_reading(), total_wheel_counts);

                rfm69_write_msg(TX_DATA);
#if DO_UART
                uart_sendString("TX DATA Sent\n");
                uart_print_tx_rx_data(TX_DATA);
#endif

                DATA_SEND_STATUS result = send_message(TX_DATA);
                if (result == DATA_NOT_SENT) {
                    write_struct_to_last_page(TX_DATA);
                }

                for (uint8_t c = 0; c < 15; c++) {
                    total_wheel_counts[c] = 0;
                }
                if ((result == DATA_SEND_SUCCESS) && (get_last_page() > 0)) {
                    reset_txrx_struct(&TX_DATA);
                    TX_DATA = read_struct_last_page();
                    TX_DATA.flags = MSG_RESENT_COUNTS;
                    send_message(TX_DATA);
#if DO_UART
                    uart_sendString("TX DATA From SPI Memory\n");
                    uart_print_tx_rx_data(TX_DATA);
#endif
                    delete_last_page();
                }
            }
        }
    }
}

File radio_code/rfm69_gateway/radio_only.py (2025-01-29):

# SPDX-FileCopyrightText: 2018 Brent Rubell for Adafruit Industries
#
# SPDX-License-Identifier: MIT

"""
Example for using the RFM69HCW Radio with Raspberry Pi.

Learn Guide: https://learn.adafruit.com/lora-and-lorawan-for-raspberry-pi
Author: Brent Rubell for Adafruit Industries
"""
from datetime import datetime
# Import Python System Libraries
import time
from datetime import datetime
# Import Blinka Libraries
import busio
from digitalio import DigitalInOut, Direction, Pull
import board
# Import the SSD1306 module.
# import adafruit_ssd1306
# Import the RFM69 radio module.
import adafruit_rfm69
# import numpy as np
import ctypes
import struct
import pickle
import os
# # Button A
# btnA = DigitalInOut(board.D5)
# btnA.direction = Direction.INPUT
# btnA.pull = Pull.UP

# # Button B
# btnB = DigitalInOut(board.D6)
# btnB.direction = Direction.INPUT
# btnB.pull = Pull.UP

# # Button C
# btnC = DigitalInOut(board.D12)
# btnC.direction = Direction.INPUT
# btnC.pull = Pull.UP

# # Create the I2C interface.
# i2c = busio.I2C(board.SCL, board.SDA)

# # 128x32 OLED Display
# reset_pin = DigitalInOut(board.D4)
# display = adafruit_ssd1306.SSD1306_I2C(128, 32, i2c, reset=reset_pin)
# # Clear the display.
# display.fill(0)
# display.show()
# width = display.width
# height = display.height

# Configure Packet Radio
CS = DigitalInOut(board.CE1)
RESET = DigitalInOut(board.D25)
spi = busio.SPI(board.SCK, MOSI=board.MOSI, MISO=board.MISO)
rfm69 = adafruit_rfm69.RFM69(spi, CS, RESET, 434.0, high_power=True)
prev_packet = None
# Optionally set an encryption key (16 byte AES key). MUST match both
# on the transmitter and receiver (or be set to None to disable/the default).
# rfm69.encryption_key = b'\x01\x02\x03\x04\x05\x06\x07\x08\x01\x02\x03\x04\x05\x06\x07\x08'
rfm69.encryption_key = None;
rfm69.tx_power=20;

def unpack_uint8(m):
    return struct.unpack('B'*len(m), m)

def send_now():
    rfm69.idle()

    n = datetime.now()
    add_this = [n.second,n.minute,n.hour,n.day,n.month,n.year-2000,n.isoweekday()]
    b_ar = bytearray();
    for x in add_this:
        b_ar += ctypes.c_uint8(x)
    msg_send = b_ar;
    
    for i in range(3):
        rfm69.send(msg_send, flags=2, keep_listening = True);  # Date time return request
        time.sleep(0.05);

    print('SENT:\t\t',unpack_uint8(msg_send))
    # print("Sent!", add_this);


send_now();
while True:
    # send_now();
    packet = None
    packet = rfm69.receive(with_header = True)
    if packet is not None:
        #  = packet
        print('====================================')
        print('RECEIVED:\t',unpack_uint8(packet))

        packet_flag = packet[3]
        print('FLAG:\t',packet_flag)
        if packet_flag == 1:
            send_now();

        if packet_flag == 31:
            if not os.path.exists('packet_dump'):
                pickle.dump(packet, open('packet_dump','wb'));

        # print(packet_flag, prev_packet);
        # packet_text = str(prev_packet[4:], "utf-8")
        # print(packet_text)
    # time.sleep(0.01)

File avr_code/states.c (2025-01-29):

#include "states.h"

    void init_spi() {
        SET_PIN_OUT(DDRC, DDC1);  // SCK
        SET_PIN_OUT(DDRE, DDE3);  // MOSI
        SET_PIN_IN(DDRC, DDC0); // MISO_RFM69
        SET_PIN_HIGH(PORTC, PC0);
        SPCR1= (1<<SPE1) | (1<<MSTR1);  // Enable, Master, f_osc/16
    }
    
    
    void rfm69_reset_state(bool state) {
        SET_PIN_OUT(DDRC, DDC2);
        if (state) {
            SET_PIN_HIGH(PORTC, PC2);
        } else {
            SET_PIN_LOW(PORTC, PC2);
        }
    }

    void led_1_set_state(bool state) {
        SET_PIN_OUT(DDRD, DDD4);
        if (state) {
            SET_PIN_HIGH(PORTD, PD4);
        } else {
            SET_PIN_LOW(PORTD, PD4);
        }
    }

    void led_2_set_state(bool state) {
        SET_PIN_OUT(DDRD, DDD6);
        if (state) {
            SET_PIN_HIGH(PORTD, PD6);
        } else {
            SET_PIN_LOW(PORTD, PD6);
        }
    }

    void led_3_set_state(bool state) {
        SET_PIN_OUT(DDRD, DDD7);
        if (state) {
            SET_PIN_HIGH(PORTD, PD7);
        } else {
            SET_PIN_LOW(PORTD, PD7);
        }
    }

    void ldo_set_state(bool state) {
        SET_PIN_OUT(DDRC, DDC3);
        if (state) {
            SET_PIN_HIGH(PORTC, PC3);
        } else {
            SET_PIN_LOW(PORTC, PC3);
        }
    }

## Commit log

2024-11-25 initial push
    [wheel_counter-CuBottom.gbr, wheel_counter-CuTop.gbr, wheel_counter-EdgeCuts.gbr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]
2024-11-25 added pictures of pcb and schematic
2024-12-18 fix ground
    [wheel_counter.kicad_pcb, wheel_counter.kicad_sch]
2024-12-18 moved to pcb folder
    [wheel_counter-CuBottom.gbr, wheel_counter-CuTop.gbr, wheel_counter-EdgeCuts.gbr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]

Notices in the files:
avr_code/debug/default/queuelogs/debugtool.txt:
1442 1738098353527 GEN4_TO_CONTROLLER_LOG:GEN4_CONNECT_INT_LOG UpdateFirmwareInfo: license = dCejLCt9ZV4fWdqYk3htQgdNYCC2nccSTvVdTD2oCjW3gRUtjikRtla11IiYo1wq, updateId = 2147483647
